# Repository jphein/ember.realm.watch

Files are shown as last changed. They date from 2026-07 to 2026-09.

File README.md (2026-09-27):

# Ember

A local-first voice assistant satellite whose screen is a hearth.

Ember is an ESPHome device on a cheap 2.8" ESP32-S3 touchscreen, wired to a Home
Assistant Assist pipeline that never leaves the LAN. You tap the screen, speak,
and a dragon lying in the coals answers you. The fire's temperature *is* the
state machine — there is no status text, no spinner, no "listening…" label. When
Ember is thinking, the fire draws up into a column. When it speaks, the flames
chase the words. When the backend is unreachable, the coals go grey and the wyrm
goes to sleep.

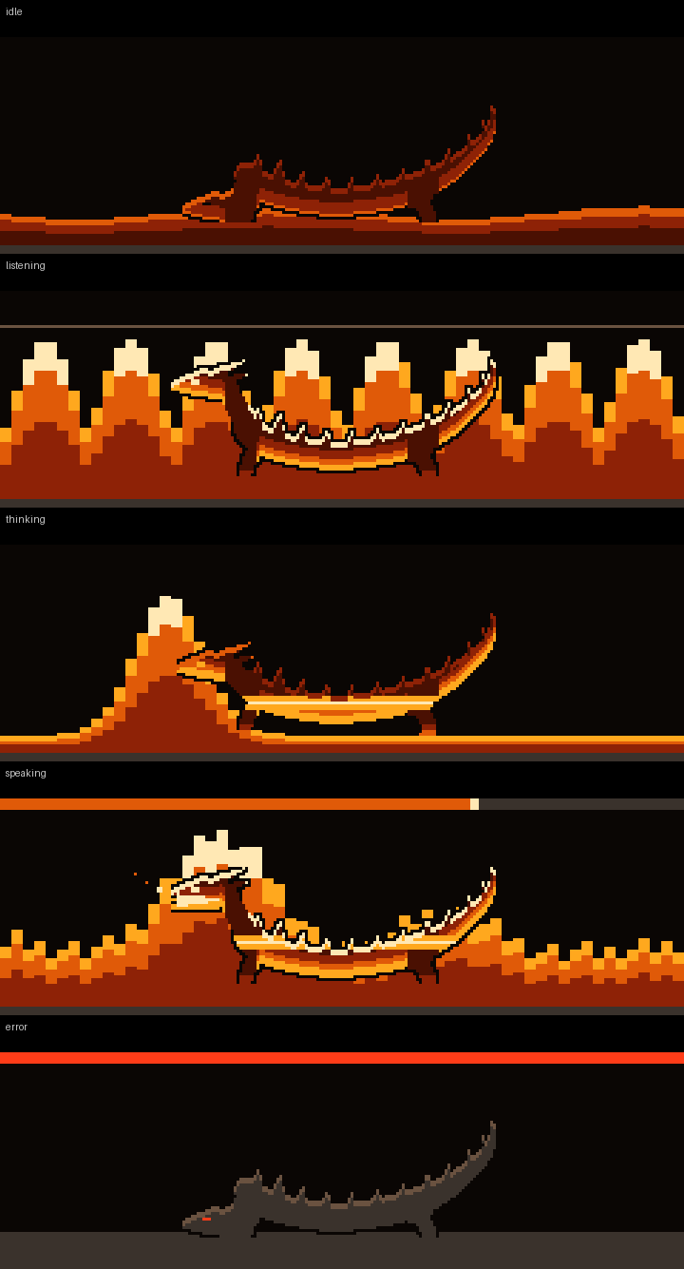
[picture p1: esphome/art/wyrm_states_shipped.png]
The hearth-wyrm across assistant states


*Top to bottom in the file: idle, listening, thinking, speaking, error. The wyrm
is shaded at render time from the live fire palette, so it rides the
ember → amber → gold → white-hot ramp rather than being a baked sprite.
`esphome/art/dragon_in_fire.png` additionally shows the `guttering` and
`daylight` variants.*

---

## The pipeline

Everything runs on the home network. No cloud STT, no cloud LLM, no cloud TTS.

```mermaid
flowchart LR
    T["👆 tap the screen<br/><i>no wake word</i>"] --> E["Ember satellite<br/>ESP32-S3 · ES8311 codec"]
    E -- "16kHz mono mic" --> HA["Home Assistant<br/><i>familiar-ember</i> pipeline"]
    HA -- STT --> V["vosk"]
    V --> X["LiteLLM<br/><b>ubox0</b>:4000<br/><i>not optional</i>"]
    X --> L["Qwen3.6-35B-A3B<br/>llama.cpp on <b>familiar</b>:8091"]
    L -- TTS --> P["Piper<br/>en_GB-cori-medium"]
    P -- "audio stream" --> E
```

| Stage | What serves it |
|---|---|
| Wake | **Touch.** No wake word — deliberate, see below |
| STT | vosk, on the HA host |
| Conversation agent | Qwen3.6-35B-A3B (UD-Q3_K_XL) under llama.cpp on the `familiar` host, port 8091 — reached **through LiteLLM at `ubox0:4000`** |
| TTS | Piper, voice `en_GB-cori-medium` |

> ⚠️ **LiteLLM in that chain looks like needless indirection and is not.** Home Assistant's
> conversation integration cannot send `chat_template_kwargs`, and Qwen3.6 needs them. Point HA
> straight at `familiar:8091` and it connects fine and *behaves wrongly* — the failure lands in
> the model's **output**, not in the connection, which is about the most expensive place for it
> to land. `chat_model: ember` is a LiteLLM alias, not an upstream model name.

**Why touch and not a wake word.** The mic and speaker share a single I2S hub on
this board and there is no AEC. Continuous wake-word listening on shared
hardware fights the playback path for the same peripheral; tap-to-talk sidesteps
the whole class of problem. It also means Ember cannot be triggered from across
the room by the television.

**Warm replies land fast only because the prompt prefix is byte-stable**, letting
llama.cpp reuse its KV cache — a warm turn re-prefills **27 tokens (~0.4s)** out of
6,258. Anything that renders differently between turns truncates the cache there and
re-prefills everything after it, *including the whole conversation history*. Measured
per-request with `prompt eval time`, not wall clock.

Until 2026-07-31 the Environment State block ended in `{{ now() }}` at **microsecond**
precision, so the prompt was byte-unique on every request and every turn paid ~1.0s for
it. Coarsening it to the hour, plus deleting a 1,712-token column of a stringified HA
sentinel, took a warm turn from **1,023 ms → 408 ms** and a cold one from
**6,024 ms → 4,771 ms**. See [`docs/home-assistant.md`](docs/home-assistant.md) §6.3 —
it also records the reasoning that made the earlier fix look complete when it wasn't.

> ✅ **The prompt is now in this repo:**
> [`homeassistant/prompts/ember-system.md.j2`](homeassistant/prompts/ember-system.md.j2),
> deployed with `homeassistant/tools/ember-prompt.py --deploy` (live, no HA restart).
> It previously existed *only* in Home Assistant's `.storage` — untracked and unbackuped,
> which is exactly how the last fix's rationale survived while its numbers rotted.
> `ember_persona.yaml` still supplies only the 255-char live-tweak field that HA's
> `input_text` helper can express.

---

## Three operating modes

**Normal** (speech + chimes) → **No talking** (chimes only) → **Hush** (silent). Monotonic:
progressively quieter, and nothing else varies. Conversation works fully in all three and the
reply still displays on screen — only what leaves the speaker changes.

The gate is the existing 10 ms audio watchdog declining to lift protection it already asserts,
using the display's own speech predicate — so the thing silenced is exactly what the screen
calls speech, and the two cannot drift apart.

> ⚠️ **Hush changed meaning.** It used to mean *"do not listen to me"* and gated the talk
> gesture; it now means *"do not make noise"*. The microphone is unaffected in every mode. If
> you find a dashboard tile, icon or doc implying otherwise — `mdi:microphone-off` is the tell
> — it is stale, and it was true once. The mode select belongs beside Hush wherever Hush
> appears, because Hush as a view can only reach Normal and Hush, so "No talking" would
> otherwise be unreachable from Home Assistant.

`op_mode` is the value that persists; the select and the Hush switch are lambda views over it,
republished at boot. Before that, a device rebooted while quiet came back genuinely Hush with
the select cheerfully reporting "Normal" — found by power-cycling the real device, not by
reading the config.

---

## The two knobs on the device itself

A short press anywhere raises an overlay carrying **both** audio controls, as a pair that reads
*how loudly it speaks / how well it hears*:

| | Range | Readout |
|---|---|---|
| **Volume** | 0–100% in 5% steps, wrapping at the top | 20 hearth stones, one per 5% |
| **Mic gain** | **0–42 dB in 6 dB steps** | **8** hearth stones |

⚠️ **The 6 dB step is the hardware's, not a taste.** The ES8311's ADC PGA is a 3-bit field in
REG16 with exactly eight legal values — 0/6/12/18/24/30/36/42 dB — so nothing between them is
representable, and a continuous slider would report a setting the codec cannot hold. **The stone
count is the hardware's resolution**, which is why the gain row draws eight where volume draws
twenty: the readout must not imply a precision that does not exist. The first lit stone is 0 dB,
because 0 dB is a real setting and not "off". Exposed to Home Assistant as
`number.ember_satellite_mic_gain`.

Setting it writes REG16 directly *as well as* calling `set_mic_gain()`. The setter only assigns
a member — the driver writes the register once, in its own `setup()` — so calling the setter
alone would change nothing until the next boot, which presents exactly like a control that does
not work.

The same asymmetry bit the *restore* path, and it is worth knowing about if you add another
persisted number here: `TemplateNumber::setup()` calls `publish_state()` and never `control()`,
so a restored value never runs its set action. Set 12 dB, reboot, and HA would read 12 while the
PGA sat at the compile-time 36 — **and the one value immune to the bug was the default, which is
what anyone would test with.** There is now a dedicated `on_boot` trigger that pushes the stored
value back *through* the number, so REG16 keeps a single writer, and it was verified by reading
the register back rather than by inference.

Because that asymmetry has now bitten twice, the agreement is measured rather than assumed: a
60 s check reads REG16 back and publishes `sensor.ember_satellite_mic_gain_codec` (what the chip
holds) and `binary_sensor.ember_satellite_mic_gain_desync` (`problem`, ON when they disagree).
**A failed I²C read leaves both untouched rather than reporting a mismatch it cannot see** — so
"no problem reported" is not the same as "verified in sync". Details in
[`docs/home-assistant.md` §6.6](docs/home-assistant.md#66-hearing-mic-gain-and-the-entity-that-can-call-the-dashboard-a-liar).

Two deliberate trades, both reversals of earlier decisions:

- **The fire is hidden while the overlay is open.** Two controls with touch-sized targets do not
  fit in the scroll band alone, so the overlay grew into the flame band. The targets are 56 px
  ≈ 10.3 mm rather than shrinking below the ~9 mm minimum: five seconds of hidden fire beats a
  target you miss. Mode 1 keeping the fire alive had been a deliberate choice, so this reverses
  a decision rather than filling a gap.
- **The gain buttons are silent where the volume buttons chime.** Volume earns a tone because it
  is the one control that cannot be judged visually — the tone *is* the readout. A tone for mic
  gain plays out of the **speaker** and says nothing about how well the **microphone** hears:
  acknowledgement dressed as measurement. The overlay also stops short of the telemetry band, so
  the live dBFS meter stays visible while you adjust — and a chime would be captured by the very
  mic being read and spike the number.

---

## Hardware

An **LCDWIKI/QDtech ES3C28P**, sold as a "Hosyond 2.8in ESP32-S3 Touchscreen".

| | |
|---|---|
| MCU | ESP32-S3 N16R8 — 16MB flash, 8MB octal PSRAM @ 80MHz |
| Display | 240×320 ILI9341V over SPI, driven by `mipi_spi` at 40MHz |
| Touch | FT6336G capacitive |
| Audio | ES8311 codec — analog differential mic, FM8002E BTL amp to an external speaker |
| Extras | microSD slot, WS2812 |

**The pinout in this repo is traced to the manufacturer's schematic, not copied
from community tables.** Several published tables for this board are wrong. The
YAML carries a comment at every non-obvious choice explaining what it is and why
the obvious value fails — those comments are the real documentation for this
project and should not be stripped.

---

## Settings that look like mistakes (and aren't)

Every row here cost real debugging time. Change one only after reading the
comment at its point of use in the YAML.

| Setting | Why it looks wrong but isn't |
|---|---|
| `i2s_din_pin: 6` / `i2s_dout_pin: 8` | The silkscreen names I2S data pins from the *codec's* perspective, so most published tables are inverted. Confirmed four ways, including the vendor's own shipped source. |
| `use_microphone:` omitted | In ESPHome's es8311 driver that flag enables a *PDM digital* mic. This board's mic is analog-differential into MIC1P/MIC1N. |
| `data_rate: 40MHz` | `mipi_spi`'s base ILI9341 model declares no data rate, so it defaults to **10MHz** — which made full frames take 141ms instead of 60ms. |
| GPIO18 left unconfigured | It's CTP_RST. Both a `reset_pin:` and a gpio `output:` broke touch init — ESPHome's `ft63x6` asserts reset then reads the chip ID with zero delay, ignoring the datasheet's `Trsi >= 300ms`. The FT6336G has a 3k internal pull-up, so leaving it alone is correct. |
| `bits_per_sample: 16bit` on the mic | ESPHome's default is **32bit**, which silently mismatches the 16-bit codec and produces a dead mic. This is the actual bug in the only other published config for this board. |
| `channel: left` | Cosmetic. ES8311 REG 0x44 defaults to "ADC + ADC", duplicating the mono ADC into both slots, and no driver writes that register — so left and right are equivalent here. |
| `auto_clear_enabled: false` | Required by the banded partial redraw. `clear()` would dirty every pixel before the lambda even runs, throwing away the whole optimisation. |
| `buffer_duration: 500ms` | The measured fix for choppy playback — a 16s utterance went 45.8% → 100.7% delivered. **Do not lower it.** Not to be confused with `timeout: 500ms`, which is a different knob entirely. |
| `logger: level: DEBUG` | The i2c bus scan prints at CONFIG level, and in ESPHome's ordering CONFIG is *more* verbose than INFO — so `level: INFO` silently hides the scan results. |

Deeper write-ups live alongside this table:

- **[docs/audio-pop.md](docs/audio-pop.md)** — the audible pop on audio start, and
  **how it was resolved.** Read the coda if you touch the audio path. The headline:
  for three rounds the protection sat *behind* the transient it was meant to cover,
  so every A/B test was measuring a knob that fired after the event. The file has
  now been wrong in three distinguishable ways and each error was caught by a
  different method — that chain is deliberately preserved rather than replaced with
  the conclusion. Includes one **accepted** hazard whose symptom is a clipped first
  syllable, not a pop, and which would therefore be blamed on TTS.
- **[docs/enclosure.md](docs/enclosure.md)** — verified board geometry off the vendor
  drawing, the official STEP model, and why **no printable case existed for this board
  anywhere** before this one. The constraint that catches everyone: the touch glass is the
  full 50 mm PCB width, so you cannot clamp the long edges.
- **The YAML's own header** — four architecture notes on why there is no LVGL,
  how the banded partial redraw works, and why the fire renders row-major.
  `>>> Do not "simplify" the fire back into per-column filled_rectangle calls.
  It looks identical and costs several times more. <<<`

### Calibration knobs

These are guesses until measured on *your* hardware, and are marked in-file:

| Knob | What to do |
|---|---|
| `db_floor` / `db_ceil` | Speak normally ~40cm away, watch `sensor.mic_rms`, set floor just under room noise and ceiling just over speech. Too narrow and the meter pins; too wide and it looks dead. |
| `tts_ms_per_char` | Tunes the speaking animation's guess at utterance length. |
| `cpl_body` / `cpl_sm` | Characters-per-line for the two text sizes. |

---

## Chimes

`esphome/sounds/` holds eight 16kHz mono tones plus `generate_chimes.py`, which
produced them. Struck-glass synthesis — inharmonic partials, exponential decay,
4ms raised-cosine attack, warm F-pentatonic so any two are consonant. `error` is
the one deliberate dissonance.

16kHz is not a compromise: the highest partial is 6.79× the fundamental and the
highest fundamental is C5 (523.25Hz) → 3552Hz, comfortably under the 8kHz
Nyquist. Rendering at 44.1kHz and letting the device resample would be strictly
worse — it would put a resampler in an audio path that is deliberately a
straight line.

Regenerate with `python3 esphome/sounds/generate_chimes.py`.

> **`chime_listening` is generated but deliberately never declared.** 1.4s of
> tone out of a speaker sharing one I2S hub with the mic, with no AEC, would
> make HA's VAD end the utterance before you finished speaking. The symptom
> would read as an STT bug and send you looking in entirely the wrong place.
> Don't wire it. The reasoning is repeated at the point of use in the YAML.

---

## The hearth-wyrm

`esphome/art/dragon.py` generates the dragon. It is **not** an ESPHome `image:` —
it emits per-row run-length **spans** as C tables, because:

- The flame band renders row-major and must tile every row exactly once
  (`auto_clear_enabled: false`). An `it.image()` blit would be a second write
  over pixels the fire already wrote; spans composite into the existing
  run-length classifier and preserve write-once.
- Spans carry no colour, so the wyrm is shaded at render time from the live
  fire-temperature palette. It rides the heat ramp, honours the daylight theme,
  and brightens with state. A baked image cannot do any of that.
- The animation is procedural — head lift, glow, travelling rim light — so it
  never visibly loops the way frame-cycled art does.

Deterministic, no RNG. Regenerate with `python3 esphome/art/dragon.py`, which
rewrites `dragon_spans.inc` (pasted into the display lambda) and the preview
PNGs.

### Falsifying a flame-band change before you flash it

`esphome/art/dragon_harness.cpp` compiles the `paint_flame` body against stubs and
checks the two things no compiler can: that every row of the band is written **exactly
once**, and that nothing writes outside `y188..263`. It also reports **runs/frame** and
**px/frame** per assistant state and dumps `wyrm_<state>.ppm` so a change can be looked
at rather than reasoned about.

```bash
g++ -std=gnu++20 -O2 -Wall -Wextra -o /tmp/dh esphome/art/dragon_harness.cpp && /tmp/dh
```

Two things to know before trusting a pass, both explained at length in the file's
header. `FAIL negative-control: …covered 0 times` **is expected** — it is the harness
proving its own tiling check can fail. And the tiling check **cannot** catch an over-tall
`MAXH`: the fuse rows are painted before the fire logic, so a too-tall flame is silently
clipped flat while every pixel remains covered exactly once. If you touch `GRATE` or
`MAXH`, look at the PPM.

It mirrors the lambda in `ember-satellite.yaml`. Change one, change the other — it is
only worth running while it is the same code.

> ⚠️ **It currently is not, and the divergence has been measured: 8 lines, YAML ahead.**
> Seven of them are the two `static_assert`s on `CW` and `NC`; one is `if (silenced) jaw = 0;`.
> That is not accidental drift — the harness's own comment says of those asserts *"a fix belongs
> in the yaml … Flagged to the firmware owner rather than changed here"*, and the fix was made
> there and never brought back. **A deliberate one-way handoff, completed on one side.**
>
> The consequence is worth stating because it is the wrong way round: the guards on `NC`/`CW`
> now live **only in the copy that cannot be host-compiled**, and are **absent from the harness**
> — which is exactly where someone tried `NC = 80` and smashed the stack. *The assert that would
> have caught it at compile time is missing from the only place it could have fired.*
>
> **Half of this is now mechanical.** `esphome/tools/check_art_sync.py` compares the ~700 lines
> of generated span tables by value and fails a commit if they disagree. The ~250 lines of
> painter *logic* stay manual on purpose — the two copies are legitimately different text
> (`it.` stubs against `id(...)`), so a diff would be noise. That half closes when #10 removes
> the duplicate outright.

---

## The enclosure

**There was no printable case for this board.** Not under `ES3C28P`, not under any reseller
alias, not on any model site — because the ES3C28P vents its microphone through the *front*
face, and every CYD-derived shell that physically fits has no port there. For a voice
satellite that is decisive, and it is not a cutout you can add to somebody else's STL from
the outside.

So there is one now. **Four parts, none needing supports**, in [`enclosure/`](enclosure/):

> ✅ **All four are printable.** Two of them were not, earlier, and both fixes are in:
> `ember-stand-base.stl` was **1.40 mm too deep** and could not close the sealed chamber
> (`89001ea` — the plate carried a hardcoded copy of a wall that had since been *derived* and
> moved, and the literal did not follow); and `ember-stand.stl`'s speaker-wire pass was blocked
> by a skin of the tape pad, leaving a 0.40 mm slit where a 1.2–2.0 mm lead has to go
> (`338a900` — clear aperture now **28.69 mm² of 30**, up from 2.37). Details and the
> reprint/relabel notes are in [`enclosure/PRINT-SHEET.md`](enclosure/PRINT-SHEET.md).
>
> ⚠️ **If you printed a back shell before `86748c6`, its button caps are on the wrong
> switches** — the switch identification was inverted when it stopped being a typed literal.
> `ember-front-bezel.stl` has been printed and its dimensions look right, and is unaffected by
> all of the above. Nothing has been assembled yet.

| | |
|---|---|
| `ember-front-bezel.stl` | front face down. Carries the ⌀2.40 mm mic port, the screen window, a debossed honeycomb and the hearth-wyrm |
| `ember-back-shell.stl` | back face down. Two printed-in-place hexagonal button pads on living hinges, 15.00 and 10.00 mm across the flats |
| `ember-stand.stl` | bottom face down. A 15° cradle that **is** the speaker cabinet, with finger scallops reaching the buttons |
| `ember-stand-base.stl` | flat. Closes the chamber |

### The back face has labels now, and they are drawn rather than set

Debossed into the back like everything else on a bed face: **`SD`** beside the card slot,
**`MIC`** beside the relief, **`VOL`** on the large button cap, an **IEC 5009 power symbol** on
the small one, and a **connector strip down each flank** naming the ports behind it. Same depth
as the bezel motif — **three layers**, one named layer count shared by both faces.

> ⚠️ **The set is variant-dependent now, and one label was deleted rather than reworded.** The
> desk shell blocks the `BAT` flank opening; the mobile blocks `BAT` and `SPK`. **A suppressed
> opening suppresses its label** — the rule in the source is *"no label may name an opening that
> is not there"*, and it is enforced by cutting the labels from the same set that cuts the holes,
> so the face cannot name a port that does not exist. Dropped, not re-captioned, because a
> moulded-in name is wayfinding: **an opening with nothing behind it is invisible until someone
> looks, but a label beside solid plastic actively sends a person hunting for a port.** The
> surviving labels keep the positions they were packed into against the *nominal* spans, so
> nothing shifts between variants.

**They are a stroke font, not a typeface, and that is the whole point.** Each glyph is a
centreline path swept at a fixed **0.90 mm** groove width — the same nozzle floor the wyrm mark
asserts. With an outline font the stroke width is a *consequence* you can measure afterwards and
hope about; here it is an **argument**, set directly and checkable. On the button caps that
works out to a stroke/height ratio of **0.19**, heavier than any real font's Bold; on the flat
back, at the larger size, it is **0.14**.

⚠️ **Two sizes, and the split is forced rather than stylistic.** The large cap is 13.27 mm
across the flats, which caps a three-letter label at **h 3.80**. The flat back has room for
**h 5.50**, and `SD` *needs* it: at **h 5.10 the S's upper counter pinches to 0.843 mm** against
the 0.90 floor. **Shrinking a glyph does not shrink it uniformly** — the stroke is pinned at the
nozzle and everything else scales, so it is the **counters** that get eaten first. Using the cap
size everywhere would have put an unprintable `S` on the part; using the flat size everywhere
would not fit on the cap.

The power symbol's gap is **derived, not styled**: the material between a ring end and the bar is
`R·sin(gap/2) − 0.90`, so clearing the 0.90 floor needs **≥ 83.6°**, and it ships at 84. **A
conventional 60° break measures 0.45 mm and prints as a closed ring with a smudge in it.**

> ⚠️ **Every label is mirrored in X, and this is the one that ships backwards if nobody writes
> it down.** The back face is seen from **−Z**. For a viewer there with +Y up, their right-hand
> direction is `forward × up = (0,0,1) × (0,1,0) = (−1,0,0)` — so **model +X runs to their
> left.** Glyphs are authored in reading space and mirrored on placement. The wyrm mark on the
> front bezel is *also* mirrored, but for art-direction reasons, so **it is not precedent and
> copying its sign would prove nothing.** `enclosure/tools/slice_svg.py` applies the same mapping
> independently, so slicing the exported STL is a genuine check: if the sign were wrong the text
> would come out backwards there.

**`ember_case.py` is the artifact; the STLs are output** — regenerate them, don't hand-edit
them. It is build123d on OpenCASCADE, which is the point: the vendor's STEP model can be
*imported* and every part checked against it by boolean subtraction, so every board dimension
is measured rather than transcribed from a datasheet table.

```bash
cd enclosure
python3 -m venv cadenv && ./cadenv/bin/pip install -r tools/requirements.txt
./cadenv/bin/python ember_case.py            # STLs + clearance check + geometry asserts
./cadenv/bin/python tools/make_renders.py    # the site figures
```

- **[`enclosure/README.md`](enclosure/README.md)** — building from a fresh clone, what the two
  kinds of check actually do, and the parameters most likely to need a second print.
- **[`enclosure/PRINT-SHEET.md`](enclosure/PRINT-SHEET.md)** — orientations, slicer settings,
  fasteners, assembly order. Also served as a page at
  [`docs/print-sheet.html`](docs/print-sheet.html), because that is the one document you read
  while a printer is running.

> **The two lessons this part of the project keeps teaching.** *A test that cannot fail is not
> a test* — the clearance checker returned a confident `CLEAR` for a while because the vendor
> solid and the parts were in disjoint coordinate frames, so every boolean returned empty.
> There is now a permanent self-test that deliberately sinks a bezel into the board and must
> report **1512.804 mm³** (the figure tracks bezel geometry — it was 1467.842 until the #41
> boss flare; re-recorded 2026-08-25, see `enclosure/README.md`). And *a boolean cannot see
> occlusion* — the stand covered a fifth of
> the screen, then buried both buttons, without ever intersecting anything. Both were found by
> rendering the thing and looking at it.
>
> The first lesson landed a second time, on the mesh check. The repo asserted *"all parts
> watertight, 0 non-manifold edges"* on a check that imported each STL with build123d and
> counted boundary edges — and `import_stl` returns a single `Face` with **zero edges and zero
> volume**, so the count was zero because there was nothing to count. The true figures, printed
> on every build: **three parts watertight; `ember-front-bezel` carries 3 non-manifold edges**
> in a valid solid with zero boundary edges, a coplanar-seam artefact from the wyrm mark's
> stacked row-spans that slicers repair. It is recorded as a number rather than a threshold, and
> raising it to make a build pass is explicitly forbidden.

---

## The mobile variant — one 18650, and the front never changes

There is a **battery build**, and it is a *backpack rather than a redesign*:
[`enclosure/ember_mobile_case.py`](enclosure/ember_mobile_case.py), issue
[#44](https://github.com/jphein/ember.realm.watch/issues/44). The bezel is the desk case's part,
unmodified — same STL, same four M3×12, same 5.34 mm of thread — and the board is held by the
**same joint at the same plane**. Two parts are new.

> ⚠️ **Verified in CAD, nothing completed, nothing wired.** Both parts pass every check the desk
> parts do — watertight, **0 boundary and 0 non-manifold edges**, **0.000 mm³** against the
> vendor board solid, with displaced controls at 1261.0 / 199.1 / 1884.8 mm³ so the probe is
> known to be *able* to fail. That is a geometry result. The cell is a phantom, and whether the
> cover's top edge gaps is a question only a test print answers.
>
> ✅ **The protection strip is fully measured now** — 21.50 × 4.50 × 2.50 plus a 90.00 flat
> assembly, all JP-calipered. It was the longest-standing estimate in the design and there are no
> placeholders left.
>
> One cover print was **started and cancelled at 2 %** — the strip's length had gone in as a
> 20.0 mm eyeball estimate carrying ±2, and at 20.0 the locating ribs sat **1.5 mm too close
> together for a 21 mm strip to drop between them**. Re-measured at **21.50**. *(Those ribs no
> longer exist — the strip has since moved out of the chin band entirely, and the pocket, its ribs
> and its detents went with it. The print was still cancelled for the right reason.)* The
> flag on that estimate is why the cancel cost 2 % rather than a whole part; the lesson is that a
> number carrying ±2 was allowed to set a feature whose clearance is smaller than ±2.

| | |
|---|---|
| `ember-mobile-midframe.stl` | back face down. The old back shell **plus features and (almost) nothing removed** — brow, speaker bond plateau, driver locating groove, cell-lead pass, two screw bosses, a +Y cooling field. It *does* drop two hex rows, at the chin screw — see below |
| `ember-mobile-back.stl` | **outer** face down. The cell trough, the spring and contact pockets, the speaker grille, the failure vent, the protection pocket |
| `ember-front-bezel.stl` | unchanged — reused bit-identical |

| | Mobile | Desk |
|---|---|---|
| Envelope | **55.90 × 91.90 × 39.00 mm** — *Y identical to the desk case* | 55.90 × 91.90 × 17.40 mm |
| Cell | 1 × **bare flat-top 18650**, user-swappable | — |
| Charge | onboard TP4054, 290 mA → **15.8 h** | — |
| Access | **2 × M3×22** on one lane + the cover's box section | — |

**Width cannot move** (the bezel didn't) — and after three revisions of *not* closing, **length no
longer grows either.** `MOB_OY1 == OY1 == 88.95`, asserted exactly: the backpack is the desk slab's
footprint with depth behind it and nothing else.

> **JP: "no litle lip in backpack figure it out pls."**

It had been 3.05 mm longer, then 1.32, then 1.73 — each for a reason that was correct at the time
(the coil spring; then the corner fillet the coil had been paying for by accident; then the strip's
own housing). What closed it was **moving the conflict instead of reshaping around it**: `CELL_WALL_X`
given its own name, the divider to 1.60, the driver nudged 1.078 to land *centred*, and a plan-corner
roll of **0.30** — which is not a chosen radius but the **seat guarantee**, since above 0.30 a cell
with no roll of its own cannot seat. JP suggested ~0.5 from the render; **the bound won.**

The assert guarding it fails in the vocabulary the requirement was given in: if either half breaks,
the message says **"the lip is back"** in those words.

The cover **deliberately stops short of the chin** so a battery door cannot bury the only usable
button or the USB-C socket — a *reachability* constraint, which is the class of fault no
clearance check sees and which this project has already filed once.

The interior closes exactly: **51.50 = 19.40 bore + 2.00 divider + 30.10 rim**, where that
divider was **one wall doing two jobs** — the cell trough's inboard wall *and* the sealed speaker
chamber's −X wall — because two walls do not fit.

> ⚠️ **That wall has now held six different positions**, ending whole again plus a **double separator
> wall JP designed himself** — a partial wall plus a stepped full wall, 0.90 thinning to 0.50 beside
> the strip. Each of the six has a stated reason and a measurement behind it; a design that moves six
> times under measurement is not indecisive, it is one where nobody was allowed to guess.
>
> ⚠️ **And a correction this README carried:** it reported one opening at 584 mm². There were two —
> the check was printing the divider's *cross-section* (39 mm²) where the opening is the face the wall
> *vacated* (869 mm²), **off by 22× in the one number the owner judges the trade by.** *A wrong area is
> worse than no area, because it gets trusted.* Both are closed again now; the −X opening measures
> 0.000. Details in [`docs/enclosure-mobile.md`](docs/enclosure-mobile.md) §7c.
>
> The front-air cost is real and it moved: **−11.1 %**, not the −1.2 % this file quoted for three
> revisions — the separator wall and the driver's re-measured 27.5 width both take volume out.

### Three findings worth reading even if you never print it

**⛔ The board has no protection IC at all, and now that is not a guess.** It was searched for —
`DW01`, `FS312`, `8205`, BMS, over-discharge — and then settled against the
[vendor schematic](docs/vendor/ES3C28P_Schematic.pdf): the battery area is exactly two blocks,
charge management and a level divider. `BAT` goes **straight to the cell**. And *"it browns out
first"* is the wrong reading — with a bare cell the only floor is the regulator's dropout, so the
device stops working around 3.4 V and **keeps draining ~9 µA through that divider**. A cell left
flat goes to zero and does not come back. Hence the 1S protection-strip pocket, which is
**required equipment rather than a nicety**.

**⚠️ A flat-top cell carries no polarity information, so the keying had to be deleted.** The
previous revision had real mechanical reverse-insertion protection — a ⌀7.00 aperture that a
protected cell's *raised* button passes and a flat can-face does not, blocking a reversed cell by
144.6 mm³. But JP uses bare cells only, and on a bare flat-top **both ends are the same shape**:
any aperture that stops a reversed cell stops a correct one. It is not a matter of a cleverer
profile — *the information is not present in the geometry*, and left in, the feature would have
rejected the only cells its owner has. It was removed rather than commented out. What replaces it
is `+`/`−` debossed into the cell bay — deliberately **not** mirrored positions, because one end
has a nickel leaf in front of it and the other does not. **That is weaker, and it is not
going to be called protection.**

**A vent with no straight line through it.** A lithium cell in a sealed plastic box is the one
thing here that can hurt someone. The bay vents through **four labyrinth units** in a side wall —
each an inner slot and an outer slot offset by a 1.20 mm rib, joined by a 0.60 mm band, leaving
0.80 mm of skin standing at each face. Throat **16.56 mm²** against an assumed 9.42 mm² of vent
port on the cell's own cap; worst outer slot **36 % obstructed**, with a control on a
deliberately drilled wall at 0.0 %. Every cut runs its long axis along the *print* Z, which is
why the vent is in a side wall and not the floor.

> **And that check was wrong first, in the most dangerous possible way.** The throat probe swept
> half a millimetre of open air outside the part and half a millimetre of bay interior, and read
> **52.80 mm²** — 3× the analytic figure. Worse: **with the connecting band deleted entirely it
> would still have read 36.00 and passed.** An assert that cannot fail, inside the check written
> to retire the design's biggest risk. It surfaced only because the measured number beat the
> calculated one by 3×, which is a defect signal and not a win. Standing rule that came out of
> it: *a probe's extent is the feature's extent — a margin "to be safe" is not safe.*

There is also a **WS2812 glow window** (two hex cells behind a 0.80 mm membrane, cut from the
wall's inner face so the outside stays flat and the hexes are invisible until lit), whose size
was pinned this week by a **cross-part regression**: it was written as "the same cell as the
grille", and when the *desk stand's* grille was re-parameterised 4.50 → 4.75 mm for printable
webs, this window **in a different part** silently inherited the change and stopped fitting its
cavity band. The export gate refused to write the STL. *A window's size is set by the band it
lives in, not by another part's lattice.*

### ⚠️ It did not dock, and the *stand* is what had to change

The backpack is meant to sit in the desk stand. **It didn't fit** — and nothing had noticed,
because **the check for it had never actually executed.** Its first real run reported
**121.784 mm³** of interference, cover against the stand's rear top edge, **pre-existing on `main`
and worse there.** A check that has never fired looks exactly like a check that passes.

The cover could not be the fix: the interference is **mid-height on its chin end face and full
width**, not a corner a bevel could shave, and its 2.20 mm wall with the leaf's kerf behind can
give up 0.60 and no more. So the stand takes a **13.00 × 4.40 relief** on its rear top edge, sized
by **bisection against the real docked stack** (96.6 → 28.8 → 7.8 → **0.000 mm³**). The check is a
hard zero now. That is 250 mm³ off a part of over 100 cm³.

> ⭐ **The part that had to give was the one whose assumption was oldest.** The stand's slot was cut
> for a 17.40 mm slab, before a backpack existed to be docked into it, and every later part
> inherited that opening as if it were a fact about the world. It was a fact about a decision.
> *When two parts cannot both be right, change the one carrying the stalest premise — not the
> newest one.*

⚠️ **The stand is at r5 and needs reprinting if you dock a backpack.** Desk-only builds are
unaffected in geometry.

```bash
cd enclosure
./cadenv/bin/python ember_mobile_case.py           # both STLs + 17 checks; writes nothing on failure
./cadenv/bin/python tools/make_mobile_renders.py   # the site figures -> site/renders/
```

- **[`docs/enclosure-mobile.md`](docs/enclosure-mobile.md)** — the build reference: BOM, assembly
  order, wiring, print notes, the full measured table, and every soft number flagged as soft.
- **[`docs/vendor/README.md`](docs/vendor/README.md)** — the archived schematic and what it settles.

**The deliberate trade, for the record.** An in-case TP4056 would charge in 4.6 h instead of
15.8, and it **does not fit** — the free compartment is 30.10 × 13.40 against the module's
17.00 mm short axis, and its phantom is kept in the file so the boolean reports **299 mm³ of
interference** every run rather than a comment claiming as much. Restoring it costs the 5.90 mm
that switching to bare cells saved, which is the same length the protection strip now occupies.
The case stays as short as it is: with bare cells the missing protection is the sharper gap, and removable
cells can be fast-charged in an external bay charger. That **reversed** an earlier decision, and
it is recorded rather than quietly absorbed.

> **The largest unresolved risk is thermal, not mechanical.** Most of the rear vent field is
> refilled by the speaker's bond plateau, and what survives vents into a **closed** compartment
> rather than to open air — compartment → remaining hexes → board cavity → side channels →
> outside. The desk case vents straight to the room. It is flagged rather than "fixed" with
> invented vent geometry.

---

## Repository layout

```
esphome/
  ember-satellite.yaml       the device. ~3700 lines, and the comments are the docs
  secrets.yaml.example       copy to secrets.yaml — three keys, never committed
  sounds/                    8 chime WAVs + generate_chimes.py
  art/                       dragon.py, dragon_spans.inc, preview PNGs
                             dragon_harness.cpp — host falsifier for the flame band
homeassistant/
  packages/
    ember_backend_health.yaml  is the local LLM actually reachable?
    ember_persona.yaml         live persona tweak field, editable from HA
    ember_announce.yaml        script.ember_announce — the right herald
  dashboards/
    ember-hearth.dashboard.json  the Ember control panel (lovelace)
  tools/
    build_ember_dashboard.py     authoritative regen path for the dashboard
    deploy-ha.sh                 push packages to the HA VM + reload
enclosure/
  ember_case.py                THE ARTIFACT — build123d; the STLs are its output
  ember_mobile_case.py         the battery variant; imports every number from above
  ember-*.stl                  six printable parts, regenerated not hand-edited
  PRINT-SHEET.md               orientations, slicer settings, assembly order
                               (desk parts only — see docs/enclosure-mobile.md §11)
  README.md                    building from a fresh clone; what the checks do
  tools/make_renders.py        the desk figures -> site/renders/
  tools/make_mobile_renders.py the mobile figures -> site/renders/
  tools/svg_util.py            sections, projection, self-measuring dimensions
  cadenv/                      the whole CAD toolchain, gitignored AND stignored
site/                        SOURCES for the project site
  index.src.html               hand-edit this
  build.py                     -> docs/, inlining art and copying chimes
  build_print_sheet.py         enclosure/PRINT-SHEET.md -> docs/print-sheet.html
  renders/                     enclosure figures, GENERATED by make_renders.py
  ember-art-web/og_card.py     regenerates the social preview card, and refuses
                               to ship a known-wrong engine name
docs/                        the GitHub Pages root
  index.html                   GENERATED by site/build.py; do NOT hand-edit
  print-sheet.html             GENERATED from enclosure/PRINT-SHEET.md
  assets/                      chimes + og card
  home-assistant.md            the full HA-side guide
  audio-pop.md                 the pop analysis + how it was resolved
  enclosure.md                 board geometry, and the case survey that found none
  enclosure-mobile.md          the battery variant: BOM, assembly, measured table
  vendor/                      the archived ES3C28P schematic + what it settles
  verification.md              the running log of claims that outran their evidence
  version.json                 realm-sigil stamp
```

> `docs/index.html` is **generated**. Edit `site/index.src.html` and re-run
> `python3 site/build.py`. Hand edits to `docs/index.html` are destroyed silently by
> the next build.
>
> `./build-sigil.sh` writes only `docs/version.json` and touches nothing else, so the
> two commands write disjoint files and can be run in either order. See
> [docs/README.md](docs/README.md) for why that wasn't always true.

---

## Build and flash

Requires ESPHome. The config declares `min_version: 2025.11.0` and is verified
against **2026.7.2**.

```bash
cd esphome
cp secrets.yaml.example secrets.yaml   # then fill in the three keys
esphome compile ember-satellite.yaml
esphome upload  ember-satellite.yaml --device ember-satellite.local   # OTA
esphome logs    ember-satellite.yaml --device ember-satellite.local
```

> ⚠️ **`esphome config` is not a build check.** It validates YAML — schema, pins,
> substitutions, jinja — and **never builds the lambdas**. A config with unambiguous
> C++ errors in them returns `Configuration is valid!` and exit 0. Worse, the dump
> **echoes the broken lambda source back at you verbatim**, so it prints the C++ and
> then declares the configuration valid, which reads as though it examined what it
> printed. It round-tripped it as an opaque string. **Use `esphome compile`** — no
> device needed, and it is the step that builds the C++.
>
> ⚠️ **`esphome upload` does NOT compile either.** It ships whatever is already in
> `.esphome/build/`, silently. Always `esphome compile` first, or use `esphome
> run` which does both. Two debugging rounds were lost to flashing a stale
> binary whose symptoms reproduced to the millisecond.
>
> **These two are neighbours and fail the same way**: each is a step you would
> reasonably read as "check it before flashing", and neither compiles anything. Between
> them, a C++ error can survive a validation *and* a flash and first appear as a device
> that does not boot.

Compiling on a workstation is roughly 5× faster than building on the HA host.

First flash has to be over USB (`--device /dev/ttyACM0`); everything after that
can be OTA.

### Verifying the banded redraw

The one test that matters after touching the display code. The YAML's `logger:`
block carries the exact swap to make — it turns on the per-band frame accounting
so you can confirm at most one band repaints per frame.

---

## Home Assistant side

**[docs/home-assistant.md](docs/home-assistant.md) is the full guide** —
prerequisites, deploy, verification, the pipeline internals, and troubleshooting
ordered by how much time each fault costs you. Read it before a fresh install;
roughly half of Ember's HA-side configuration is *not* expressible as a repo file
(add-ons, the conversation agent entry, the Assist pipeline) and that document
enumerates every manual step.

The files under `homeassistant/` are the version-controlled source for config that
lives on the HA host. **This repo is the source of truth**; `deploy-ha.sh` copies
packages to the VM and reloads only the domains that changed:

```bash
homeassistant/tools/deploy-ha.sh --check     # validate only, no SSH needed
homeassistant/tools/deploy-ha.sh --dry-run   # show what would change
homeassistant/tools/deploy-ha.sh             # deploy all three + reload
```

> ⚠️ **The API host and the SSH host are different machines.** The public name
> resolves to the reverse proxy, not the HA VM. SSH there succeeds, `sudo tee`
> writes the packages onto the *proxy*, reports success, and changes nothing in
> Home Assistant. `deploy-ha.sh` keeps the two names separate deliberately and says
> why in a comment — don't "tidy" it. Override with `HA_SSH_HOST` and `HA_API`.

- **`packages/*.yaml`** → drop into your HA `packages/` directory. Reloadable
  without a full restart via `rest.reload` / `script.reload` where applicable.
- **`dashboards/ember-hearth.dashboard.json`** → pushed by
  `tools/build_ember_dashboard.py`, which creates the top-level dashboard if
  absent and then saves the config over the WebSocket API. **The repo is the
  source of truth**; a regen deliberately clobbers UI edits, which is the point.

```bash
export HA_WS="wss://ha.example.com/api/websocket"   # only if the default is wrong for you
python3 homeassistant/tools/build_ember_dashboard.py --dry   # print, touch nothing
python3 homeassistant/tools/build_ember_dashboard.py         # create + save
```

> ⚠️ **`HA_WS` wants the name on the TLS certificate — usually your edge/proxy host, and
> usually with no port.** This example used to read `wss://your-ho…:8123/api/websocket`, and
> that shape fails three ways in a row, each masking the next: `homeassistant.local` often
> does not resolve at all; the LAN name may resolve but serve **HTTPS** on 8123, so plain
> `ws://` reports *"did not receive a valid HTTP response"* — which reads as a protocol fault
> when it is a scheme mismatch; and `wss://<lan-name>:8123` then fails certificate
> verification, because the cert is issued for the public name. The default in the script is
> the edge name for exactly this reason, and it is a hostname, never an IP.
>
> This is also **not** the SSH host. `deploy-ha.sh` copies files to the VM; this script talks
> to the API through the proxy. They are different machines and each tool already uses the
> right one.

Auth resolves in order: `HA_TOKEN` env var → `~/.cache/ha-token-tmp` → a
password-manager lookup. The script needs `websockets` (`pip install websockets`).

Notes that will bite otherwise:

- HA requires a custom dashboard `url_path` to contain a hyphen. Hence
  `ember-hearth`.
- Hand-edit the JSON, and keep `indent=1, ensure_ascii=True` if you ever rewrite
  it programmatically. Any other setting re-encodes every non-ASCII glyph and
  buries a one-tile change in a 300-line diff. This file is ~40% ember-ramp
  glyphs, so it matters more here than usual.
- Card inventory is 100% HA-core card types. The only non-core dependency is
  **card-mod** for the ember palette, and it only injects CSS — if it fails to
  load the cards still render, just unstyled.
- The pipeline → agent/stt/tts/voice tables inside the markdown cards are a
  snapshot taken 2026-07-29. Refresh them if you add or rename pipelines.
- Address the backend host **by hostname**. `familiar.lan` from the HA VM (HAOS
  does not resolve the bare name), `familiar` from a workstation. Never the IP:
  it moved once and the stale literal cost a debugging session.
- Polling the backend does **not** keep it awake, and does not wake it either.
  The host's autosuspend decides on whether the inference lane is loaded, not on
  network traffic. So a failed poll is a true signal, not an artefact of
  measuring.

### Announcements

Always go through `script.ember_announce`, never `assist_satellite.announce`
directly. The raw service sends a `preannounce_media_id` unless told not to, and
Ember *also* plays its own local chime when an announcement arrives — so the
default gives you HA's generic blip followed by Ember's chime, back to back,
which sounds exactly like a firmware bug. `preannounce: false` is not optional,
and the script exists so no future automation has to remember that.

---

## Versioning

The project site carries a [realm-sigil](https://github.com/jphein/realm-sigil)
version stamp — `docs/version.json` plus a `<meta name="realm-version">` tag in
the page, generated from the git hash by `build-sigil.sh`.

The firmware itself is versioned by ESPHome and reported to Home Assistant as the
device's own version. It has no HTTP surface, so it has no `/api/version`
endpoint and does not need one.

---

## Provenance

Ember started life inside a Home Assistant configuration repo and was extracted
into this one with `git filter-repo`, preserving **every** commit that touched it —
`git log -- esphome/ember-satellite.yaml` is the real answer, and it goes back to
the file's first appearance.

Those commit messages are load-bearing. Several are the only record of *why* a
non-obvious setting is what it is, and more than one documents a conclusion that a
later commit overturned. `git log --follow` works across the extraction, including
through `esphome/README.md` → `README.md`.

Read them in order if you are about to change the touch or audio paths. The last
four in particular are a chain of corrections, each one fixing a bug the previous
fix revealed — a debounce that re-armed and cancelled deliberate presses, a
completion chime that destroyed the reply it was announcing, a 250ms timeout
measured off a single fast sample. The final shape (dispatch on release, never
preempt audio that is playing) only makes sense against that history.

## License

AGPL-3.0-or-later © 2026 Jeffrey Pine Hein. See [LICENSE](LICENSE).

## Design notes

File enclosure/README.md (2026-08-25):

# enclosure — building it from source

`ember_case.py` is the artifact. **The STLs are output** — regenerate them, don't hand-edit
them.

## Setup

```bash
python3 -m venv cadenv
./cadenv/bin/pip install -r tools/requirements.txt
```

Nothing CAD-capable is installed system-wide on the workstation this was built on
(no OpenSCAD, no FreeCAD, no slicer), so the venv is the whole toolchain.

**Why build123d rather than OpenSCAD:** it sits on OpenCASCADE, which is what produced the
vendor's STEP file — so the board solid can be *imported* and clearances checked by boolean
subtraction. OpenSCAD cannot read STEP, which would mean hand-typing twenty-odd dimensions.
Every board number in `ember_case.py` is measured off the STEP, with a `VERIFIED{}` dict
recording the provenance of each.

## The vendor board model

Not committed — 17.7 MB of generated CAD does not belong in git. Download it to
`../ES3C28P_3D/ES3C28P_3D.step`:

<https://www.lcdwiki.com/res/ES3C28P/ES3C28P_3D.zip>

Verified genuine: an Altium → OpenCASCADE export, `PRODUCT('PCB','PCB')`, with connectors
modelled by part number. Without it the STLs still build; the clearance check is skipped.

## Build

```bash
./cadenv/bin/python ember_case.py      # STLs + clearance check + geometry asserts
./cadenv/bin/python tools/make_renders.py   # the figures used on the site
./cadenv/bin/python ember_plug_cradle.py    # the captive-USB-C well insert (#49) + its checks
./cadenv/bin/python tools/make_cradle_renders.py   # its two figures
```

⚠️ `ember_plug_cradle.py` builds against **assumed plug-head dimensions** — see the ⛔ on its
row in [PRINT-SHEET.md](PRINT-SHEET.md) before printing it.

## What the checks actually do — and why there are two kinds

**`--- BOOLEAN CLEARANCE CHECK ---`** subtracts each part against the imported board solid
and reports the interference volume. Expect `0.000 mm³`.

⚠️ **It once returned a confident `CLEAR` that meant nothing.** The vendor STEP lives in its
own coordinate frame (X −52.75..−2.75) while the parts are in board coords, so the two never
overlapped in space and *every* boolean returned empty. It surfaced only because a bezel was
deliberately sunk 2 mm into the board and the detector **still** said `0.000`. There is now a
permanent self-test doing exactly that, and it must report **1512.804 mm³**. If it ever
reports zero, the checker is broken — not the parts.

> ⚠️ **That figure tracks the bezel's geometry and moved once without being re-recorded**: it
> was captured as 1467.842 on 2026-07-30, the #41 boss flare (2026-08-06) changed the bezel's
> volume near the board, and every doc kept quoting the old number. Re-recorded at 1512.804 on
> 2026-08-25 (observed during the #48 rebuild — whose own change, the 0.96 front-face deboss,
> provably cannot move it: sunk 2 mm, the deboss band spans z 4.74–5.70 and the board tops out
> at 4.30). The code's own gate is `> 1.0 mm³`; the recorded figure exists so a *different*
> value is noticed, so if you change the bezel and it moves, update it here **in the same
> commit**.

**`--- MESH CHECK ---`** is arithmetic on the exported triangles: every undirected edge shared
by exactly two, every directed edge appearing once. Current output, re-derived from the
committed STLs:

| part | triangles | boundary edges | non-manifold |
|---|---|---|---|
| `ember-front-bezel` | 10 162 | 0 | **3** (known, see below) |
| `ember-back-shell` | 12 628 | 0 | 0 — watertight |
| `ember-stand` | 3 268 | 0 | 0 — watertight |
| `ember-stand-base` | 12 | 0 | 0 — watertight |

⚠️ **This repo used to claim "all parts watertight, 0 non-manifold edges", and that claim was
worthless.** The check behind it imported each STL with build123d and counted boundary edges —
but `import_stl` returns a **single `Face` with zero edges and zero volume**, so the count was
0 because there was nothing to count. A perfect result about an empty object, over four parts
of wildly different complexity, reported instantly. Measured properly, the bezel had 9
non-manifold and 22 mis-oriented edges.

**Three parts are genuinely watertight. The bezel carries 3 non-manifold edges, in a solid that
is otherwise valid** — `is_valid` true, exactly one solid, zero boundary edges — and the
count is 3 whether the union is built in 2D or 3D, at tessellation tolerances from 0.1 to
0.001, before or after `clean()`. It is a mesher artefact at coplanar face seams, not a hole:
there is nothing for material to leak through, and every slicer tested repairs it silently.
The cause is the mark's 104 stacked row-spans touching edge-to-edge where one row's run ends
where the next begins; inflating each span by 20 µm took 9 to 3.

It is recorded as a **number, not a threshold** — `KNOWN_NONMANIFOLD = {"ember-front-bezel": 3}`.
A boundary edge fails the build outright; exceeding the baseline fails it too. **Do not raise
the baseline to make a build pass.**

**`[geometry]`** asserts the things a boolean is structurally blind to, because nothing
intersects:

| assert | why it exists |
|---|---|
| stand must not occlude the visible area | it once covered **19.5% of the screen** — the stand wasn't colliding with it, just in front of it |
| ≥16 mm under the slab | there was 6 mm, and a USB-C plug needs ~18–20. Missed because no figure ever showed a cable |
| ≥12 mm slot engagement | the fix for the first two is raising the slot floor, and that trades away retention |
| a fingertip must reach each button cap while docked | both caps were **completely buried** by the stand. Probed as a 6 × 6 × 4 mm patch, not a centreline sample — a point would pass straight through a slot a finger cannot enter |
| ≥3 mm of stand wall behind the finger scallops | the fix for the above is removing wall, and that is the thing it trades against |
| **the back shell must be exactly 1 solid** | the only assert here that tests the thing rather than a proxy. If the hinge-tab arithmetic is wrong the slot ring closes and a pad is not a printed-in-place hinge but a loose hexagon that falls out on the bed. A dimension check cannot see that, and neither can the clearance check — **a severed pad collides with nothing** |
| per-region bezel cell counts, never a total | the first honeycomb run put 75 cells in the chin and **zero** on the rails, and the assert passed because it read `count ≥ 60`. A total absorbed a complete regional absence |
| the wyrm mark must be **exactly 1 component** | it shipped as **two** — head floating 1.215 mm above the shoulders with no neck — while the minimum-feature check read a healthy 1.23 mm. **A gap is not a thin feature**: morphological opening measures where material *exists* and is blind to material that is *absent*, so every instrument was green about a logo that had come apart |
| the mark must clear the mic flare and fit the brow with real slack | it previously occupied 11.25 of 11.29 mm of usable brow and sat 1.21 mm from a 1.20 mm keepout. Both true, both luck, and neither would have survived the mark changing size. It now has 11.69 mm of brow and 0.44 mm of slack, against a 0.30 mm floor |
| **the wyrm-and-port group must centre on the face** | the one assert on this face that is not a clearance, and it exists because **a clearance is satisfied by any amount of slack in the wrong place**. Ink 7.700–33.351 plus the mic flare's right edge at 42.300 centres on **x 25.000**, the exact face centreline. Nothing else here would have noticed it drift |
| **mesh arithmetic on the exported STLs** | the check this replaced *could not fail* — see the mesh row in the table below |

**A test that measures interference cannot find occlusion**, and *"does it collide"* and
*"can you get at it"* are different questions — passing the first says nothing about the
second. Every fault above was caught by rendering the thing and looking at it, which is five
for five in this project on defects invisible in correct-looking source.

## Parameters most likely to need changing

| | |
|---|---|
| `DRIVER_W/H/R/T` | the speaker. Currently a 40 × 27 × 10 mm **sealed-back module** with tape on its back |
| `HINGE_L_BOOT / HINGE_L_RESET` | 1.20 / 2.00 — the thinned-flexure length, **and the correct knob for button feel.** Longer is softer *and* safer |
| `HINGE_T = 0.90` | ⚠️ not the feel knob. Strain is `(t/2)·θ/L` and θ is fixed by pip travel over the pip's arm, so **thickening a hinge moves it toward fracture**, not toward a firmer press. Asserted at ≤2.0% — the threshold was tightened from 2.5% when the thumb-sized caps made 2.5% an inheritance from a worse version of the part |
| `BTN_R_BIG / BTN_R_SMALL` | the hex caps, **8.6603 and 5.7735 mm circumradius — 15.00 and 10.00 mm across the flats.** Thumb-sized, and the reason is strain rather than taste: a bigger hex puts the hinge further from the pip, so θ falls with it. **Not free choices**: pinned between the island's bottom edge (below y=0.80 it cuts the shell's bottom wall) and the slot-and-hinge reach, which must clear the back hex field at `HEX_FIELD_Y0` (19.00) with 0.80 mm to spare. A flat-top hex spans `R·√3` in Y |
| `CAP_CX_BOOT / CAP_CX_RESET` | 33.05 / 14.51 — the island centres, which are **not** the switch coordinates (36.58 / 13.45). A 17.32 mm island centred on the switch would eat into the M3 countersink, so the islands are offset off-switch and the pip reaches across |
| `PIP_D = 3.00` | the pip that reaches the plunger. It was 4.00, and shrinking it is what made the offset islands placeable — the island narrows toward its bottom flat, exactly where the pip sits, so a 4.00 mm pip left a 0.40 mm window of legal island X. That is not a tolerance, it is a hope |
| `DEBOSS_BIG / DEBOSS_SMALL` | 0.90 / 0.50. Deliberately **unequal**, so a thumb has two discriminators in the dark — size and depth — on a case with no lettering |
| `GRILLE_STYLE` | `"hex"` or `"ridge"`. Both solved to the same **673 mm² nominal** open area, so it is aesthetic rather than acoustic. Measured on the hex field (`tools/grille_area.py`): **throat 607.8 mm² across 37 apertures** (−9.7 % on the solve — see below), **mouth 715.9 mm² across 37 apertures**, and a **946.6 mm² field** (38 × 25, r2). The nominal figure describes the throat, which is the restriction that governs level. The throat now sits **under** the solve because the finer lattice spends open area on webs — a level decision, not a defect |
| `SCALLOP_D / SCALLOP_Z0` | the finger pockets that make the docked buttons reachable at all. Module scope on purpose: `_check_geometry()` asserts against them, and a second hand-typed `12.00` in the assert is exactly the duplicate-constant trap this file has been bitten by |
| `SLOT_FLOOR` | guarded by the asserts above — raising it clears the screen, lowering it buries it |

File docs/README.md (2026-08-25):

# docs/ — the GitHub Pages root

GitHub's free plan can publish only from the repo root or `/docs`, so this
directory *is* the site. `.nojekyll` keeps the tree served untouched by Jekyll.

| File | Written by |
|---|---|
| `index.html` | **Generated** by `../site/build.py` from `../site/index.src.html`. Never hand-edit — the next build overwrites it silently. |
| `assets/` | `../site/build.py`. Six chimes as real files (fetched on click rather than inlined — rationale at the top of `build.py`) plus the social preview card. |
| `home-assistant.md` | The full Home Assistant guide: prerequisites, deploy, verify, pipeline internals, troubleshooting. |
| `audio-pop.md` | The ES8311/FM8002E pop analysis, verbatim from the original repo, plus a coda on how it was resolved. |
| `enclosure.md` | Verified board geometry, the vendor STEP model, and the case survey. |
| `enclosure-mobile.md` | The battery variant (#44): BOM, assembly order, wiring, print notes, the full measured table, and every soft number flagged. |
| `vendor/` | The archived ES3C28P schematic, plus a README of what it settles — the charger, the power path, and the *absence* of any protection IC. |
| `print-sheet.html` | **Generated** by `../site/build_print_sheet.py` (which `build.py` calls) from `../enclosure/PRINT-SHEET.md`. Never hand-edit. See the exception below. |
| `intercom-live-audio.md` | Research capture for live two-way audio (#57): the community survey, the I2S-arbiter and pipeline constraints, a recommended shape if a v2 is ever green-lit, and the open questions. Nothing in it is built. |
| `stt-mic-analysis.md` | What Parakeet actually hears (#56): levels/clipping/SNR of the saved debug utterances, the empirical transcription threshold, and the proposed mic-gain change. |
| `verification.md` | The running log of claims that outran their evidence. Read it before trusting a green check. |
| `version.json` | realm-sigil stamp, written by `../build-sigil.sh`. |

## ⚠️ Outstanding: `assets/og-card.png` is a placeholder

It exists so the `og:image` tag never points at a 404 — a broken `og:image` degrades
to *no link preview at all*, not to a plain link, so a placeholder genuinely beats
nothing.

When the real 1200×630 card lands, **swap the file *and* update `og:image:alt` in
`site/index.src.html`**, then rebuild. The alt text currently describes the
placeholder. This is the one follow-up nothing local will flag: the page renders
perfectly with a stale alt, and the only place it surfaces is a screen reader or a
social preview.

## Rebuilding — one writer per file, no ordering to remember

```bash
python3 site/build.py    # owns index.html + assets/
./build-sigil.sh         # owns version.json — and touches nothing else
```

**Order no longer matters, and that is the point.** These two commands write disjoint
files, so neither can undo the other and there is no sequence to get wrong.

It briefly wasn't so. `build-sigil.sh` used to pass sigil's `--html` flag, which
injected a `<meta name="realm-version">` tag into the *built* `index.html` — so the
site build would silently drop the tag, the sigil run would silently re-add it, and
**whichever ran last looked correct.** That is the same shape as every other failure
this project has hit: a stale artifact that renders perfectly. `--html` is now
deliberately not passed, with the reasoning recorded in `build-sigil.sh` itself.

### The meta tag, and how it is done now

This section used to propose a fix. **It has been implemented** — `site/build.py` reads the
stamp that `build-sigil.sh` already produced and injects
`<meta name="realm-version" content="…">` before `</head>`. One writer per file, the tag
survives a rebuild, and a **missing `version.json` is a skipped tag rather than a crash**, so
a fresh clone with no sigil output still builds. Run `./build-sigil.sh` first if you want the
stamp; the build prints which it did.

*(Left in place rather than deleted because the reasoning is the useful part — but stated as
what the code does, not as what someone should do. A proposal that has quietly become the
implementation is one of the easier things to leave lying around, and it reads as work
outstanding.)*

## The markdown files are NOT browsable from the site

Stated plainly so nobody files it as a bug. `.nojekyll` turns Jekyll off, which is
required so Pages serves `index.html` and the assets exactly as built — but it also
means **every `.md` file here is served as plain text**, not rendered HTML. Opening
`…/audio-pop.md` on the Pages domain gives you the raw source.

**GitHub's blob view is the intended reading surface** for all of them, and links from
the site point there for that reason. Accepted rather than fixed: rendering them would
mean either letting Jekyll process the whole tree — including a 113 KB hand-built
`index.html` it has no business touching — or maintaining a second Markdown→HTML build
for documents whose natural home is the repo anyway.

The trade is deliberate, but it is a trade. If these ever need to be readable on the
site itself, the cheapest honest fix is a link out, not a build step.

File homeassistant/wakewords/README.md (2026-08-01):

# Wake-word models

## `donk_ee.tflite` — "don-kee"

JP's custom wake word. **openWakeWord format.** Runs in Home Assistant, not on the device.

| | |
|---|---|
| sha256 | `bcc3955cef2dcf358260773ea44e30c0ad2eef51e73ccd436013f0f8b05d98c0` |
| size | 206,748 bytes |
| engine | openWakeWord (HA `openwakeword` add-on) |
| wake word id | `donk_ee` (HA displays it as "Donk Ee") |
| installed at | `/share/openwakeword/donk_ee.tflite` on the HA VM (`ha.lan`) |
| mtime on HA | 2024-06-24 |

### Why this file is in git

It was found in exactly one place — `/share/openwakeword/` on the HA VM — with no
copy anywhere else on the network, no training repo, and no training data. It is a
custom-trained model that **cannot be regenerated**. A VM rebuild or a bad `rm` would
have destroyed it permanently. The copy here is byte-identical to the deployed one
(hash above verified against the live file, not assumed).

This is a backup and a provenance record. HA reads the copy in `/share`, not this one.

### How the format was determined (and why it matters)

Directory placement is not proof of format — both engines use `.tflite`. The model was
parsed with the TFLite schema:

```
INPUT   serving_default_onnx_tf__tf_Flatten_0_f362316c:0   [1, 16, 96]  float32
OUTPUT  PartitionedCall:0                                  [1, 1]       float32
```

`[1, 16, 96]` float32 is the **openWakeWord classifier head**: 16 frames of 96-dim
embeddings produced by openWakeWord's shared melspectrogram + embedding frontend. The
`onnx_tf__tf_Flatten` tensor name is openWakeWord's PyTorch → ONNX → TF export path.

**microWakeWord** — the format ESPHome's `micro_wake_word` component requires — is
different in kind: int8-quantized, self-contained, with its own streaming spectrogram
frontend and a JSON manifest carrying `micro.probability_cutoff`, `sliding_window_size`
and `tensor_arena_size`. Typical size ~40 KB, not ~200 KB.

The two are **not interconvertible**. There is no conversion script, because the
difference is the feature frontend and the training regime, not the serialization.
Putting this file in an ESPHome `micro_wake_word:` block will not work.

### If you want "don-kee" on-device one day

It has to be **retrained** as a microWakeWord model (the
[microWakeWord](https://github.com/kahrendt/microWakeWord) trainer generates samples
with a TTS piper voice — no original recordings needed). That would remove the
constant audio streaming described in `docs/wake-word.md` and is the better end state.
It is a training task, not a wiring task.

### Known loose end, not in this repo

The M5Stack ATOM Echo (`m5stack-atom-echo-a14320`) currently reports an **on-device**
wake word literally named `donkee` in HA:

```
select.m5stack_atom_echo_a14320_wake_word  options=['no_wake_word', 'Okay Nabu', 'donkee']
```

So a microWakeWord "donkee" model *did* exist — a project memory records tuning
`micro.probability_cutoff` in `wake_word_models/donkee.json` from 0.73 → 0.60 on
2026-05-14. That model and manifest are **gone**: not in `~/Projects/ha` (whose
committed `m5stack-atom-echo-a14320.yaml` lists only the three stock models), not in
`/config/esphome` on the HA VM, not in any ESPHome build cache, and not in any GitHub
repo. The live M5Stack firmware simply predates the current YAML and still carries it.

It survives only as flashed firmware on that device. **Do not reflash the M5Stack
without extracting it first** — that flash is the last copy.

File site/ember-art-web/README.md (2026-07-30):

# Ember — web art (the hearth-wyrm)

Lyra · 2026-07-29 · for `ember.realm.watch`

Open **`contact-sheet.html`** first — everything is on it, and the hero wakes when
you point at it.

## What these are

The same creature that is on the device right now. `wyrm_svg.py` **imports** the
device generator — `esphome/art/dragon.py`, now in `ember.realm.watch` — and traces the supersampled grid its mask
builders produce, so the site and the hardware are not "matching art" — they are
one set of curves rendered two ways. Re-pose the wyrm on the device and these
regenerate to match.

The device version is 1-bit run-length spans shaded per-pixel from a fire ramp,
because the framebuffer is in PSRAM and every pixel costs. None of that applies
here, so the web version gets real gradients, a rim light and sub-pixel curves.

## Files

| file | use | gzip |
|---|---|---|
| `wyrm-startle.svg` | **the hero.** Inline it — CSS cannot reach into an `<img>` | 13 KB |
| `wyrm.svg` / `wyrm-light.svg` | static hero, dark / parchment | 8 KB |
| `favicon.svg` | the coil glyph, **1.7 KB of markup** for `<link rel="icon">` inlining; `favicon-{16,32,64}.png` are fallbacks | 1 KB |
| `wyrm-states.svg` / `.png` | the five states, **labelled**, for a spec section | 18 KB |
| `wyrm-states-bare.svg` | same five states, **no labels** — for CSS-sliced cards where HTML carries the text | 18 KB |
| `wyrm-winged.svg` | the rejected variant, kept so the call is checkable | 7 KB |
| `og-card.png` | **1200×630 Open Graph card** → `docs/assets/og-card.png` | 131 KB |
| `og-card.svg` | its source | — |
| `contact-sheet.html` | everything on one self-contained page | 47 KB |
| `case-motif.svg` | the dorsal ridge as a 1:1 mm grille repeat, for nebula's shell | — |

Self-contained: the only URL anywhere is the SVG namespace declaration, which is
never fetched. Zero `<script>` tags. No fonts downloaded — labels use the
system UI stack.

**Every `id` is namespaced per file** (`wh-`, `wk-`, `ws0-`…`ws4-`, `ww-`, `wf-`,
`og-`). Inlined SVGs share one document ID space, and an unprefixed
`<linearGradient id="belly">` in two files cross-wires — rendering something
plausible rather than something obviously broken. There is a collision audit in
the build.

**The state sheet is five equal panels stacked vertically in one file** — exactly
528 units each, origins at 0/528/1056/1584/2112 — so
`background-size: 100% 500%` with positions at 0/25/50/75/100% slices it exactly.
Use `wyrm-states-bare.svg` for the cards: text baked into artwork shrinks with
the card, HTML text does not, and a screen reader cannot see text inside a CSS
background image.

**The startle's stylesheet is scoped under `.ember-art`.** An inline `<svg>`'s
`<style>` is *not* scoped to that svg — it is a stylesheet in the host document,
so a bare `.hearth { opacity: .8 }` would restyle anything on the page using that
class name. The class *hooks* are unchanged; only the rules are fenced. The
keyframe is `ember-wyrm-breath` for the same reason.

## Using the hero

```html
<!-- inline the file's contents here, not <img src> -->
<svg …>…</svg>
```

Put **`class="ember-wake"` on the hero container** and it wakes on that
container's `:hover` / `:focus-visible` / `:focus-within` / `:active` — bigger hit
area than the svg alone, and on touch the whole card is the target. `.is-awake`
on any ancestor does the same thing programmatically.

The svg deliberately carries **no `tabindex`**: the container owns focus, so
there is one tab stop for one thing rather than two.

It also carries **no `prefers-reduced-motion` block**. The page has a global
`* { animation-duration: .001ms !important }` rule, and a second authority on the
same question would eventually fight it. The page wins.

Hooks, if you want to restyle rather than replace: `.wyrm`, `.headneck`, `.body`,
`.neck`, `.head`, `.jaw-shut`, `.jaw-open`, `.maw`, `.eye`, `.eye-glow`,
`.hearth` (drop this one class to lose the fire and keep the creature).

## Where these go

Per morpheus: generator + spans live in **`esphome/art/`** (that directory name is
load-bearing — the generated block in the yaml references `esphome/art/dragon.py`,
so it must not be renamed). Site and README imagery goes to **`docs/assets/`**.

`wyrm_svg.py` finds the device generator by searching `DEVICE_ART_CANDIDATES` in
priority order and prints which one it used. It moved once already (from
`~/Projects/ha/` to `ember.realm.watch`) and a hardcoded path died six frames
deep in an import; the next move is a one-line addition and a clear message.

## The OG card

`python3 og_card.py` builds it and prints the alt text plus its checks:

```
  exact 1200x630                                ok
  2:1 centre crop keeps the type                ok   crops 15px top/bottom
  edge distinguishable from black chrome        ok   mean edge luminance 32.6
  creature stays out of the type column         ok   0 creature pixels inside it
  smallest type >= 26px (~6.5px at 300px wide)  ok
  no near-invisible text fills on the dark card ok   8 text fills, all legible
```

The last two checks exist because the first draft failed both and every check I
had at the time passed anyway: the dragon was sitting on the subtitle, and the
body copy was in `PAL['ink']` — the *daylight* ink — on a dark card. Format
checks do not catch composition, so now two of them do.

`og:image:alt`:

> Ember, a glowing dragon curled in a hearth fire on a small ESP32 screen — a
> voice assistant whose speech-to-text, 35-billion-parameter language model and
> text-to-speech all run on local hardware, with no cloud service involved.

## Palette

```
ground #0A0604 · ash #3A322C · bed #4A1002 · ember #8E2206
amber  #E05A08 · gold #FFA81E · white-hot #FFE8B4 · alarm #FF3C18
parchment #F2E8DA · ink #2A1C12                     (daylight)
```

## Regenerating

```bash
python3 wyrm_svg.py      # hero + the fidelity check
python3 build_assets.py  # favicon, states, startle, winged, contact sheet
```

`wyrm_svg.py` ends with a measurement, and it is the guard that matters:

```
silhouette fidelity — vector vs the device's own geometry, at 8x:
  body       IoU 0.9714   device  1168.5 px^2  vector  1194.0 px^2   ok
  head-shut  IoU 0.9471   device   209.3 px^2  vector   208.5 px^2   ok
  head-open  IoU 0.9463   device   228.6 px^2  vector   228.7 px^2   ok
```

Ground truth is the **supersampled grid**, not the 120×50 sprite. That took a
measurement to settle: the body scores 0.86 against the sprite and 0.98 against
the geometry the sprite is a quantisation of — the difference is the sprite's own
pixelation, not the vector's error. Comparing against the sprite would have had
me "fixing" the vector to reproduce aliasing.

The head matters most here because it is **not** traced. It is rebuilt from the
same primitives (a tapered skull tube, brow, two horns, cheek frill, jaw tube),
whose numbers are copied from `dragon.py`. That is a drift risk, so the check
above is what catches it: re-sculpt the device head without updating these and
the build fails.

## Two decisions worth knowing

**The favicon is the coiled pose — the one rejected for the device.** That
rejection was never about the coil being wrong, only about it fighting a 240×76
band. In a 1:1 box the coil is exactly right, and it degrades the way a favicon
must: an ember at 16px, a curled creature at 32, a dragon with its head over its
tail at 64. It fails into something meaningful instead of into mud.

**No wings.** See `wyrm-winged.svg`. Reasons in `../lyra-artist.md`.

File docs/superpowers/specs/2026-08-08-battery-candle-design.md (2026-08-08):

# The candle — the mobile hearth's cell, read as wax

**Date:** 2026-08-08 · **Status:** implemented, flashed to the mobile, HA side live

A candle in the sigil band of `ember-mobile` only: wax height is state of charge,
the flame is the state of the state. Born from a real failure — on 2026-08-06/07
the bare 18650 discharged from 3.76 V to a recorded **2.508 V with nobody
watching**. That cell has no protection IC; a cell left flat goes to zero and does
not come back. The candle is the quiet half of the answer, the escalation ladder
the loud half, and the 1S protection strip remains the actual safety net.

## The glyph (sigil band, right edge)

```
full, on charge      low (guttering)      critical           unknown
     *                                        ▮▮  (blinks)
    ▲▲▲                   ◢◢  (leans           |                 |
     |                     | on 600ms          ▯                 |
   ▓▓▓▓▓                 ▓▓▓  ticks)          ─────           ─────
   ▓▓▓▓▓                 ─────
   ─────
```

- **Wax** = SOC, 0–14 px on a fixed baseline, molten rim on the top face.
- **Flame**: steady teardrop healthy; **white-tipped and taller** when the rail
  reads ≥ 3.98 V (full-or-charging — the TP4054's CHRG pin isn't wired, so the
  flame claims only what the voltage shows); **leaning gutter** at ≤ 20%;
  **blinking alarm spark** at ≤ 8%; **cold wick, no wax claim** before the first
  sample — unknown and empty never share a glyph.
- State carried by shape and motion, never colour alone (band accessibility rule).
- The sub-line's right anchor and the unread dot step left of the candle,
  compile-time gated, so the desk layout is bit-identical to before.

## Two bodies, one firmware

`has_battery: "0"` in the shared config, `"1"` in `ember-mobile.yaml`. Every
battery lambda tests the literal and folds out on the desk build — which is the
*correctness* property, not an optimisation: the desk's GPIO9 floats, and noise
can look like any voltage you name. The **SOC entity lives in the wrapper**, so
the desk cannot grow a confident number derived from a floating pin, and the HA
automation triggering on that entity can never fire from the desk. Verified: the
desk build log contains zero `Battery SOC` references.

## Signal chain

GPIO9 ADC, 60 s → `median(5)` (speaker sag rejection: one deep sample is
*discarded*, not averaged in) → piecewise-linear SOC over an 11-point table
calibrated to this cell's observed discharge, sized-array declarations
(`VS[11]`) so `check_art_sync.py`'s empty-bracket heuristic ignores them —
same convention as `LEN_MS[8]`. Live cross-check at deploy: 3.636 V → 43%,
matching hand interpolation exactly.

## The escalation ladder

| trigger | act | owner |
|---|---|---|
| SOC ≤ 20%, once per discharge | `chime_guttering` — C5→A4→F4, a fall that *sinks past* where `done` resolves; on-pentatonic because a low cell is normal life, not an error | firmware (latched, released at +5 pts) |
| SOC ≤ 8% for 10 min | the mobile speaks one persona line herself, `continue_on_error`; then `ember_broadcast` (importance high) → desk hearth, or Slack in quiet hours | `ember_battery_watch.yaml` |

Case 7 follows §15's discipline: enumerated in the `is_running()` guard list
*and* guarded at its play site — it must never destroy a reply in flight; there
is a whole ladder behind it. `numeric_state` ignores `unknown`, so a rebooting
board (SOC is NAN until the first sample) cannot false-alarm, and a board that is
*offline* is deliberately not this alarm's job — a battery alarm that also means
"wifi hiccup" trains people to ignore it.

## Scheduler cost

Two repaint reasons, both folding out on the desk: a signature-int change test
(wax px + banding + rich bit — a 60 s sample that changes nothing visible
repaints nothing), and a 600 ms gutter tick (a multiple of the 50 ms frame, per
the scheduler's `!!` warning) that runs **only while guttering and idle** — in
conversation the flame band keeps its slots and a frozen mid-lean flame still
reads as guttering. Shape is the signal; motion is a luxury.

## Honest limits

- Voltage→SOC on a flat li-ion curve is an estimate; the middle of the table is
  ±10 points on a warm day. The thresholds are placed on the steep shoulder
  where the estimate is good.
- No charge detection beyond the ≥ 3.98 V read — the CHRG line isn't wired.
- A dead/offline board shows a stale candle on a dark screen — moot — and a
  stale SOC in HA; `ember_backend_health` owns liveness, not this.
- The desk unit was offline (unplugged) at flash time; it runs the previous
  build, whose behavior is identical. It picks the new source up on next flash.

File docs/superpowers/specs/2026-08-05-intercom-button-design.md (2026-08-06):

# The horn — an intercom button on the hearth — design

**Date:** 2026-08-05 · **Status:** approved (JP: "do it all") · **Scope:** v1, STT→TTS relay

Tap a horn glyph in the bottom-right of either Ember's screen → that Ember says
*"Send word."* and listens → the words are transcribed by the pipeline's normal STT
(vosk) → the **other** hearth speaks *"Word from the desk hearth: 〈words〉"* through
`script.ember_announce` (single herald). No LLM in the chain: **the intercom works
while `familiar` sleeps.** Live streaming of the actual voice remains
[#57](https://github.com/jphein/ember.realm.watch/issues/57).

## The primitive, verified before design

`assist_satellite.ask_question` with `answers` omitted returns
`{id: null, sentence: <raw STT text>}` (core `entity.py`: on no answer list it
returns the raw response text). **Probed live 2026-08-05 on the desk unit, HA
2026.7.4 / ESPHome 2026.7.3: the device spoke the question, listened, and returned
`sentence: "huh"`.** This is what lets the firmware stay a dumb button: HA drives
the listen session through the same satellite machinery conversations already use —
no I2S, VA-state, or pipeline changes on device.

## Firmware (shared config; both boards inherit via the wrapper pattern)

- **Touch zone:** bottom-right block of the telemetry band — `x ≥ 192, y ≥ 264`
  (47×56 px ≈ 8.7×10.3 mm). New `ui_ic_x`/`ui_ic_y` substitutions, shared by
  hit-test and drawing per the overlay-geometry rule (drawn and tappable cannot
  drift). Hit only in normal mode (`ui_mode == 0`); during overlays the corner
  stays tap-away-dismiss and the glyph is not drawn.
- **⚠️ This carves the first exception into "any touch is talk".** That invariant's
  comment (touchscreen `on_touch`) is amended in place, dated 2026-08-05, JP's
  call: a *drawn, visible* control is not the silent misbehavior the rule guards
  against, and the rest of the screen stays byte-for-byte the talk gesture.
- **Action `16`** (next free): latched in `on_touch`, dispatched in `ui_dispatch`
  on release like every other target. Gated to idle exactly like talk
  (`va_state == 0 || 4`). Gets the standard haptic chime (its existing
  `va_state != 1` guard already protects the mic). **No coal strike** for this
  corner — feedback comes from the thing touched: the glyph flashes bright for
  ~400 ms via a new `ic_ms` global (the `spark_ms` pattern).
- **Signal to HA:** a template `event` entity (`Intercom`, event type `pressed`)
  — no HA-actions permission needed, and each device's event entity carries its
  identity, which is how the automation knows source from peer.
- **Glyph:** a small horn in the ember palette (dim amber at rest, gold while
  flashing), drawn in the telemetry band's right block. The band is chrome — it
  erases and overdraws by design, outside the flame band's write-once invariant —
  so the glyph costs nothing and cannot ghost.

## Home Assistant (new package `homeassistant/packages/ember_intercom.yaml`)

One automation, `mode: restart` (a new press supersedes a stuck capture; the
relayed announce itself is dispatched fire-and-forget via `script.turn_on`, so a
restart cannot kill a delivery in flight):

1. Trigger: state change of either `event.ember_*_intercom` entity. Guard: both
   `from_state` and `to_state` real (not `unavailable`/`unknown`) — event entities
   flap through `unavailable` on every device boot and HA restart, and a phantom
   summon on reboot is exactly the kind of bug this repo documents.
2. Map source → peer (desk ↔ mobile).
3. Peer satellite `unavailable`/`unknown` → speak on the **source**:
   *"The mobile hearth is dark."* Stop. (Fail before capture — don't take the
   user's speech and then lose it.)
4. `assist_satellite.ask_question` on the source — `question: "Send word."`,
   `preannounce: false` (Ember chimes locally, same rule as announce),
   `continue_on_error: true`, `response_variable: reply`.
5. `reply.sentence` non-empty → fire-and-forget `script.ember_announce` to the
   peer: *"Word from the {source} hearth: {sentence}"*. Empty or errored →
   fire-and-forget to the source: *"I heard nothing to carry."*

Registered in `deploy-ha.sh`'s `PACKAGES` array **in the same commit** (the
documented drift trap), with `automation` in the reload map.

## Out of scope

- Live voice streaming (#57).
- A relay *target picker* — with two hearths, "the other one" is fully determined
  by which button was pressed. The `send_word` LLM tool already covers arbitrary
  targeting by voice.
- Wyoming/Atom Echo satellites — this is a hearth-to-hearth feature.

## Verification

1. `esphome compile` both configs; OTA both boards (MAC-checked names).
2. Press the horn on the desk → mobile speaks the relayed words
   (`speaker_frames` climbs); press on the mobile → desk speaks.
3. Peer powered off → *"…hearth is dark."* on the source.
4. Silence after the prompt → *"I heard nothing to carry."*
5. Overlay open → corner tap dismisses the overlay (no intercom fire).
6. `check_navigability.py` and the other `esphome/tools/check_*.py` that apply;
   `deploy-ha.sh --check` before deploy.
7. Live two-hearth test with JP (also closes PR #58's two deferred items:
   the by-ear double-herald note and the unreachable-hearth reply).

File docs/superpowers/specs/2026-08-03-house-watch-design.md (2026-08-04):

# The house row — what is still awake, seen from the hearth

**Date:** 2026-08-03 · **Status:** implemented and flashed to both boards

One row at the bottom of Ember's screen answering one question at a glance: is
anything still running in the house, and where. Lights, minisplits, radiant
floors, radiators and the towel warmer.

## Requirements, as settled

| | |
|---|---|
| What it says | **Which rooms**, not just a count and not just yes/no — so it can be acted on without opening the app |
| Overflow | **Cap the glyphs at 4, keep the names readable.** Past four rooms the coals become `+N` |
| Grouping | **Rooms, not devices.** The Laundry has a bulb *and* a minisplit and is one room |
| Kinds | Lights, plus cooling and heating as distinct marks |

## Architecture

```
sensor.lights_on                    house-wide, packages/lights_overview.yaml
climate.*  (minus 2 duplicates)     minisplits, floors, radiators
        │
        ▼
sensor.ember_house_watch            homeassistant/packages/ember_house_watch.yaml
  state      = rooms awake (union, deduped)
  names      = "Laundry . Shed"  (joined, capped at 4 + "+N")
  lights / cooling / heating = counts, for glyph typing
  detail     = human-readable why (dashboard + debugging; never on the device)
        │  5 × platform: homeassistant, internal: true
        ▼
TELE_Y + 40                         esphome/ember-satellite.yaml
  <coals> <heat/draught marks>  <room names>
```

**HA shapes, the device draws.** Every set-union, dedupe and truncation is Jinja,
which can be pasted into HA's template editor and watched live. The display lambda
is the hardest place in this project to test anything, so it does no string work
and no arithmetic it could get wrong.

This is the **first state this device has ever imported from Home Assistant** —
everything else flows outward. The consequence worth stating: the values are NaN
until HA connects, which is not an error path but the normal first second of every
boot.

## The three states

```
lit       (o) (o) ≡   Laundry . Shed
quiet     ~ every hearth banked ~
unknown   hearths unknown
```

`unknown` is not decoration. Reporting 0 when nothing is known claims the house is
dark — a lie in the one direction that costs money. `availability:` on the template
sensor propagates unavailability, and `HomeassistantSensor` publishes `NAN` for
anything it cannot parse (`homeassistant_sensor.cpp:14-18`, verified by reading it),
so the device sees unknown rather than zero. Observed live during a
`template.reload`.

## Four traps, all found on the bench

1. **A naive `light.*` count returns 10, not 2.** It sweeps up
   `light.ember_satellite_backlight`, `light.ember_mobile_backlight`, both status
   LEDs, three BLE-proxy Bluetooth LEDs and two minisplit display LEDs. **Ember
   would have counted its own screen as a light left on and never once read zero.**
   `sensor.lights_on` already excludes all of it.
2. **The minisplits are exposed twice.** `climate.air_conditioner` has
   `friendly_name: 'laundry minisplit'` and `air_conditioner_2` is
   `'luna minisplit'` — the same two physical units as `climate.laundry_minisplit`
   / `climate.luna_minisplit` via a second integration. Matching on a name pattern
   makes one running unit read as two. Excluded by entity_id.
3. **`state` is the mode; `hvac_action` is whether it is running.**
   `climate.kitchen_thermostat` ("Kitchen Floor") sits at `state='cool'` with
   `hvac_action='idle'`. Counting `state != 'off'` reports the floor as going while
   it does nothing — and it looks right whenever something *is* running, which is
   what would have shipped it. The minisplits publish no `hvac_action` at all, so
   the two families need different rules.
4. **The floors and radiators are named `*_thermostat`.** Searching entity_ids for
   "radiant", "radiator" or "floor" finds *nothing*; only the friendly names say
   what they are — Kitchen Floor, Bedroom Floor, Pumphouse Floor, Laundry
   Radiators, Towel Warmer. Concluding they didn't exist would have been a search
   proving absence with no control (`verification.md` §13).

## Display constraints that set the design

- **No new band.** Bands tile 0..319 exactly and at most one repaints per frame.
  The fuse precedent is explicit: a 4-row band still consumes a whole frame slot
  and cost the fire ~5fps. This row lives inside TELE, which is chrome that
  overdraws by design and sits outside the flame band's write-once invariant and
  its 18,240 px/frame budget. Four coals is ~256 px — free.
- **Row 3 is the last row.** TELE is 264..319; rows at +6, +24, +40. A row at +58
  would end at 334 and draw outside its band, and because the framebuffer persists
  that litter would be permanent and would look like ghosting, not overflow.
- **Not the +24 slot**, which the op_mode lines own — losing the indicator exactly
  when Ember is quiet is backwards.
- **Shape carries the kind, not colour.** The palette is one fire-temperature ramp
  by design with `alarm` its only exception, and the band's accessibility rule is
  that no state is ever carried by colour alone. A coal is round, heat rises to a
  point, a draught is flat — all three read in greyscale.
- **The breathing period is set by band rotation, not taste.** One band per frame
  at 50 ms means this row redraws ~every 200 ms (5 fps). A short pulse reads as a
  stutter; 3500 ms reads as a breath. Coals are offset 800 ms apart so they look
  like separate fires rather than one blinking row.

## Known gap, deliberately left open

A **full API disconnection** pushes nothing, so the last value persists and the row
can show a stale count. It is not detectable locally without lying: the obvious
guard is "is an API client connected", and `on_client_connected` fires for *any*
client including the `esphome` CLI, so `esphome logs` alone would satisfy it with
HA absent. A guard that reads as a freshness check while testing something else is
worse than the staleness it hides. The honest fix, if ever needed, is a heartbeat
*from* HA — a value that changes on a timer, so absence of change is absence of HA.

## Out of scope

`sensor.lights_unavailable` reports 3 locally-controlled lights (TV Glow, Under
Counter, Outdoor) that HA cannot see. Surfacing "and 3 I can't see" is a real idea
and a second feature; it would crowd a 240px row.

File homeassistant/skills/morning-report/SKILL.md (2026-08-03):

---
name: morning-report
description: >-
  How to compose the spoken morning summary: weather, the printer, whether any
  machines are down, and who is about. Use when asked for the morning report, a
  briefing, a rundown, "how are things", or what JP needs to know today.
---

# Morning report

A briefing spoken aloud at the hearth. It is **four short sentences at most**, and
fewer when there is nothing to say. This is the one place you may go past the
usual one-sentence rule — but a report nobody can hold in their head is worse
than no report.

## Gather, in this order

1. `weather_now` — what it is doing outside, today's high and low, rain.
2. `check_print` — only mention the printer if something is actually printing, or
   if it is unreachable while a print was expected. An idle printer is not news.
3. `realm_status` — call it with no host. Mention machines only if something is
   **down**. "Everything is up" is worth at most three words, and usually none.
4. `whos_home` — mention only if it is surprising, for example the house is empty.

## Compose

Lead with the weather, because it is the one thing that is always true and always
useful. Then anything that is *unusual*. Then stop.

Good:

> Cold start, forty-three out, up to sixty-nine later with no rain. The midframe
> print is about two thirds done, roughly an hour left. Everything else is up.

Bad — this is a status dump, not a report:

> Weather is clear night, temperature 55F, high 69F, low 34F, rain 0mm. Print job
> ember mobile midframe r10 at 60 percent with 1 hour 10 minutes remaining. Eight
> machines watched, all up. Tracked people 1, jp home.

## Rules

- **Round every number for speech.** "Forty-three" not "43F". "About an hour" not
  "1 hour 10 minutes". Nobody needs a decimal at breakfast.
- **Never invent a calendar.** This house has no personal calendar exposed to you
  — the only calendars are game-shop freebies and a lighting schedule. If asked
  about the day's plans, say you do not have his calendar. Do not read out Epic
  Games Store entries as if they were appointments.
- **Report failures as failures.** If `weather_now` says `forecast_unavailable` or
  `check_print` says `printer_unreachable`, name the gap in a few words. A report
  that quietly omits what it could not fetch is a report that lies by shape.
- Do not offer to do things. This is a briefing, not a menu.

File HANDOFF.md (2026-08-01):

# HANDOFF — 2026-07-30

State at the end of the session that built the enclosure and the operating modes. Everything
below is verified against the artifact, not against a report — that distinction mattered
repeatedly here, and the running log of the times it did is [`docs/verification.md`](docs/verification.md).

## ⛔ READ THIS FIRST — everything below predates 2026-07-31 00:00

**JP printed the back shell and found the board model wrong.** The sections below were written
before that and still describe four parts as ready. **They are not.**

| part | printed? | status |
|---|---|---|
| **front bezel** | yes | ✅ **correct, keep** — proven byte-identical through every change since |
| **back shell** | yes | ⛔ **superseded, reprint** — microSD slit was on the wrong edge and ~24 mm out; an opening exposed the LCD driver flex; the two button caps were on the wrong ends |
| **stand / dock** | yes | ⚠️ **superseded but FUNCTIONAL — see below. Do not reprint it to fix the buttons.** JP is reprinting by choice, for the next prototype |
| **stand base** | **never** | ✅ committed version is the fixed one (the previous was 1.40 mm too deep to seat) |

### ✅ THE PRINTED STAND STILL WORKS. Measured, `86748c6`.

The two finger pockets **had already merged into one scoop** spanning board x **6.94 … 43.51**, and
that scoop contains **both caps in their new swapped positions**:

| cap | new island x | cap spans | in the printed scoop? | 6 mm fingertip | 16 mm thumb |
|---|---|---|---|---|---|
| BOOT (big / volume) | 16.66 | 8.00 … 25.32 | **yes, wholly** | clear | clear |
| RESET (small) | 35.66 | 29.89 … 41.43 | **yes, wholly** | clear | 0.15 mm clipped |

The 0.15 mm on the small cap is irrelevant — RESET is deliberately *not* thumb-sized, and the
thumb-sized cap is fully clear. **The reprint is cosmetic.** Measured against the **committed
source that produced the STL JP actually printed** (old `CAP_CX` 33.05 / 14.51, `SCALLOP_CLR` 1.80,
`SCALLOP_MIN_RIB` 3.00), not against the new source. It survives only because the *merge rule*
made the scoop far wider than either cap needs — had the pockets stayed separate, the swap would
have missed both.

### ✅ The counterbore has landed (was "partial" when the line above was written)

`CBORE_D` / `CBORE_DEPTH` / `BOSS_FLARE_D` are all in `ember_case.py` as of `86748c6`, the conical
countersink and its entire rationale are deleted, and the back-shell STL is rebuilt. **Nothing to
check before slicing.** Labels (SD / MIC / VOL / ⏻) are **in** — see below.

**Fastener, fully measured by JP (not nominal):** M3 × 0.5 × 12 **ISO 4762 socket cap, hex recess**,
head **5.50 × 3.00**. Flush, in a flat-bottomed **counterbore**.

- Depth is **3.04 mm = 19 layers**, not 3.00: flush wants 3.00, which is 18.75 layers and cannot
  land a flat floor. 18 layers leaves the head **proud**, which stops the part sitting flat — so it
  rounds *deeper*, sinking the head 0.04 mm. Invisible.
- **Engagement 5.34 mm = 1.78 D**, clearing the end of the pilot by 0.86 mm. (An earlier note said
  5.30 / 1.77 D / 0.90 — that was computed at a 3.00 depth, before the layer rounding.)
- **The boss flare exists *because* the head is 3.00 mm.** A flush pocket floors **0.44 mm** into
  the cavity, where the d5.80 bore is wider than the d5.40 boss and the head has nothing to bear
  on. The boss flares to **d8.40** below the PCB face. ⚠️ **The permission is a distinction, not a
  licence: the vendor's ⌀5.60 pad keepout applies AT the PCB face, not below it.** Anyone
  "restoring" the boss to a uniform 5.40 to match the keepout comment silently deletes the seat.
  There is an annulus assert guarding it, with a control that reproduces the un-flared defect.

⚠️ **Slicer, unchanged and still critical: gap-closing radius / hole horizontal expansion must be
`0`.** The button moat is 0.60 mm and gap-closing welds it shut, fusing the printed-in-place caps
to the shell. The model cannot defend against this.

**Root cause, and the part worth carrying forward:** the vendor STEP had **four features missing or
fictional** — both switches absent, the mic port suppressed, and a 0.5 mm plate taken for the
microSD socket that is actually the **LCD driver flex**. The real socket is in the same file as
**zero-thickness faces**, invisible to any search over `.solids()`. And `SD_PLATE` **had no
consumers**: the openings were hand-typed literals, so nothing recomputed when it was wrong and no
assert could have caught it. Openings now derive from a component table.

Full orchestration state, including the three questions still open with JP:
`~/.claude/projects/-home-jp-Projects-familiar-realm-watch/scratch/hosyond-s3/HANDOFF-orchestration.md`

---

## Shipped and working

| | |
|---|---|
| **Device** | Conversation, multi-turn, no pop, responsive taps. Three operating modes, verified across a power cycle on hardware. Volume **and mic gain** are live controls in the single-press overlay. |
| **Repo** | <https://github.com/jphein/ember.realm.watch> |
| **Site** | <https://jphein.github.io/ember.realm.watch/> — page + print sheet |
| **STL downloads** | all **four** + `ember_case.py` from raw GitHub |
| **Enclosure** | boolean-verified 0.000 mm³ against the vendor solid; geometry asserts pass. Mesh: three parts watertight, `ember-front-bezel` at its documented baseline of 3 non-manifold edges and **zero** boundary edges. **`ember-front-bezel` has been printed and its dimensions are good** — one part of four; nothing assembled |
| **Standing guards** | five, all green — see below. Four of them exist because "committed" turned out not to mean "deployed" or "served" |

`~/Projects/ha` is clean and in sync. Ember has been fully extracted from it.

## Firmware: three operating modes

**Normal** (speech + chimes) → **No talking** (chimes only) → **Hush** (silent). Monotonic:
progressively quieter, and nothing else varies. Conversation works fully in all three and the
reply still displays on screen — only what leaves the speaker changes.

> **Hush changed meaning.** It used to mean *"do not listen to me"* and gated the talk gesture.
> It now means *"do not make noise"*. If you find a doc, dashboard tile or icon that says
> otherwise — `mdi:microphone-off` is the tell — it is stale and was true once. The mode select
> belongs beside Hush wherever Hush appears, because Hush as a view can only reach Normal and
> Hush, so "No talking" is otherwise unreachable from HA.

`op_mode` is the thing that persists; the select and the Hush switch are lambda views over it,
re-published at boot so a device rebooted while quiet cannot come back disagreeing with itself.
That fault was found by rebooting the real device in Hush, not by reading the config.

## The enclosure, current state

**Four** printable parts in [`enclosure/`](enclosure/) — bezel, back shell, stand, stand base.
**`ember_case.py` is the artifact; the STLs are output.** Rebuild:

```bash
cd enclosure
python3 -m venv cadenv && ./cadenv/bin/pip install -r tools/requirements.txt
./cadenv/bin/python ember_case.py            # STLs + clearance check + geometry asserts
./cadenv/bin/python tools/make_renders.py    # the site figures
```

Both scripts are anchored to their own location rather than to the working directory. They were
not, and the documented build command was therefore a claim rather than a fact — it only ever
worked because a stale `__pycache__` was lying around. The venv is `cadenv`, excluded in **both**
`.gitignore` and `~/Projects/.stignore`; note that Syncthing's `(?d)venv` pattern does **not**
match `cadenv`, which is how the whole toolchain vanished once.

**Buildable from a fresh clone** — see [`enclosure/README.md`](enclosure/README.md).
`tools/requirements.txt` pins the exact set the shipped STLs were built with. The 17.7 MB
vendor STEP is linked rather than committed; without it the STLs still build and only the
clearance check is skipped.

### What landed most recently

- **Thumb-sized hexagonal button caps, debossed rather than raised.** BOOT **15.00 mm across
  the flats** (17.32 across corners) at 0.90 mm deep, RESET **10.00** (11.55) at 0.50. Flat-top,
  against the motif, because the pad is a living hinge and a pointy-top hex would put a *vertex*
  where the hinge must be. They were 9.01 / 6.58 mm, and the reason to grow them was **strain,
  not looks**: a wider hex puts the hinge further from the pip, so θ falls with it and both
  hinges dropped to ~1.20% (from 2.29% / 2.18%). The assert was tightened 2.5% → **2.0%** in the
  same change, because a threshold calibrated to what the *old* caps could achieve is a ratchet
  pointing the wrong way.
- ⛔ **NUMBERS IN THIS ITEM ARE VOID as of `86748c6` — the switches swapped and the islands are now
  SOLVED, not typed.** Current: islands **16.66 / 35.92→35.66**, switches **BOOT 13.45 / RESET
  36.58** (BOOT and RESET are the *opposite* ends from what this item says). The obstruction is no
  longer a countersink but a d5.80 counterbore *plus* a d8.40 boss flare. Marked here rather than
  left to the header caveat, per `docs/verification.md` §12: **a caveat is read once and an
  instruction is read at the moment of acting on it.** The reasoning below still holds; only the
  figures and the sides are wrong.
- **The cap islands are offset from their switches** — centres at x 33.05 and 14.51 against
  switches at 36.58 and 13.45 — because a 17.32 mm island centred on the switch would eat into
  the M3 countersink. `PIP_D` shrank 4.00 → **3.00** to make that placeable: the island narrows
  toward its bottom flat, exactly where the pip sits, so a 4.00 mm pip left a 0.40 mm window of
  legal island X. The back hex field's lower boundary moved to a named `HEX_FIELD_Y0 = 19.00`
  to clear them — and the assert that checks the caps against it had been reading a hardcoded
  `11.0`, firing against a boundary the part no longer had.
- **Finger scallops in the stand's rear slot wall.** At the old cap size both caps were
  completely buried — BOOT's top edge 3.81 mm below the stand's rim, with 0.40 mm between the
  cap face and solid wall. A taller cap could not have helped: the obstruction is *beside* the
  cap, not above it. With the thumb-sized caps BOOT's top edge now stands 2.19 mm *proud* of
  the rim and RESET's is still 2.81 mm under it, so the scallops still do the work.
- **Debossed honeycomb + the hearth-wyrm on the bezel face.** 57 cells in the chin, a 16-cell
  chain up each rail, the wyrm **25.65 × 11.25 mm** in the brow. All **0.48 mm** deep — exactly
  three layers at the bezel's 0.16 mm, where 0.45 was 2.8125 layers and left the recess floor
  wherever the slicer's rounding fell. Recesses at all because on a
  bed face relief can only go inward. The chin was 75 until the screw-boss keepout was
  actually *applied* rather than merely listed in a comment; nine cells per boss, two bosses
  in the chin. The wyrm was also shipping as **two disconnected pieces** — head floating
  1.215 mm above the shoulders — while the minimum-feature check read a healthy 1.23 mm,
  because **a gap is not a thin feature** and morphological opening cannot see absent
  material. `WYRM_COMPONENTS == 1` is now asserted.
- **The mark is mirrored and centred on the face centreline, and it is not at top-left.** The
  creature is drawn facing left, so unmirrored its *tail* pointed at the mic port and the
  gesture ran off the face. Mirrored, the head faces the flare. Ink 7.700–33.351 plus the
  flare's right edge at 42.300 centres the group on **x 25.000** exactly, and that centring is
  **asserted** — every other check on this face is a clearance, and a clearance is satisfied by
  any amount of slack in the wrong place. The cost, accepted knowingly: this hands the creature
  relative to its other three renderings.
- **A mesh check that can actually fail.** The repo used to assert *"all parts watertight, 0
  non-manifold edges"* on a check that imported each STL with build123d and counted boundary
  edges — but `import_stl` returns a single `Face` with **zero edges and zero volume**, so the
  count was zero because there was nothing to count. Measured properly: **three parts are
  genuinely watertight; `ember-front-bezel` carries 3 non-manifold edges** inside a solid that
  is otherwise valid with zero boundary edges — coplanar-seam artefacts where the mark's 104
  stacked row-spans meet, which every slicer repairs. Recorded as a number
  (`KNOWN_NONMANIFOLD = {"ember-front-bezel": 3}`), not a threshold, and reported on every
  build. **Do not raise the baseline to make a build pass.**
- **A new figure, `site/renders/case-docked-rear.svg`**, wired into the site — the slab docked,
  from behind. It exists because a question was asked that no existing figure could answer.
- **Mic gain is a live control** (`number.ember_satellite_mic_gain`), where it used to be the
  compile-time `mic_gain: 36db` and every adjustment cost a reflash. **0–42 dB in 6 dB steps,
  and the hardware forces the step**: the ES8311's REG16 takes a 3-bit field with exactly eight
  legal values, so nothing between them is representable and a continuous slider would report a
  setting the codec cannot hold. It lives in the **single-press overlay beside volume**. The set
  action writes REG16 directly as well as calling `set_mic_gain()`, because the setter only
  assigns a member — the driver writes the register once, in `setup()`, so the setter alone
  would present exactly like a control that does not work. The restore path had the mirror-image
  fault (`TemplateNumber::setup()` publishes but never calls `control()`, so a stored value never
  ran its set action, and **the only value immune was the default**); fixed with its own `on_boot`
  trigger and verified by reading REG16 back, not by inference.

### The speaker took three revisions — read this before changing anything

It is a **sealed-back module**, 40 × 27 × 10 mm, **double-sided tape on the back**, JST-1.25
pigtail. Each revision was a confident design built on an assumption the model could not test:

1. ⌀28 round flanged driver in a recess — wrong shape.
2. 40 × 27 rectangle, shallow lip on the baffle — wrong mount.
3. Tape is on the **back**, the non-radiating face — this **inverts** the mount. The
   bonding surface cannot be the baffle. It is now a flat pad standing 0.80 mm proud of
   the chamber's **rear** wall.

Because the module carries its own rear volume, **chamber volume barely matters
acoustically**. The front path is the acoustic design — hence the deliberately small
2.50 mm diaphragm-to-baffle gap and the 37-cell grille solved to 673 mm² nominal — measured
(`enclosure/tools/grille_area.py`), the **throat is 607.8 mm² across 37 apertures** (−9.7 %, so
the driver's ~700 mm² is 86.8 % matched, not 97 %) and the **mouth is 715.9 mm² across the same
37 apertures**: at the current 0.25 mm flare the mouth web is 0.4670 mm, positive, so the face
is discrete holes and *not* the single merged opening earlier notes described. The nominal
figure describes the throat, which is the restriction that governs level. **Skip the
wadding** (nothing to damp); **still seal the joints** (to stop the *front* cavity venting
anywhere but the grille).

### Three faults booleans could never catch

All three found by rendering and looking; all three now asserted in `_check_geometry()`:

- **The stand covered 19.5% of the screen.** Slot floor at `z=10` put the stand 31.1 mm
  *along* the tilted slab; the visible area starts at 19.76 mm. Nothing intersected — the
  stand was simply *in front of* the screen.
- **No room for the USB-C plug.** 6 mm available, ~18–20 mm needed. Unnoticed because no
  figure ever showed a cable.
- **Both buttons were unreachable while docked.** Nothing intersected there either. The assert
  is now a 6 × 6 × 4 mm fingertip probe at each cap demanding under 1 mm³ of stand in the way —
  a centreline sample would have passed straight through a slot a finger cannot enter.

**A test that measures interference is blind to occlusion**, and *"does it collide"* and
*"can you get at it"* are different questions. Every feature a human has to reach needs its
own reachability check. `SLOT_FLOOR` is now 24.0, with a 22 × 22 mm USB-C well beneath the slot.

## Standing guards — run these, they are not decorative

| guard | asks | when |
|---|---|---|
| `esphome/tools/check_restore_resync.py` | can a restoring control lie about the hardware after a reboot? | pre-commit, on the firmware yaml |
| `site/check_generated_current.py` | is the built page in the same commit as its source? | pre-commit, on `index.src.html` / `PRINT-SHEET.md` |
| `site/check_served_current.py` | is what a **visitor downloads** what `origin/main` would produce? | **after a push** — never a hook |
| `homeassistant/tools/check_dashboard_deployed.py` | is the dashboard **HA is serving** the one in git? | after a dashboard change |
| `status.realm.watch/check_deployed_current.py` | are the checks **actually running** the committed ones? | after a `deploy.sh` |

⚠️ **`.git/hooks` is not tracked, so a fresh clone starts unprotected.** Install line in
[`docs/verification.md`](docs/verification.md). Each guard fires only when its own source is
staged — *a hook that runs on every commit gets disabled, and a disabled hook protects nothing.*

None of them deploys. Where a fix has a cost, the guard's job is to make the cost visible, not
to pay it on somebody's behalf.

## Open

- [x] ~~**Print it.** Start with `ember-front-bezel.stl`~~ — **done, and the bezel is correct.**
      It has stayed **byte-identical** through every change since, verified by `git diff` on the
      STL across three rebuilds. 0.48 mm was legible. **Next print is `ember-back-shell.stl`** (the
      fix), then optionally the stand and the never-printed `ember-stand-base.stl`.
- [x] **Debossed labels — DONE, in `86748c6`'s successor. All four cut, all four verified.**

      JP chose the **power symbol** (IEC 5009) for the small cap, which resolved the one open
      decision and did it better than text would have: a symbol is drawn geometry, so its
      stroke width is set directly instead of inherited from a typeface.

      | label | where | size |
      |---|---|---|
      | `SD` | flat back, margin strip beside the slit, reads bottom-to-top | ink 6.40mm cap |
      | `MIC` | flat back, beside the mic bore | ink 6.40mm cap |
      | `VOL` | big cap face (the microSD side, per JP's bench test) | ink 4.70mm cap |
      | ⏻ | small cap face (the mic side) | 6.30mm dia |
      | USB-C | **skipped** — no room, and a USB-C port is self-evident | — |

      All grooves **0.48mm = 3 × `LAYER_H`**, same three layers as `BEZEL_DEBOSS`. Stroke
      **0.90mm everywhere**, the repo's nozzle floor.

      **Two sizes, forced not styled.** The big cap is 13.27mm across flats, which caps a
      three-letter label at ink 4.70. The flat back allows 6.40 and **SD needs it** — at ink
      6.00 the S's upper counter pinches to 0.843mm, under the floor.

      **A hand-cut stroke font** (`tools/strokefont.py`), not `Text()`. At these sizes 0.90mm
      of stroke is a stroke/height ratio of ~0.19, heavier than any real typeface's Bold, so
      with an outline font the stroke width is a *consequence* you can only measure and hope
      about. Here it is an argument. Two glyphs are not monospaced and the CHECK said so, not
      taste: **M** at 0.52 advance puts a 0.43mm rib between its valley and its stem at any
      size that fits, and **I** in a full-width box reads as a word break.

      **Verified, not asserted:** back shell **23308 tris, watertight, 0 non-manifold**;
      clearance **0.000 mm³** with the self-test firing at 1467.842; bbox still **14.40** deep,
      so nothing is raised. Bezel, stand and base plate are **byte-identical** — JP's printed
      bezel and stand are unaffected. Every label proves its own material clearance at import
      (`_label_ok`), and `tools/strokefont.py --self-test` carries four controls.

      ⚠️ **The mirror.** The back face is seen from −Z, so model +X runs to the viewer's LEFT
      and every label is mirrored on placement. This was reasoned out AND then looked at:
      `tools/slice_svg.py` slices the STL mid-groove and draws it with the same flip the eye
      applies, so a sign error shows up as backwards text. All four read correctly.

      Note the build takes **~9 minutes** and did so before the labels too — it is the hex
      field plus the vendor-STEP clearance boolean, not the new work.

- [ ] Button feel is the thing most likely to need a second print — but **the knob is
      `HINGE_L_BOOT` / `HINGE_L_RESET` (1.20 / 2.00), not `HINGE_T`.** Strain is `(t/2)·θ/L`
      with θ fixed by pip travel over the pip's lever arm, so thickening a hinge to firm it up
      moves it *toward* fracture. Cap size is the *other* lever and it moves the right way:
      both hinges are at ~1.20% since the caps went thumb-sized. See "the hinges are sized by
      strain" below.
- [ ] Touchscreen X handedness is still unconfirmed, but it is now **one tap away**: the raw
      touch X is captured *before* the clamp and shown on the telemetry band's idle line for 3 s
      after a tap. Tap near each edge — that answers sign *and* range together, where watching
      which coal flares only ever answered sign. Mirrored ⇒ `spark_col` needs `59 - tx/4`.
      There is no `transform:`, no `swap_xy` and no calibration anywhere in the config, so the
      orientation is **unknown**, not known-and-adjusted.
- [x] **Ember is registered in `status.realm.watch`** — `status.realm.watch@99dcc78`, deployed
      and reading **up**. It is a **TCP check on the ESPHome API**, `ember-satellite.lan:6053`,
      not HTTP: the firmware declares no `web_server:`, so there is no port 80 and no
      `/api/version` to poll, and forcing it into the realm-sigil pattern would have meant
      inventing an endpoint. TCP 6053 is also strictly better than ping — it proves the
      firmware is accepting connections, which is what HA needs; ping only proves the radio
      answers.
      > ⚠️ Not `binary_sensor.ember_reachable`, which was the other candidate: that polls
      > `familiar.lan:8091/health` and measures the **inference backend**, not the device.
      > Its name and its subject are different things.

- [ ] **`docs/verification.md` needs a summary, not more entries.** It is ~1,470 lines and 24
      sections. The early ones are load-bearing; the newest are marginal, and **every marginal
      entry dilutes the ones that would change somebody's behaviour.** It wants a short
      *"the mechanisms"* table at the top with instances beneath. **Do not add sections without
      applying the bar: would this change what somebody does?** — not what they would find
      interesting, and not what demonstrates rigour.
- [ ] **Two questions are with JP** and nothing here unblocks them: (1) **which slicer** printed
      the bezel and whether it reported the 3 non-manifold edges — that is the only thing that
      upgrades the mesh sentence from *one print, one slicer* to a claim about the class; and
      (2) the **six frozen bezel predictions** in
      `scratch/hosyond-s3/bezel-calibration.md`, which change sheet numbers if the web
      prediction lands. **Refining analysis while waiting for an observation is not progress.**

Full crash-recovery audit with ranked findings:
`~/.claude/projects/-home-jp-Projects-familiar-realm-watch/scratch/hosyond-s3/loose-ends.md`

## Done and closed

- **Lyra's grille motif is landed**, not deferred. It was re-derived rather than applied: as
  delivered it was 11 spines over a 50 × 15 field with 190 mm² open, sized for the round ⌀28
  driver that no longer exists, and applied as-is it would have cost 72% of the open area. The
  rake, the thick-to-thin gradient and the capsule ends survive; the length taper was moved
  into width. The grille is now a 37-cell field solved to the same 673 mm² nominal as the plain
  array it replaced (throat measured at 607.8 mm², −9.7 %), so the choice between it and the
  ridge is aesthetic, not acoustic.
- The HA long-lived access token in `configuration.yaml` is **revoked and verified dead**
  (old token → 401, `ha-llat` → 200, Ember still reachable).
- `~/Projects/esp3d` created for the Ender 3 Neo work. **It has no git remote yet.**

## The lesson that kept recurring

**Rendering and looking beat reading the source, five times out of five.** The trash-can Buy
icon, the `preload="none"` that was a lie, the exploded view rendered edge-on, the buried
screen, and the buried buttons — every one was invisible in correct-looking source and obvious
in the output.

Two corollaries earned the hard way:

- **A test that cannot fail is not a test.** The clearance checker returned a confident `CLEAR`
  for a while because the STEP and the parts were in disjoint coordinate frames; only a
  deliberately-sunk bezel exposed it. That self-test is permanent now and must report
  **1467.842 mm³**.
- **A total can absorb a complete regional absence.** The bezel honeycomb's first run put 75
  cells in the chin and *none* on the rails, and the assert passed because it read
  `count ≥ 60`. Count the regions, not the total.
- **A constant with no consumer cannot be wrong in a way anything detects.** `SD_PLATE` was read
  only by humans — the openings it named were hand-typed literals — so nothing recomputed when it
  was wrong, and a 26.50 mm channel with 18.54 mm of nothing behind it passed every check, because
  every check compared the *part* to the *board* and an opening over an absent component is
  agreement. It is the **second** instance in one file, a screenful from the dead `GRILLE_SLOT_W`
  already written up here. **Knowing the failure mode did not prevent it.** Openings now derive
  from a component table, with the converse asserted.
- **When a rounded number *is* a clearance, the direction of the rounding is part of the
  constraint.** `round(..., 2)` on a solved island position spent 0.0003 mm of the clearance it had
  just computed — and the new assert caught it on its first run, which is the *first* fault in this
  file's history found by a check rather than by a person holding a part. It rounds *away* from the
  obstruction now. A value sitting on a boundary has no slack to round into.

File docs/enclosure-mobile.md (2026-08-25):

# Mobile variant — battery Ember

The handheld build: the same board and the same front bezel, with a single 18650 and the
speaker moved into the case. Issue [#44](https://github.com/jphein/ember.realm.watch/issues/44).

Source of truth is [`enclosure/ember_mobile_case.py`](../enclosure/ember_mobile_case.py). It
imports every board and shell number from `ember_case.py` rather than re-typing any of them, so
this document is a reading of that model and not a second copy of it. **Where the two disagree,
the model is right.**

> ⚠️ **Status: verified in CAD, nothing completed, nothing wired.**
> Both parts pass every check the desk parts do, including 0.000 mm³ interference against the
> vendor board solid. That is a geometry result. No cell has been in a bay and no joint has been
> soldered. The numbers marked **soft** below are the ones to distrust first.
>
> *A cover print was started and **cancelled at 2 %** on 2026-08-01, when JP's re-measurement of
> the protection strip landed and the locator ribs turned out to be 1.5 mm too close together.
> Nothing has been printed to completion, but the bed is no longer untouched — and that cancel is
> the cheapest thing in this document.*

---

## Headline: it is a backpack, not a redesign

Three printed parts, **one of which is unchanged**.

| Part | Source | Layer | Prints on | Volume |
|---|---|---|---|---|
| `ember-front-bezel` | **reused bit-identical** from the desk case | 0.16 mm | front face down | 7.33 cm³ |
| `ember-mobile-midframe` | **`ember_case.back_shell("mobile")`** + additive features | 0.20 mm | back face down | 21.54 cm³ |
| `ember-mobile-back` | new | 0.20 mm | **outer** face down | 27.24 cm³ |

Neither new part needs supports. The desk stand and its base are simply not used.

**The shared shell is variant-aware now**, which is new and worth knowing before you read the
figures: `back_shell()` takes a variant, and it decides *which flank openings are cut and
therefore which connector labels are truthful*. The desk blocks `BAT`; the mobile blocks `BAT`
and `SPK`, because its speaker lives inside the cover's sealed cavity and its pigtail leaves
through the SPK relief rather than the flank. One shell, two honest back faces — and §10 records
the side effect nobody designed, which is that closing `SPK` moved the glow window.

The board is clamped by **the same joint at the same plane** — the midframe's back face is held
at `BACK_Z = −9.70`, so bezel↔board↔midframe is the desk assembly, with the same four
M3 × 0.5 × 12 and the same 5.34 mm of thread engagement. That is the whole reason a deeper
back shell was rejected instead: `SCREW_LEN` is an under-head length, an M3×14 already bottoms
out against the pilot's end, and deepening the shell moves the counterbore 21.80 mm further from
the pilot — invalidating the derivation while still looking like it works.

**Removing the cover does not disturb the board.** The cover carries no board load, which is what
makes one-screw cell access real rather than nominal.

| | Mobile | Desk |
|---|---|---|
| Envelope | **55.90 × 91.90 × 39.00 mm** | 55.90 × 91.90 × 17.40 mm |
| Thin section (y < 18.00) | 17.40 mm — unchanged | 17.40 mm |

Width **cannot** move: the bezel is untouched. **And length no longer grows at all** — §1 is about
how that closed after three revisions of it not closing.

---

## 1 · There is no lip. The envelope is the desk case's, to the hundredth.

```
55.90 × 91.90 × 39.00        mobile
55.90 × 91.90 × 17.40        desk
```

**Y is identical.** `MOB_OY1 == OY1 == 88.95`, asserted exactly — the backpack is the desk slab's
footprint with depth behind it and nothing else. Width never could move, because the bezel never
moved. Length now doesn't either.

> **JP: "no litle lip in backpack figure it out pls."**

That instruction arrived after three rounds in which the case was 3.05, then 1.32, then 1.73 mm
longer than the desk profile, each time for a reason that was correct at the time — the coil
spring, then the corner fillet the coil had been paying for by accident, then the strip's own
housing.

### How it closed: the conflict was MOVED, not reshaped around

Every earlier attempt had tried to *fit* something into the contested corner. This one moved the
contest instead:

| | |
|---|---|
| `CELL_WALL_X` | **3.678**, given its own name — it had been two separate jobs of `COV_WALL` |
| `NOLIP_ROLL` | **0.30** on the void's plan corner |
| Divider | **1.60** |
| Driver | **+1.078** to `DRV_CX` 36.778 — which lands it *centred* in its usable span |

⭐ **And one of those numbers is a derivation beating an estimate.** `NOLIP_ROLL` is 0.30 because
that is `CELL_BORE_CLR` — the **seat guarantee**: at any radius above 0.30, a cell with no roll of
its own cannot seat. JP's suggestion was *"~0.5mm"*, a visual estimate from the render. **The bound
wins, and it wins by being a bound rather than a preference.** His eye had been right four times
this week about *where* to look; this is the case where the arithmetic was right about *how far*.

### The assert that makes the lip's return audible

The plan-view bound that killed every earlier shape now reads closed, and it is asserted **both
ways** — cut-available ≥ bezel-need, *and* `MOB_OY1 == OY1` exactly.

> **If either fires, the failure message says "the lip is back" in those words.**

That is the right shape for an assert guarding an *aesthetic* requirement the owner stated in
plain language. A numeric tolerance failure would be true and unreadable; this one fails in the
vocabulary the requirement was given in.

## 2 · The X budget closes exactly

```
interior 51.50 = cell bore 19.40 + shared divider 2.00 + rim span 30.10
```

The divider is **one wall doing two jobs** — the cell trough's inboard wall *is* the seal rim's
inboard wall. Two walls do not fit. The driver's 28.20 mm tape footprint in a 30.10 mm rim leaves
1.90 mm total, 0.95 per side (assert floor 0.50).

`COV_WALL = 2.20` rather than the family's `WALL = 2.60`, for two converging reasons: at 2.60 the
budget does not close, and the cover's outer wall **is** the grille baffle, so `COV_WALL ==
BAFFLE_T` makes the acoustic port length identical to the stand's by construction. It is
asserted. *Do not "fix" a failure there by editing `BAFFLE_T`.*

---

## 3 · Bill of materials

| Item | Spec | Notes |
|---|---|---|
| Cell | **1 × bare flat-top 18650**, ⌀18.80 max incl. wrap | **Bare only.** Protected/button-top cells are out of scope — see §5. 3400 mAh assumed for the charge figure. |
| Cell contacts | **none to buy** — both ends are folded-excess **leaf springs** formed from the strip's own nickel tabs | Free height 3.60, closed 0.75. There is no coil spring and no `+` plate any more: the parts list got *shorter* as the design got harder. |
| Protection strip | **1S DW01-class + dual FET, tabs pre-welded** | ⚠️ **Required, not optional** — see §6. Body **21.50 × 4.50 × 2.50**, flat assembly **90.00**, tabs 34.25 each. **All JP-measured — no placeholders left.** It lies flat beside the cell; see §7. |
| Pigtail | JST 1.25 mm 2P | strip `P+`/`P−` → the board's `BAT` connector. |
| Cover screws | **2 × M3 × 0.5 × 22 ISO 4762** (cap head) | 2.5 mm hex key, 3.40 mm engaged in a 6.60 mm pilot. ⚠️ Briefly **M3×25** while the bay was 1.60 deeper (§7b); the growth was reverted and so was the screw. **Take the length from the build's own shopping line, not from a memory of this table.** |
| Bezel screws | 4 × M3 × 0.5 × 12 ISO 4762 | Unchanged from the desk build. |
| Driver | 40 × 27 × 10 mm sealed-back module | Carried over. Double-sided tape on its **back**. |

Retention is **two M3 × 22 screws driven straight down, and the cover's own box section**.

| | |
|---|---|
| Screws | a shared lane at **x 23.55** — chin **(23.55, 22.60)**, top **(23.55, 85.98)**. ⌀9.00 boss both ends, 6.60 pilot, **3.40 mm engaged** |
| Top screw placement | set by `SCREW_BOSS_D/2 + 0.20`, **not** by `SCREW_EDGE_MIN` — the boss is wider than the counterbore, and when it was placed by the counterbore rule it stood **0.30 proud** of the end face |
| The rest of the edge | carried by the cover's **21.60 mm closed box section**, not by fasteners |
| Worst unheld point | **43.19 mm, at (52.95, 54.34)** — mid-span of the **+X** long edge |

**Two screws is JP's cap, and the budget above is what that buys.** The lane sits 26.50 from the
−X edge and 29.40 from the +X, so pushing it inboard — which the protection strip forced —
*inverted which long edge is worse*. The +X edge is now the weaker one, and it is also the only
one that could ever take a third fastener: −X can never take one at any y, with the cell bore
below and `SCREW_EDGE_MIN` above.

> **A third screw is now possible, and is deliberately not proposed.** It was the protection
> strip that made a second top screw impossible, and the strip has since moved to the lower band,
> so the upper compartment is empty. One at roughly (46, 82) would halve the +X worst case. It is
> recorded here only so the constraint that used to forbid it is not re-derived from scratch by
> the next person — **the cap is JP's call, not an oversight.**

### This is the third retention scheme, and each was killed by a different kind of argument

| scheme | killed by |
|---|---|
| two undercut hooks | **printability** — a 0.60 mm lip bridging its own 0.80 mm slot |
| a dovetail rail | superseded when the whole retention approach was reconsidered |
| **two screws + box section** | *(built)* |

Worth keeping the shape of those failures rather than just the outcome. The hooks' fit was
asserted and their **printability was not** — the same distinction as the stand grille's webs
(#47), and the second time this project has paid for it. Every `HOOK_*` and every `DT_*` constant
is **deleted** rather than commented out, so no scheme can be reinstated from a note.

### Moving a screw is what found a real defect at the screw that did not move

The chin screw was investigated for relocation and **stayed at (23.55, 22.60)**. The investigation
was still worth it, because it exposed something at the *unmoved* position: the nearest surviving
hex cell left **0.80 mm of web** against a **1.60 mm floor** — at a **thread-forming** screw, which
expands material radially as it goes in. Thin web plus radial expansion is a split.

So the mobile now drops **two hex rows, not one**: the row whose cells at x 23.00 and 27.00 overlap
the chin pilot outright, and the row whose cell at x 25.00 left that 0.80. The desk keeps all 113
cells and stays byte-identical — this is a mobile-only subtraction. A new **`[collar]` probe**
asserts a full `MIN_SOLID` collar at both screws, and its **control in the open hex field reads
35 % and is correctly rejected**.

*The useful shape: a question asked about one feature ("can this screw move?") returned an answer
about a different one ("this screw is unsafe where it is"). Investigations are worth finishing even
when the answer is no.*

**Location lips were considered and are arithmetically impossible.** A lip needs
1.60 + 2 × 0.35 clearance + 2 × 1.60 skin = **5.50 mm of wall**. The cover has 2.20 and the
midframe's floor outboard of the board pocket has 2.60. **Short by 2.90** — not a tuning problem,
and the same shape as the −X dovetail elimination before it.

---

## 4 · Assembly order

The order matters, and the first two steps are the ones the geometry was arranged around:

1. **Lay the strip body flat in its channel beside the cell lane**, fold both tabs, and seat the
   leaf ends. The body goes in **before the cell**, and the cell **drops on top of it** — which is
   why the bay's growth was designed to land at the *bottom* when growth was still on the table.
   Nothing is threaded down beside a cylinder that already fills the bore.
2. **Solder the output wires on the body's +X side**, then thread them to the chin pass. That side
   sits past the cell's surface, so the joints live where their thickness is not a dimension anyone
   has to know. Everything is still open from above here — solder access is a property of *this
   ordering* and of nothing else.
3. **Tape the driver** to the midframe's back face, inside the locating groove (0.60 deep, 1.20
   wide, outline only — the tape does the work; a pocket would leave the bond bridging a step).
   That face is a printed **bed face**, the flattest plane in the project, so unlike the desk stand
   there is no proud pad.
3. **Route the driver's leads** through the SPK relief. ⛔ **Then seal that relief** — silicone, hot
   glue or putty. It opens into the sealed cavity, and it is asserted to lie *wholly inside* the rim
   rather than straddling its wall, because a straddled opening cannot be sealed at all.
   ⚠️ **And note what §7d says about that plug: it is half the seal, and it is the half the model
   cannot see.**
4. **Fit the board and bezel** exactly as the desk build.
5. **Drop the bare cell on top of the seated strip.** Both ends land on leaf springs. There is no
   plate to orient against any more, so read the debossed marks — and see §5 for why they are not
   mirror images of each other.
6. **Seat the cover and drive both M3 screws.**

## 5 · Cell bay

| | |
|---|---|
| Bore | ⌀**19.40** (⌀18.80 max cell + 0.30/side), axis at (x 8.95, z −19.40) |
| Bay | y **20.20 .. 89.80**, `BAY_L` **69.60** |
| Cradle | half-cylinder, concave, self-supporting — the cell self-centres |
| Spring bore | ⌀**9.00** for a ⌀8.00 spring, capped by a **53.13° gable** rising 6.00 over the 4.50 half-bore |
| Contacts | a **10 × 10 × 0.25** stamped plate in a **0.35 kerf** with a **0.15 detent** to hold it, 0.10 of play |
| Spring | shortest cell 64.90 → 4.10 occupied, 2.90 compressed (still preloaded); longest 65.50 → 3.50, 1.00 clear of coil-bound |

### ⚠️ There is no mechanical reverse-insertion protection, and there cannot be

The previous revision had a real one: a ⌀7.00 aperture that a protected cell's **raised** positive
button passes and a flat can-face does not (blocked a reversed cell by 144.6 mm³, passed a correct
one at 0.00). It was **deleted**, because JP uses bare cells only — *"no protected tops"* — and on
a bare flat-top **both ends are geometrically identical**. Any aperture that stops a reversed cell
stops a correct one. This is not a matter of finding a cleverer profile: *the information is not
present in the geometry.* Left in, the feature would have rejected the only cells its owner owns.

It was removed rather than commented out, so nobody reinstates it from a note.

What replaces it is **markings only**: `+` and `−` debossed 0.60 mm deep, 2.80 mm tall, 0.90 mm
groove. **`+` sits at y 86.95** on the high-Y end wall; **`−` sits at y 19.10 — on the cover's
mating face, not the bay wall.** **That is weaker and the docs will not call it protection.**
Making reverse insertion *safe* is electrical, and it is unbuilt.

### ⚠️ The "−" mark was debossed correctly, and could not be seen

Both marks were cut to spec and both passed the deboss check — the one that bounds debossed volume
against ink area from *both* sides, which is a good check. **The `−` was 34 % visible**, because
the folded nickel leaf now sits in front of it. Nothing about the geometry was wrong: the mark was
there, at the right depth, in the right place, and a person putting a cell in could not read it.

**This is a different failure from an assertion that cannot fail.** This one *could* fail and did
not, because it was asking about **volume** when the thing that mattered was **sightline**. Check
15 gained a **visibility lens**, with the old geometry kept as its rejected control.

The fix is an asymmetry, and **the asymmetry is the finding**: `−` sits on the cover's mating face
at y 19.10 while `+` is on the +Y bulkhead's bay face at y 86.95. *A design that kept them
symmetric for tidiness would have kept one of them invisible.*

> ⚠️ **The original reason for that asymmetry has since expired, and the asymmetry has not.** It was
> justified by the two ends being unlike each other — a nickel leaf in front of one, a flat contact
> plate in front of the other. **Both ends are leaf seats now**; the `+` plate was retired when the
> strip's own tabs took over both contacts. So the positions are still what the model builds and
> still what the build reports, but the *stated reason* no longer distinguishes them.
>
> Recorded rather than papered over, because the tempting move is to invent a fresh justification
> for a position that is already correct — and a rationale reverse-engineered to fit an existing
> feature is indistinguishable from one that was designed. **If the low-Y mark is still the only
> obscured one, that is a measurement someone should take rather than a sentence someone should
> write.**

*(The check on those glyphs is worth knowing about: the repo's stroke-gap probe returns `inf` for
both — `+` because its strokes cross, `−` because it is a single stroke — so a `gap ≥ width`
assert passes on any glyph of that shape, sound or broken. It is asserted to stay vacuous, and the
real test bounds the debossed volume against ink area from **both** sides.)*

**soft:** a ⌀18.80 cell in a ⌀19.40 cradle has ~0.30 mm of radial slop, held endwise by the
spring rather than radially. A foam shim or a printed rib removes it. Neither is built, because
there is no cell in hand to measure the rattle.

---

## 6 · Charging and power

**The board charges the cell itself. The default build needs no charging hardware.**

| | |
|---|---|
| Charger | **TP4054** (U2), PROG `R12` = 3.3 kΩ → **~290 mA** |
| Charge time | **15.8 h** for 3400 mAh (`3400 × 1.35 / 290`; the ×1.35 is the vendor doc's own implied CC/CV factor) |
| Power path | SL2305 P-FET + B5819W Schottky — plugged in, the system runs from VBUS and **the full charge current still goes to the cell** |
| Level sense | 200 kΩ / 200 kΩ divider → `BAT_ADC` |

Overnight, and stated up front so nobody files it as a fault later.

### ⛔ There is no protection IC on the board. `BAT` goes straight to the cell.

Confirmed against the [vendor schematic](vendor/ES3C28P_Schematic.pdf), after searching the docs,
the model and the firmware for `DW01`, `FS312`, `8205`, BMS, over-discharge and low-voltage and
finding nothing. The battery area of the sheet is exactly two blocks: charge management and level
detection. That is all.

**"It browns out first" is the wrong reading.** With a bare cell the only over-discharge floor is
the ME6217 LDO's dropout: the device stops working around 3.4 V and **then keeps draining** —
roughly **9 µA** through that divider alone (3.7 V / 400 kΩ) plus quiescent draw. A cell left flat
in a drawer goes to zero, and a Li-ion cell taken to zero does not come back. Hence the strip is
**required equipment**.

Also from the sheet, for the record: amp SC8002B, codec ES8311, mic LMA2718B381, 2 × ME6217C33.

### The TP4056 trade, frozen

A ~1 A TP4056 module would charge in 4.6 h. **It does not fit, and the model proves it rather than
claiming it** — the free compartment is 30.10 × 13.40 and the module's short axis is 17.00, so it
fits in neither orientation. Its phantom is kept in the file so the boolean reports **299 mm³ of
interference** on every run.

Restoring the pocket costs the **5.90 mm** that switching to bare cells saved — the same length
the protection strip now occupies. JP froze it on 2026-08-01: **the case stays as short as it is, in-case
fast charging is out**, because with bare cells the missing protection is the sharper gap and
removable cells can be fast-charged in an external bay charger. This **reversed** an earlier call
to keep the TP4056 pocket; recorded rather than quietly absorbed.

⚠️ **And a hazard the CAD deliberately does not decide:** two chargers on one cell — the board's
and a TP4056 — means plugging in both ports puts two CC/CV controllers on the same cell, fighting
each other. Moot as built. It returns the moment anyone buys the pocket back.

⚠️ **No boost, so no graceful shutdown.** On battery the `+5` rail is the raw cell; the device
browns out rather than shutting down. Single-sourced. Firmware's problem, not the case's — though
the device already publishes battery voltage, so the hook for a low-voltage cutoff exists.

---

## 7 · Where the protection strip lives — and the four days it took to find out

All three of its dimensions are **JP-measured** now: **21.50 × 4.50 × 2.50**, plus the flat
assembled length **90.00**. *There are no placeholders left in this section*, which is worth saying
explicitly because for most of this design's life the strip was the one part described entirely by
estimates.

| | |
|---|---|
| Home | **flat on the bay floor, beside the cell**, in the space the divider used to occupy |
| Footprint | x **16.15 .. 20.65**, mid-bay at y **42.83 .. 64.33**, channel z −29.10 .. −26.20 |
| Cell clearance | **0.46 mm** over the seated body |
| Tabs | **34.25 each** → **22.62 run + 11.63 fold** per end = **3.2 limbs**; *both* ends are folded-excess leaf springs |
| Solder joints | on the body's **+X half**, which sits past the cell's surface (18.35) entirely |

**Mid-bay is not a placement, it is the reason the arithmetic closes.** The tabs are a fixed
34.25 mm each and the case cannot grow, so the only way both ends reach their seats *with no added
nickel* is to start from the middle. Put the body at either end and one tab runs out.

### The solder problem was answered by placement, not by clearance

JP's own objection to a strip inside the bay was the joints: solder has thickness, nobody has
measured it, and a 0.15 mm tab plus a blob is exactly the kind of dimension that turns out to
matter after assembly. The answer is that the body's **+X half is past the cell's surface
altogether**, so the joints live where thickness never becomes a dimension anyone has to know.
*The good version of a tolerance problem is the one you arrange not to have.*

---

## 7b · Five constructions were measured dead before this one worked

This is the longest single argument in the design, and it is worth keeping in full because at two
separate points a **correct measurement pointed at the wrong conclusion**.

**First it was declared impossible.** The cell bore is inscribed in the bay *exactly* — measured,
not estimated:

```
-X extreme   -0.75  vs CELL_X0  -0.75     gap 0.00
+X extreme   18.65  vs CELL_X1  18.65     gap 0.00
bottom      -29.10  vs CAV_Z0  -29.10     gap 0.00
seated top  -10.30  vs BACK_Z   -9.70  -> 0.60 of headroom
```

Tangent on three sides. That is the X budget closing, not slack anyone forgot — and a strip needs
its thickness *somewhere*. So the strip was recorded as blocked and left in the chin band.

### ⭐ Then JP asked the question that broke it open

> **"the lid is flat teh battery is round isn't there space?"**

Yes. And the reason nobody had seen it is the most useful sentence of the round:

> **A correct measurement of the wrong feature reads exactly like a correct measurement.**

The extremes had been measured against the envelope and the bay called full. But **a round bore in
a square bay leaves four corner solids** — 4.53 mm of diagonal at the top pair, 4.11 at the bottom.
The measurement was right. The feature was wrong. Nothing about the number was suspicious, which is
precisely why it survived: *there is no tell.*

### And the corner still wasn't the answer

Building it there needed **BAY_EXTRA 1.60** of growth — less than the 2.50 first priced, because the
corner does four fifths of the work. That version was built, gated, and **rejected by JP on the one
line he had held all night: the case stays flush at 39.00.**

So the final answer went the other way — take the **divider** instead, since he had already granted
"or modify it". Every alternative was measured before that call, and **none closes at 39.00**:

| construction | why it fails |
|---|---|
| corner solid, axis-aligned | **−0.73 mm** — and no rotation satisfies both bounds |
| midframe straddle | **−0.21 mm** |
| upper compartment | fits, but puts the body **74.70 mm of tab-path** from the far seat: **52.08 mm of new nickel** against 23.25 of surplus |
| growing the case | works, and costs the flush envelope |

*Four of those are arithmetic and the fifth is a value judgement. Only the owner could make the
fifth one, and he did.*

---

## 7c · The wall came back — and it took six positions to get there

The divider is whole again, plus a **separator wall JP designed himself**, and this section has been
rewritten more times than any other in the file. That is the record, not churn:

| | the wall was | why |
|---|---|---|
| 1 | present | one wall doing two jobs — cell trough and chamber |
| 2 | deletion granted | "the band is empty with the strip in the bay" |
| 3 | **held** | a tangency measurement falsified that premise; the cut was *not run on a dead premise* |
| 4 | deleted | the corner pocket made the band genuinely empty again |
| 5 | middle removed, two stubs | the strip needed the span, and flush would not close any other way |
| 6 | **whole, plus a double separator** | JP's own construction, once he saw room for it |

**Every one of those six has a stated reason and a measurement behind it.** A design that moves six
times under measurement is not indecisive — it is one where nobody was allowed to guess.

### ⚠️ A correction to what this document said at position 5

The previous version of this section reported **one** opening, 584 mm², and called it *"a second
mouth roughly the size of the intended one."* **That was incomplete, and the reason is worth more
than the correction.**

Check 7b was printing the divider's **cross-section** — 2.00 × 19.40 = 39 mm² — as the opening the
wall left behind. But the opening is the face the wall **vacated**: its Y span by its height,
**869 mm²**. *Off by 22×, in the one number the owner judges the acoustic trade by.*

> ⭐ **A wrong area is worse than no area, because it gets trusted.**

With the right figure the trade read differently: **869 against the grille's 562.7 — half again the
chamber's intended mouth — on top of the low-Y wall's 584.** The intended mouth was the *minority*
of the aperture, and the cell and the BMS were inside the acoustic volume. **That is a materially
different decision from the one this document described**, and it described it in good faith from
the number the build printed.

*It is corrected here rather than quietly overwritten, because a document that silently starts
saying something else is the same hazard one layer up from the check that misreported.*

### The separator wall, and the thinnest solid in the family

The −X opening now measures **0.000**. JP's construction is a **double wall**: a partial wall, plus
a stepped full wall at **0.90** that thins to **0.50** in the band beside the strip.

**Both are below the 1.60 minimum-solid floor and both are recorded as experimental**, with the
distinction stated rather than blurred:

- **0.90 (2.25 extrusions)** — under the floor, but a **vertical wall supported along its whole
  44.80 mm bottom edge** is a different class from #47, whose collapsed 0.90 was an *unsupported web
  spanning a bore*.
- **0.50 (1.25 extrusions)** — **the thinnest solid in this family**, thinner than an already-flagged
  label groove is *wide*. ⭐ **Its thickness is set by the strip, not chosen:** 0.50 is the entire
  lane between the strip's +X drift and the driver's locating groove. There was no number to pick.

> **Cost of failure, stated because it is what makes the experiment acceptable:** a floppy or absent
> wall, trimmable with scissors. **Nothing structural depends on it.** That is the difference between
> an experiment and a gamble — and *the print is the verdict*, exactly as the 1.25 web was.
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

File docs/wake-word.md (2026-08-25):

# Wake word

Status: **flashed and heard.** Ember answers to **"Okay Nabu"**, detected on-device.

> This line read *"wired and compiled, never flashed"* until 2026-08-25, which was stale
> — the YAML's own substitution block records the flash: JP confirmed "Okay Nabu" on the
> desk unit 2026-08-03, and ember-mobile's first flash came up clean the same day. The
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

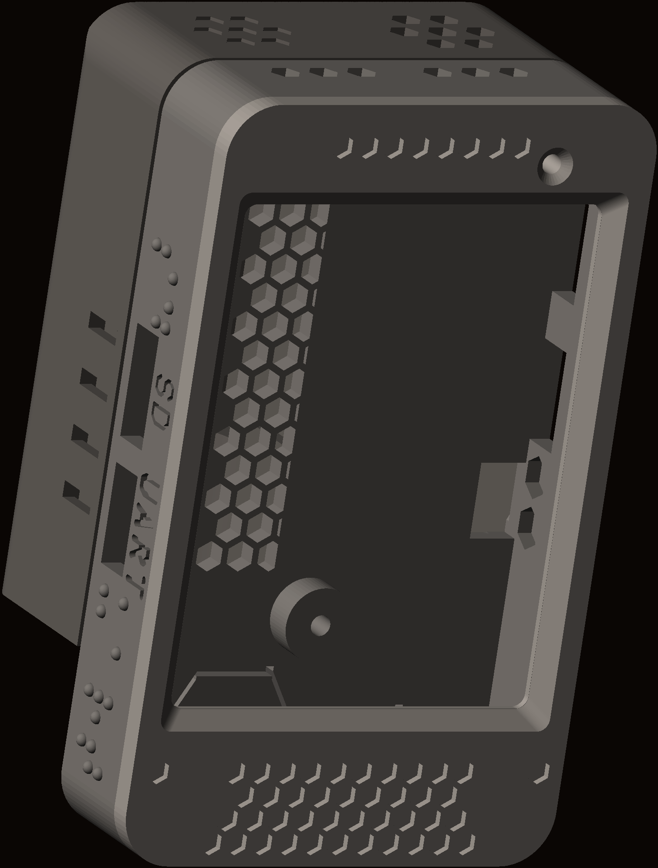
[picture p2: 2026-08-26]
site/renders/mobile-hero.png

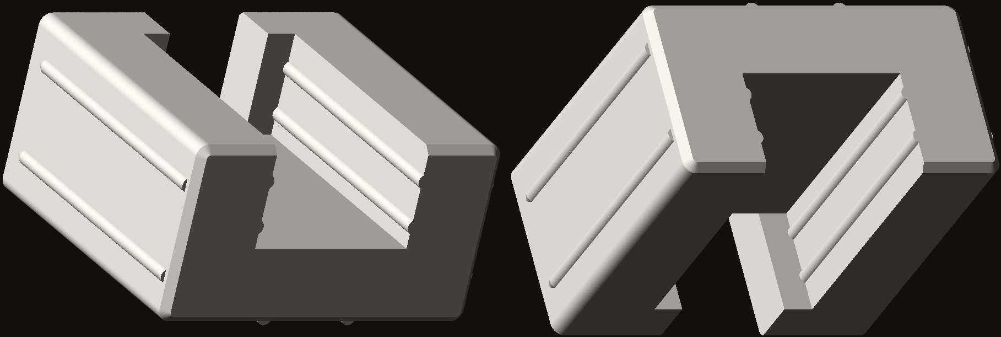
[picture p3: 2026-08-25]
site/renders/plug-cradle.png

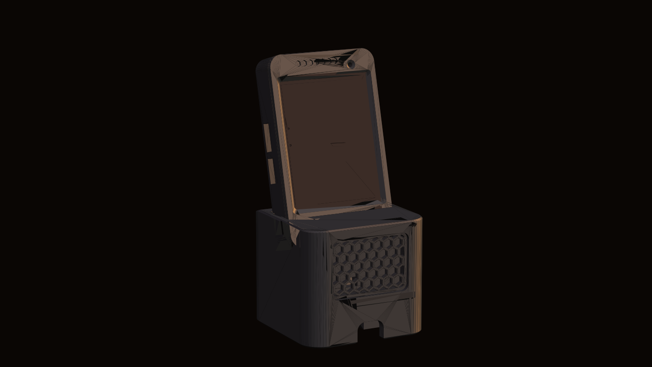
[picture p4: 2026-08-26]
docs/assets/case-hero.png

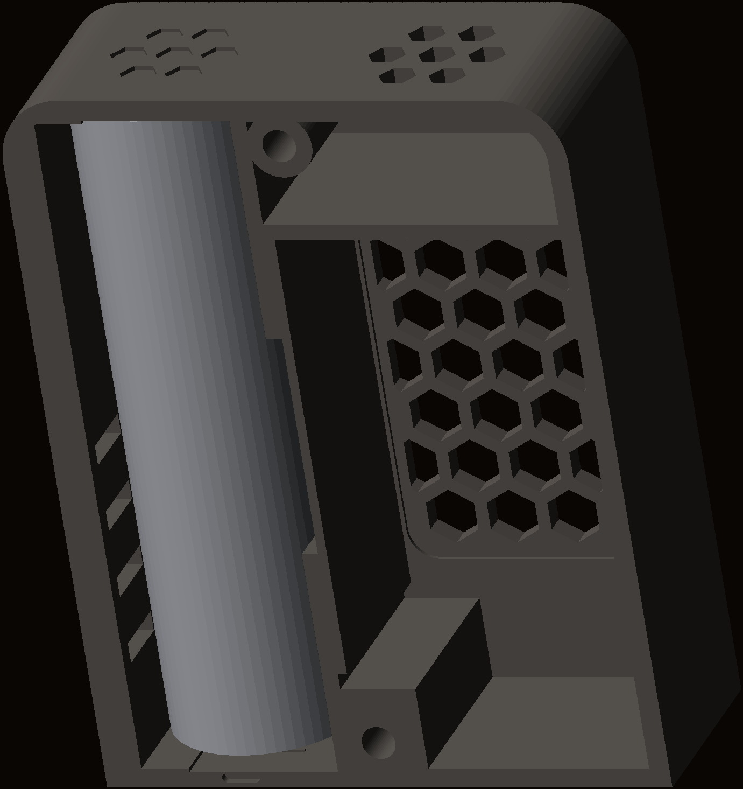
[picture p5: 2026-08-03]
site/renders/mobile-cover.png

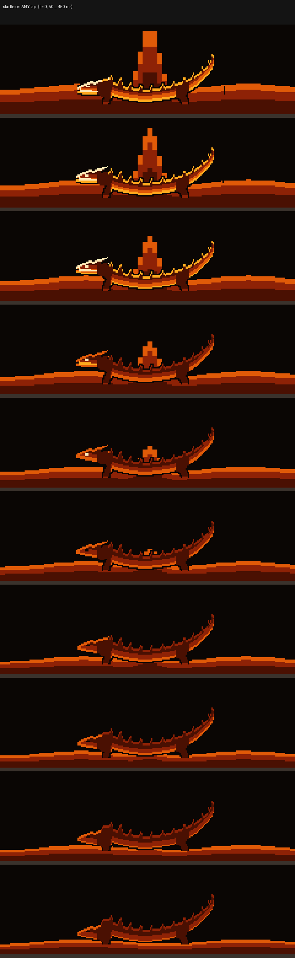
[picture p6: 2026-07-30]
docs/assets/wyrm_startle_shipped.png

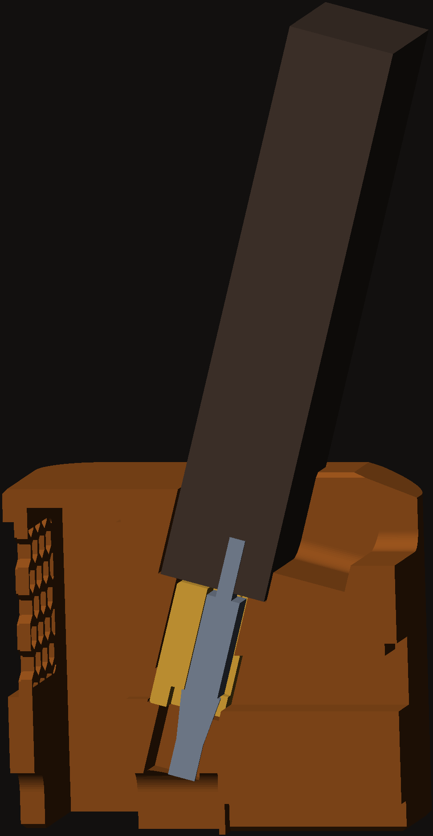
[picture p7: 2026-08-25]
site/renders/plug-cradle-cutaway.png

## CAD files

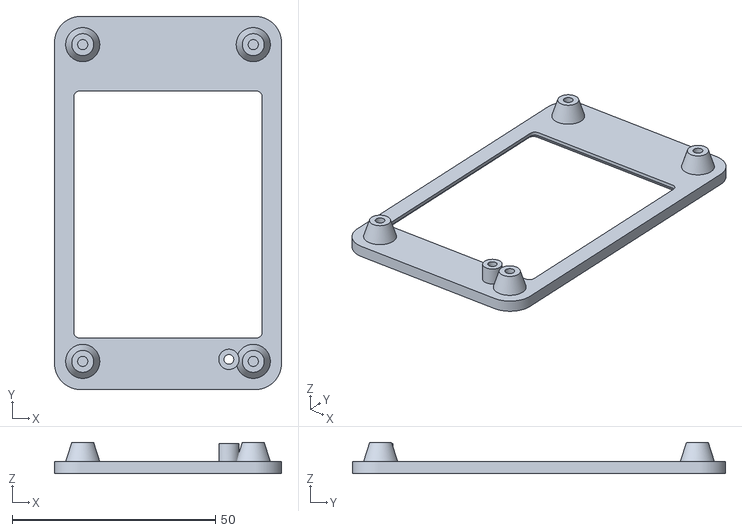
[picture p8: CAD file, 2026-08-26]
enclosure/ember-front-bezel.stl
55.9 x 91.9 x 7.70

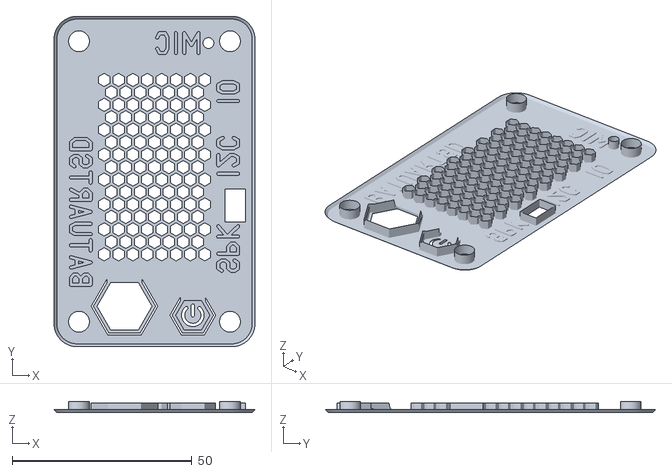
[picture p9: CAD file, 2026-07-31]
enclosure/tests/fixtures/back-shell-chamfered-wordgap-0.80.stl
55.9 x 91.9 x 3.00

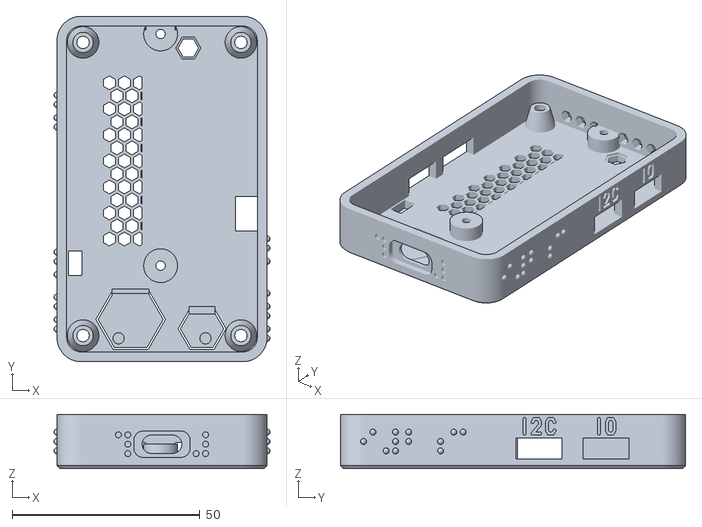
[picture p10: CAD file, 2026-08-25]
enclosure/ember-mobile-midframe.stl
57.5 x 91.9 x 14.4

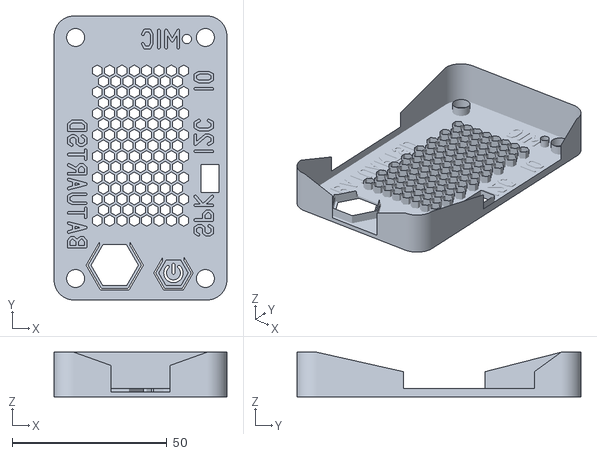
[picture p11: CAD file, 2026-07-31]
enclosure/tests/fixtures/back-shell-wordgap-0.80.stl
55.9 x 91.9 x 14.4

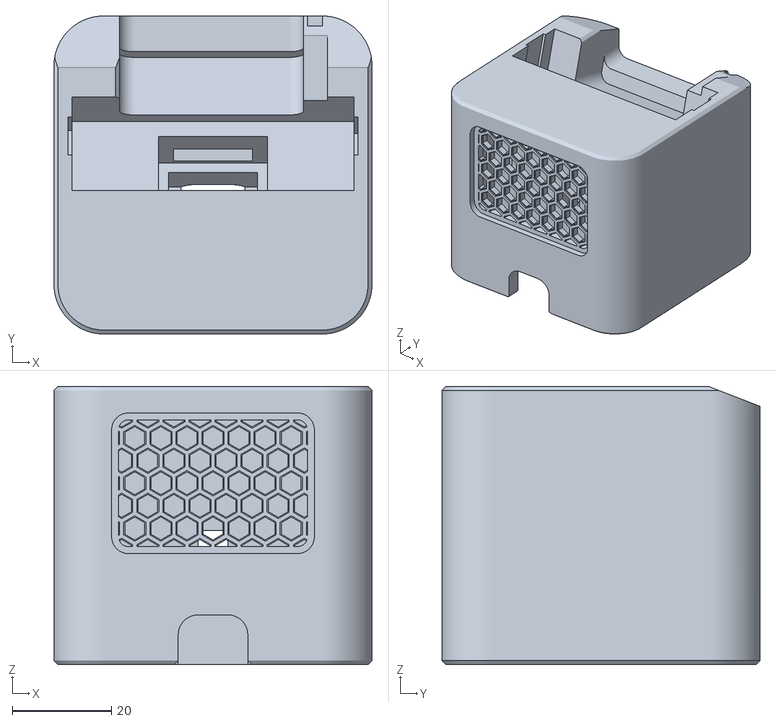
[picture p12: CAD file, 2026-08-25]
enclosure/ember-stand.stl
64.0 x 64.0 x 56.0

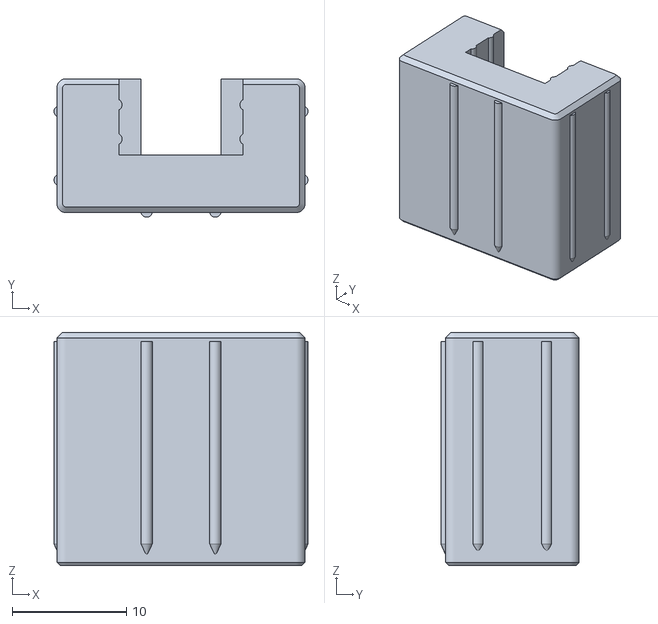
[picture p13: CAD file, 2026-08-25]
enclosure/ember-plug-cradle.stl
22.2 x 12.1 x 20.4

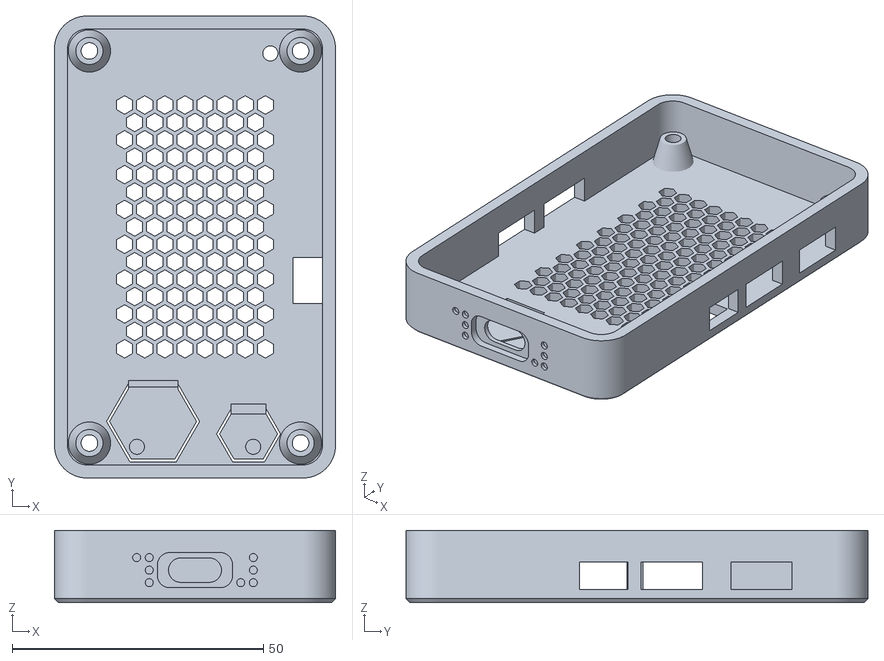
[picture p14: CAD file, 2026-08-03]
enclosure/ember-back-shell.stl
55.9 x 91.9 x 14.4

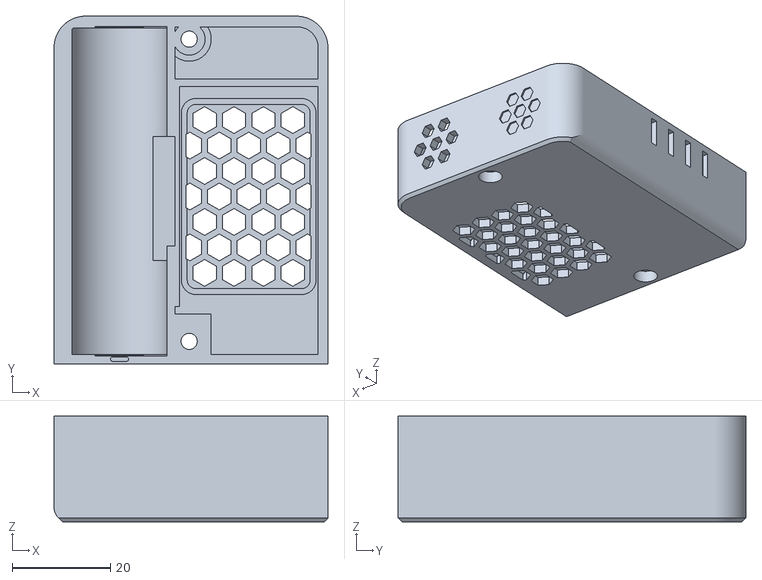
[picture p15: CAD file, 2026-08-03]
enclosure/ember-mobile-back.stl
55.9 x 70.9 x 21.6

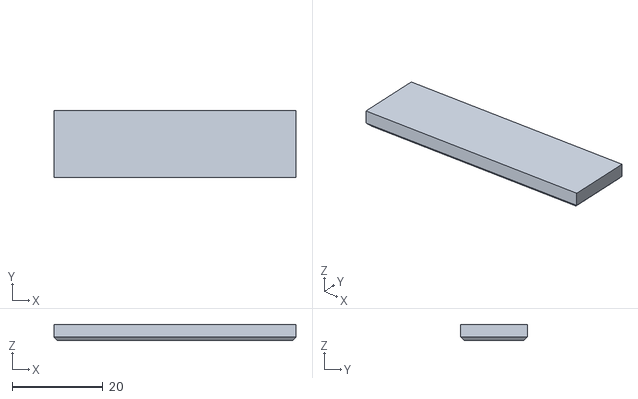
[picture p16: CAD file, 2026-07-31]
enclosure/ember-stand-base.stl
53.4 x 14.7 x 3.60

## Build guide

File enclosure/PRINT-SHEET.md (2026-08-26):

# Ember satellite case — print sheet

## ⚠️ WHICH FILE DO I PRINT — `enclosure/print/`, always

One file per part, the revision and content-sha in the filename, e.g.
`ember-front-bezel_r2_5f3fc539.stl`. The build refreshes this directory on every
successful run (it is the last step of `ember_case.py`'s gated commit), so it cannot go
stale by someone forgetting a step. Higher `r` = newer, readable straight from a slicer's
file picker — which is the interface where `enclosure/ember-front-bezel.stl` and a frozen
copy of the same name are indistinguishable, and on 2026-07-31 nearly got the superseded
bezel printed twice.

- `python3 tools/print_queue.py status` — what needs printing (⛔ REPRINT / 🖨 / ✅)
- `python3 tools/print_queue.py printed <part>` — record a finished, validated print
- History: git + `printed/<date>-…/` archives. The queue never holds old revisions.
- Prints run via OctoPrint on `serialhub` (USB-serial to the Ender 3).

> # ✅ CLEARED — `ember-stand-base.stl` seats. Fixed in `89001ea`. **REPRINT IT.**
>
> ⚠️ **If you printed the base plate before this, it is the wrong part — reprint it.** It was
> **1.40 mm too deep** and the sealed speaker chamber could not be closed with it. It is
> 2.8 cm³, the fastest part on the sheet.
>
> Re-measured here on the rebuilt solids, the same two ways the warning was raised:
>
> | | before | after |
> |:--|:--|:--|
> | plate Y extent | 4.30 – **20.70** | 4.30 – **19.00** |
> | interference with the stand | **269.136 mm³** | **0.000 mm³** |
> | plate size | 53.40 × **16.40** × 3.60 | 53.40 × **14.70** × 3.60 |
>
> **The cause is the part worth keeping.** The plate's `20.7` was `21.00 − 0.30` — the chamber's
> rear wall *was* 21.0 and 0.30 was the plate's clearance. That wall later became a *derived*
> value (baffle + front gap + driver body + tape pad = **19.30**) and **the plate kept its
> private copy of the old number.** The plate is now derived from the same constants and
> asserted, with a self-test: pushing it 0.5 mm deeper must be *detected*, because `0.000` is
> also what a broken detector returns.
>
> **Nothing in the build could have caught it.** Every clearance check compares a part to *the
> board*, and this plate never goes near the board; the mesh checks look at one STL at a time.
> **A part too big to fit its mate intersects nothing anybody was measuring.**

> # ✅ CLEARED — `ember-stand.stl` is printable. Fixed in `338a900`.
>
> This block used to read **DO NOT PRINT `ember-stand.stl` YET**: the speaker-wire pass into
> the sealed chamber was blocked by a 0.50 mm skin of the tape pad, leaving a slit ≈5.9 mm
> wide × 0.40 mm tall where a 1.2–2.0 mm lead has to pass. The pass was cut from y = 19.0,
> which is *behind* the pad's inner face, so the pad survived as a membrane over the mouth.
>
> Re-measured in the rebuilt mesh by the same ray-cast, so the numbers are comparable rather
> than two different questions:
>
> | | before | after |
> |:--|:--|:--|
> | Clear aperture into the chamber | **2.37 mm² of 30 (7.9 %)** | **28.69 mm² (95.6 %)** |
> | The blocking membrane | 0.474 mm, 12.4 mm³, 23 layers | **gone** — clear at z 6.5 / 8.0 / 10.0 |
> | Thinnest feature in the stand | 0.474 mm | 0.600 mm, 0.01 mm²/layer (a pre-existing 1-pixel corner) |
> | Features below 0.60 mm | 1 | **0** |
>
> The cut is now keyed to `PAD_PROUD` instead of a typed 19.0, and an assert intersects the
> finished solid with the pad's own plane over the channel's footprint and requires it empty —
> so it measures the **aperture**, not the constants. Two more slivers went with it: the wire
> groove's 25.6 mm knife edge against the R10 rear corner (`WIRE_X` 57.0 → derived 52.50) and
> the 0.85 mm fin the old saddle left on the bearing rim (now 5.35 mm).
>
> *Found and fixed by `morpheus-thin`. `ember-front-bezel.stl` had already been printed and is
> unaffected — that part is byte-identical across the fix, deliberately.*

Board: **LCDWIKI/QDtech ES3C28P** (Hosyond 2.8" ESP32-S3).
Source of truth: `ember_case.py` (build123d). The STLs are output, not the artifact.

Rebuild with:
```bash
cd enclosure && ./cadenv/bin/python ember_case.py
```
(That path was wrong here for a while — it still named the pre-extraction scratch directory
and a `../cadenv` that does not exist. See [`README.md`](README.md) for first-time setup.)

---

## Parts

| File | Qty | Print orientation | Supports | Notes |
|---|---|---|---|---|
| `ember-front-bezel.stl` | 1 | **front face DOWN** on the bed — ✅ **the STL is now exported already in this orientation, so load and print; no flip needed** (issue #25: it used to export face-UP, standing the part on four ⌀5.40 boss tips totalling 71.9 mm² with the whole 1847.9 mm² face in the air) | **none** | ⛔ **REPRINT — this part changed after JP printed one, again in depth only. The front-face deboss went 0.80 → 0.96 mm (#48): JP's verdict on the printed 0.80 bezel was "it's good but go even deeper next time pls".** (0.48 → 0.80 was #34, same story one rev earlier.) Sizes did **not** change — `BEZ_AFLAT` is still 2.60 — so a bezel already in hand is dimensionally fine and only reads shallower than JP wants. **0.96 is terminal**: it leaves 2.04 mm over the glass against the ≥2.00 assert, so there is no seventh layer — deeper means revisiting the glass floor itself. The visible face is the bed face — use a smooth PEI sheet. Mic flare + window are bed-side chamfers, so they self-support. **The debossed honeycomb is a bed-side recess** (r6, 2026-08-26: the wyrm mark left the bezel — the four-edge tap ramp evicted it, JP's thumb-access verdict; the creature remains on the stand grille and the screen. The brow now carries honeycomb like the chin), 0.96 mm deep — exactly **six** layers at this part's 0.16 mm — and print as bridged voids, which is *why* they are recesses: on a bed face, relief only goes inward. Deeper again means each recess bridges over a 0.96 mm step instead of 0.80, so run the fan hard for the first few layers as you would on the shell's cap recesses. **2.04 mm of bezel is left over the glass** — measured on the exported mesh, not inferred: a 0.4 mm ray-cast grid found 3880 of 3880 debossed points sitting on a full-thickness 2.040 mm slab (re-measured at 0.96, 2026-08-25), so no region is thinned from the back. |
| `ember-back-shell.stl` | 1 | **back face DOWN**, open side up | **none** *(measured)* | ⛔ **Set gap-closing radius / hole horizontal expansion to 0 before slicing — see below, a default will weld the buttons shut.** Hexagonal button pads + living hinges print in the first ~8 layers; the pips point up into the cavity. Counterbores are flat-floored ⌀5.80 pockets opening onto the bed. (This line said "countersinks widen downward" — a leftover from the deleted conical version; the head is cylindrical.) ⚠️ **REPRINT if you have not started this part yet — it gained five connector labels (#27) and a speaker-plug relief (#33).** The relief is a **through-opening in the back slab** over the speaker connector, x 44.54–50.35, y 31.79–40.94 — it prints as a bed-side aperture, so it costs nothing and needs no support. It stops at the *cavity* wall, not the outer edge, so the shell's outline is unbroken. **Labels** (`SD`, `MIC`, `VOL`, power symbol, and now `UART` `I2C` `SPK` `BAT` `IO`) are debossed **0.40 mm = 2 layers at the shell's own 0.20** (was 0.48 = 3 layers at the *bezel's* 0.16 — issue #26), and the two cap labels sit at the bottom of bridged recesses, so they are the first thing sag will blur. **The nine labels are exactly what the gap-closing warning above protects** — every one is a 0.90 mm groove, which is precisely the width a default gap-closer welds shut, and a welded label reads as a smudge rather than as a missing feature. **The debossed cap faces are bed-side recesses and they bridge 13.27 mm (BOOT) / 8.27 (RESET)** — expect visible sag in the middle of both, and run the fan at 100 % for the first ~5 layers. |
| `ember-stand.stl` | 1 | **bottom face DOWN** | **none** | ⛔ **REPRINT AGAIN. A stand printed from an earlier revision will not accept a battery backpack.** The mobile cover fouled the stand's rear top edge by **121.784 mm³** — and it was *pre-existing*, because the check for it had never actually executed; a check that has never fired is indistinguishable from one that passes. The cover could not be the fix (the interference is **mid-height on its chin end face and full width**, and its 2.20 mm wall with the contact leaf's kerf behind can yield 0.60 and no more), so **the stand takes a `DOCK_RELIEF` of 13.00 × 4.40 mm on its rear top edge**, sized by bisection against the real docked stack: 6.00 × 2.00 → 96.6, 9.00 × 3.00 → 28.8, 10.00 × 3.50 → 7.8, **13.00 × 4.40 → 0.000 mm³**. The check is a hard zero now. That is 250 mm³ off a part of over 100 cm³ — **the stand's slot was cut for a slab that existed before the backpack did.** ✅ **A desk-only build is unaffected in function**; the relief is on a hidden rear edge and removes nothing the slab uses. ⚠️ **REPRINT — this part is 16 mm taller than the one you have, and its grille is finer** (issues #29/#30/#31 + #28, see *The plinth* below). **Bridges, quoted by the span the printer actually crosses — the *narrow* dimension, since a bridge is laid the short way:** chamber ceiling **15.3 mm**, speaker-wire channel **24.7 mm** (both unchanged, both printed fine for JP), cable egress **6.0 mm**. ✅ **The baffle recess's top edge is a LEDGE, not a bridge, and needs nothing** — this row said "37.1 mm bridge, expect visible sag" and that was wrong. The 37.1 mm is its length **along an edge that is anchored for its whole run**: the recess is only **1.80 mm deep** and the 2.20 mm baffle sits directly behind it, so the lip is a **1.80 mm cantilever**, not a span. Measured — one layer above the edge there is 12.24 mm³ of lip and 14.96 mm³ of baffle behind it; one layer below there is **0.00 under the lip and 14.96 still under the baffle**. Expect minor droop on the top layer or two of the recess lip. ⚠️ **If you do see lip droop, do not attribute it to #28** — the grille rescale never touched this edge and could not have. **The egress figure is 6.0 and not 14** because the channel's R4 corners taper the void closed over the last 4 mm, leaving only 6 mm genuinely flat at the top — and it is a **true bridge** rather than an anchored ledge, because the channel is open through the plinth's full depth beneath it, so there is no material behind the span. Leave bridging on (slicer default). The plinth is **solid in the model on purpose**: a hollow one would have made the cradle floor bridge ~56 mm, whereas a solid one is just infill and the transition needs no bridge at all. Set infill by the *slicer*, not by hollowing the CAD. ✅ **The gap-closing / hole-horizontal-expansion warning on the shell row does NOT extend to this part's new features** — the egress is 14 mm wide and the corridor 18, three orders off anything that setting welds shut. Two features depend on it, not three; the grille's 0.90 mm webs are the ones to worry about. The **finger scoop** in the rear slot wall opens *upward*, so every wall is near-vertical: no bridge. (It is **one** opening, x 13.94–50.51, not two — `SCALLOP_MIN_RIB` merges them.) The **rear rim is now notched** across x 13.20–50.23 down to z 43.62 so you can reach the caps; the two full-height zones either side of it are what still holds the slab. The **wire saddle** merges into the notch's right-hand end — deliberate, same rule. |
| `ember-stand-base.stl` | 1 | flat | none | Closes the speaker chamber. Press fit. ⚠️ **Resized in `89001ea` — reprint if you made one earlier.** |
| `ember-mobile-midframe.stl` | 1 *(mobile only)* | **back face DOWN**, open side up — same face as the shell it is derived from | **none** | ⛔ **Inherits the shell's gap-closing warning in full** — it *is* `back_shell("mobile")`, so the same living-hinge buttons and 0.90 mm label grooves are in it, and the same default welds them. Two differences from the desk shell, both subtractive: the `BAT` **flank opening is blocked** and its label is **deleted with it** (a label beside solid plastic sends someone hunting for a port), and **two hex rows are dropped** near the chin screw — see the collar note below, it is a real defect and not tidying. Carries the speaker's **bond plateau** (fill the hex field flush, do not hollow it), the driver's 0.60 mm locating groove, two ⌀9.00 screw bosses, and the **+Y end-face cooling field**. Also carries the **LED wire pass** (one 4.75 hex at (32.0, 80.5), 100 % open) and the **internal labyrinth vent** in what is left of the divider. ⚠️ **The `MIC` bore and its label are both deleted on this variant** — buried under the backpack, the bore does nothing, and a back face reading `MIC` over no bore is the same lie told in ink. **19.69 cm³**, 33 352 tris, watertight (0 boundary, 0 non-manifold). Also carries **3 debossed flank labels** and the **driver witness outline** (151.3 mm², 0.40 deep) — ⚠️ if the flank labels look mirrored in your viewer, the viewer is showing you the −X flank *through* the part. |
| `ember-mobile-back.stl` | 1 *(mobile only)* | **OUTER face DOWN** — note this is the *opposite* convention to every other part on this sheet, and it is what makes the part support-free | **none** *(by construction)* | The cell trough opens **upward** as a concave cradle, the grille cells are **vertical prisms** rather than horizontal bores, the counterbore is a recess, and the screw bosses stand proud of what is the part's **top** while printing. ⛔ **The vent labyrinth's connecting band is 0.60 mm — the same width the gap-closer welds shut.** Weld it and the cell bay's failure vent becomes a dead end, which is the one feature on this part whose whole purpose is to not be closed. ⚠️ **The divider is now two stubs** (y 20.20–30.00 and 74.80–88.48); its middle is deliberately gone so the protection strip can lie flat beside the cell. **The chin pocket, its locating ribs, its hold-down detents and the crossing lane are all deleted** — do not look for them. ⚠️ **The divider is whole again, plus JP's double separator wall** — a partial wall and a stepped full wall, **0.90 thinning to 0.50**. Both are **below the 1.60 minimum-solid floor and both are EXPERIMENTAL**: the 0.50 band is the thinnest solid in this family and its thickness is set by the strip, not chosen. **Cost of failure is a floppy wall you can trim with scissors — nothing structural depends on it, and the print is the verdict.** **24.82 cm³**, 8 020 tris, watertight. Bed contact **3078.4 mm²**. |
| `ember-front-bezel.stl` | 1 | as above | none | ✅ **Reused bit-identical by the mobile build** — same STL, same four M3×12. If you have a good one, it serves either variant. |
| `ember-plug-cradle.stl` | 1 *(desk, optional)* | **bottom face DOWN**, exactly as exported — it prints standing in its in-well orientation | **none** | ⛔ **DO NOT PRINT THIS REVISION — four of its dimensions are ASSUMED, not measured (#49).** The captive-USB-C insert that press-fits into the stand's well so docking mates the plug one-handed. Before any print, put calipers on the actual cable's plug head and set `PLUG_W` / `PLUG_T` / `PLUG_L` / `TIP_TO_FACE` (plus `BOOT_D`/`BOOT_L`) in `ember_plug_cradle.py`, then re-run it — every height in the part derives from them, and 1 mm of `TIP_TO_FACE` error is 1 mm of mating error. **~15 min of print, so iterate here, never the 5.4 h stand.** Seat ledges bridge 7.0 mm over the boot channel (fan up, no support). The outer press ribs are the fit: if it slips in loose or needs a mallet, the knobs are `RIB_PROUD_*`, per-side crush is (proud − 0.15). Grip on the plug is deliberately **light** (posture (a) of the issue's extraction-force trade): insertion is one-handed, removal is steady-the-stand two-handed. Load the plug sideways through the open rear face, cable first down the well and out the egress arch. |

**All exposed exterior edges now carry a 0.80 mm 45° chamfer** (#35) — the shell's back face,
the stand's base and rim, and the base plate's one exposed edge. ⚠️ **The bed-side ones are
functional, not just cosmetic:** a chamfer there absorbs elephant's foot, which matters most on
the **stand's base**, because that is the bearing face and a bulged foot is what makes a stand
rock. It also matters more than usual right now — the Z-offset is running deliberately squished
at −2.14. **The bezel is not chamfered yet** (its own issues are in flight); when it is, it uses
the same constant. The parting line is deliberately left plain — chamfering one half of a butt
joint gives an asymmetric reveal.

Outer sizes: slab (bezel + shell assembled) **55.9 × 91.9 × 17.4 mm**; stand
**64 × 64 × 56 mm** (was 40 — the plinth, see below); **mobile backpack (bezel + board +
midframe + cover) 55.90 × 91.90 × 39.00 mm** — the same width AND the same length as the desk slab,
to the hundredth: there is no lip. Depth is the only difference. The story is in
[`docs/enclosure-mobile.md`](../docs/enclosure-mobile.md) §1.
Material use ≈ **166 cm³** total (~206 g in PLA), measured from the current STLs by
signed-tetrahedron volume — not an estimate. Per part: stand **137.6**, back shell 17.9, bezel
7.5, base **2.8** cm³. The stand is **83 %** of the print, because it is a speaker cabinet
standing on a 16 mm plinth, and both of those want mass. ⚠️ It was 93.1 cm³ before the plinth —
budget roughly half again as much filament and time for that part, and only that part.

> **Mesh state: all four STLs are watertight** — zero boundary edges, zero non-manifold
> edges, verified by triangle arithmetic on the exported meshes (every undirected edge
> shared by exactly two triangles, every directed edge appearing exactly once).
> *(Retired 2026-08-26: this note used to disclose 3 non-manifold edges in
> `ember-front-bezel.stl`, coplanar-seam artefacts of the wyrm mark's 104 stacked
> row-spans. r6 removed the mark — the four-edge tap ramp evicted it — and a re-measure
> of the r6 export counts exactly 0. If your slicer reports non-manifold edges on a
> CURRENT bezel STL, that is now a real finding, not the known artefact.)*

---

## Slicer settings

| | Bezel | Shell | Stand | Base |
|---|---|---|---|---|
| Layer height | **0.16 mm** | 0.20 mm | 0.20 mm | 0.20 mm |
| Perimeters | 3 | 3 | **4** | 3 |
| Infill | 15 % gyroid | 15 % gyroid | **25–30 %** | 20 % |
| Supports | no | no | no | no |
| Bridging | — | — | **on** | — |

The bezel gets the fine layer height because its front face is the one you look at, and
because the mic bore is only ⌀2.40 mm — at 0.2 mm layers it starts to close up.

⚠️ **These two numbers are now CONSUMED BY THE MODEL, not just advice to the slicer.**
`ember_case.py` carries `LAYER_H_BEZEL = 0.16` and `LAYER_H_SHELL = 0.20`, and every recess floor,
the counterbore and the living-hinge thickness are whole multiples of *their own part's* value —
asserted, with a control. **So changing a number in this table changes the geometry**, and the
build will refuse rather than silently put a floor mid-layer.

⚠️ **AND SET THE FIRST-LAYER HEIGHT TO THE SAME VALUE — the alignment math assumes a UNIFORM
stack.** Every "exactly N layers" claim above is `N x LAYER_H` measured from z = 0; a different
first layer shifts every boundary up the part by the difference, and then no floor lands on one.
Measured, not hypothetical: the first r2 bezel (PrusaSlicer 2.9.6, 2026-07-31) went out with the
profile's default **0.20 first layer + 0.16 rest**, which put the 0.80 deboss floor mid-layer.
PrusaSlicer slices at layer mid-planes, so it rounded the recess UP to five voids ending at
z = 0.84 — deboss printed 0.84 instead of 0.80, glass floor 2.16 instead of 2.20. Harmless
**that time**, because both errors pointed the direction JP wanted — a floor that rounded the
other way would have SHALLOWED a feature that was resized precisely to stop reading faint, and
nothing in the slicer would have said so. For the bezel: first layer **0.16**, not the default.

⚠️ **At the r4 depth (0.96, #48) this stops being cosmetic.** The deboss now clears the ≥2.00 mm
glass-floor assert by only **0.04 mm** — and a 0.20 first layer shifts every boundary up by
exactly that 0.04. The same rounding that printed 0.80 as 0.84 would print 0.96 as **1.00**,
leaving **2.00 mm dead on the limit** with zero designed margin. The first-layer setting is now
load-bearing for the glass floor, not just for layer-boundary tidiness.

> Until issue #26 there was a single `LAYER_H = 0.16` labelled "the shell parts". It was the
> **bezel's** value wearing the shell's name, and it was load-bearing in both directions at once —
> correct where the bezel consumed it, wrong where the shell did. Three further depths
> (`DEBOSS_BIG`, `DEBOSS_SMALL`, `HINGE_T`) turned out to be mid-layer at **every** layer height
> this project uses, which is why nothing had ever caught them.
>
> **If the shell is ever moved to 0.16** — its only real cost is ~25 % more print time, and the
> counterbore stops being exactly flush — change `LAYER_H_SHELL` and rebuild. Everything
> re-derives. Do not change one depth by hand.

The stand wants **more walls and more infill than feels necessary**: it is a speaker
enclosure, and cabinet stiffness/mass is what stops a 2 W driver sounding like a rattle.
Heavier is better here.

**Filament:** matte **charcoal/coal PLA** for bezel + shell — best surface finish and the
tightest dimensional accuracy, which matters because the board pocket is a 0.35 mm fit.
Use **PETG** instead only if it will sit in direct sun (PLA creeps at ~50 °C).
**Print the whole case in WHITE if you want it to glow.** JP's choice, and it changes the
lighting design: white PLA is translucent, so the WS2812 lights the shell itself rather than
only escaping through holes. That is why there is no diffuser part — see the LED note under
*Speaker* / the hex back below.

### ⛔ Before you slice the back shell: one default will destroy the buttons

**Set "slice gap closing radius" (Cura) or "hole horizontal expansion" to `0`.**

**Two features depend on this setting, not one.** The button moat is the one that strands the
part; the **label grooves are the one you would not notice until the print is off the bed**,
because a welded label still looks like a label in the slicer preview. Every glyph on the back
face — `SD`, `MIC`, `VOL` and the power symbol — is cut at a **0.90 mm groove width**, the same
order as the moat and equally inside what a gap-closer exists to remove. Same fix, one setting,
both saved.

The moat around each button island is `SLOT_W = 0.60` mm — **1.50 nozzle widths** at 0.40 mm.
The geometry is clean: **0.60 mm of void on both sides of both islands, verified at all 12 wall
layers.** But a non-zero gap-closing radius exists specifically to **close narrow slots on
purpose**, and it is on by default in some profiles. That turns a correct STL into a shell whose
buttons look perfect and do not move — **the model is not the failure, the slicer is**, and no
amount of re-checking the STL would find it.

Even with it at zero, **expect some fusing.** At a realistic 0.45 mm bead the two perimeters
meet almost exactly, and the hinge shoulders are where it shows first.

- **Free the pads with a fresh blade at assembly step 3**, before anything else goes together.
- ⚠️ **Cut from the outside inward and stop at the hinge.** The hinge is the one feature designed
  to flex — a 0.80 mm membrane at a calculated 1.07 % strain against PLA's ~2 % yield. **A knife
  nick there is a stress riser the calculation does not include.**

### The cap-face bridges are 13.27 and 8.27 mm, and they grew 82 % without being noticed

The BOOT cap's deboss floor spans `R·√3` = **13.268 mm**; RESET's is **8.268**. Both bridge
routinely over a 0.80 / 0.40 mm recess — **this is a cosmetic note, not a defect.** Expect sag in
the middle of the faces you look at and press. Fan at 100 % for the first few layers.

> **Worth knowing how the number got there.** At the old caps that span was **7.275 mm**
> — both figures computed from `BTN_R_*` and `CAP_INSET` rather than measured, so the ratio
> is exact and end-to-end on one basis. *(Voxel-measuring both ends instead gives 7.20 → 13.20
> and +83 %; pairing one measured end with one computed end gives +84 %, which is wrong while
> looking like the most careful option. **State the basis, not just the value.**)*
> Growing the caps to thumb-size took it to 13.268 — **+82 %** — inside a change that was
> reviewed for hinge strain, lever ratio, countersink clearance and the hex-field boundary.
> **Printability of the recess floor was not on that list.** A checklist that is complete for
> the questions it knew about is a harder failure than an omission, because nothing about it
> looks incomplete.

### "Supports: none" for this part is measured, and now it is stronger than that

| band | area |
|---|---|
| overhangs 10–30° | **0 mm²** |
| overhangs 10–30° | **0.00 mm²** |
| overhangs 30–45° | **0.00 mm²** — the countersink cones were this band's only occupant and the counterbore replaced them |
| near-horizontal (bridged) | **499.12 mm²**, all of it |
| first-layer contact | 3727.9 mm², **one island**; 92.0 × 14.60 mm is 6.3:1, so **no brim** |
| thinnest feature | 0.750 mm — the hex web |
| side-channel roofs | 2.62 / 1.57 / 1.05 mm bridges — trivial |

**Nothing on this part sits in the awkward 10–45° range at all.** Every unsupported facet is
*near-horizontal* — i.e. bridged — which is a stronger statement than "no supports needed": there
is no shallow overhang anywhere to print badly. Where the 499.12 mm² is:

| printed z | area | what |
|---|---|---|
| 0.40–0.80 | ⚠️ **re-measure** | **the two cap-deboss floors — the only genuine bridges**, 13.27 and 8.27 mm. The band moved: the deboss depths were 0.90/0.50 and are now **0.80/0.40** (issue #26 — neither old value was a whole number of layers at any layer height this project uses). The 211.66 mm² figure was measured on the old depths and is **not** re-derived here |
| 3.00–3.50 | 71.44 mm² | the four counterbore floors — **annular ledges, not bridges** (see below) |
| 8.00–8.50 | 171.63 mm² | side channels + the USB-C relief roofs |
| 9.00–9.50 | 14.00 mm² | |
| 10.00–10.50 | 30.40 mm² | |

**So the fan note belongs to the cap faces and nowhere else.** Run it at 100 % for the first
~5 layers; nothing later on the part needs it.

---

> ⚠️ **Settled, and it moved: the large cap belongs at the LOW-x end.** `86748c6` derives the
> switch identification from the microSD socket instead of carrying it as a literal, and the
> answer inverted — **BOOT (the readable switch) is at x 13.45**, RESET at 36.58. The large
> 15.00 mm cap and its 13.27 mm bridge went with BOOT to the other end of the board; the island
> centres are now **16.66** (large) and **35.66** (small). Every *figure* on this page was a
> property of the cap and is unchanged — only which end it sits at moved. **If you printed a back
> shell before `86748c6`, its caps are on the wrong switches.**

## Fasteners

**4 × M3 × 0.5 × 12 mm ISO 4762 socket cap** (hex recess, cylindrical head), driven **from the
back** into a **flat-bottomed counterbore**, so no heads appear on the front face.

> ⛔ **This changed, and the previous guidance would send you to the wrong shelf.** This sheet
> used to specify a **countersunk (flat) head** for a conical countersink. The part now has a
> **⌀5.80 × 3.00 mm flat counterbore** for a **cylindrical** head. **A conical head in a flat
> counterbore does not seat on anything** — it contacts the bore edge on a circle, or bottoms on
> its point. That is worse than either geometry the old text analysed, so all of it is deleted
> rather than adjusted, including its length table: see the length note below.

| | |
|---|---|
| Screw | `M3 × 0.5 × 12` **ISO 4762** socket cap, hex recess |
| Head | ⌀**5.50** measured, not tabulated |
| Counterbore | ⌀**5.80** (0.30 diametral clearance, 0.15 a side) × **3.00 mm** deep — **15 layers exactly** at the shell's 0.20, and **exactly the measured 3.00 mm head height**, so the head is dead flush with no rounding |
| Through-hole | ⌀3.30 |
| Pilot in the bezel boss | ⌀**2.50**, blind |

Load path: head bears on the **flat counterbore floor** in the back shell → 5.5 mm standoff →
through the PCB's ⌀3.20 hole → **self-taps into the blind ⌀2.50 pilot in the bezel boss**.

⚠️ **The length convention changed with the head, and this is the trap.** A **countersunk**
screw's stated length **includes** its head; an **ISO 4762 socket cap's does not** — 12 mm is
**under-head**. So the old ×14/×15/×16 table is not mislabelled, it is on the wrong basis
entirely, and none of its numbers transfer. Re-derived for the new screw:

| screw (under-head) | tip reaches | engagement | |
|---|---|---|---|
| M3 × 10 | z +3.34 | 3.34 mm = 1.11 D | short |
| **M3 × 12** | z +5.34 | **5.34 mm = 1.78 D** | **the spec**, 0.86 mm clear of the pilot end |
| M3 × 14 | z +7.34 | — | ⛔ **bottoms out** (pilot ends at 6.20) |

**×14 and ×16 still bottom out, and the failure still looks like success** — the tip hits the
bottom of a blind pilot before the head reaches its floor, so it feels tight while clamping
nothing. That hazard survived the redesign unchanged; only the numbers moved.

- **The counterbore is deeper than the back wall, and that is by design.** 3.00 mm of bore in a
  2.60 mm wall passes into the cavity — where the boss **flares to ⌀8.40** at the cavity floor,
  tapering to ⌀5.40 at the PCB face. The flare is what the bore lands in. ⌀8.40 comfortably
  surrounds ⌀5.80, so there is material all the way round.
- **The counterbore floor is an annular ledge, not a bridge — it prints essentially free.** It
  is tempting to call it a 3.30 mm span over the through-hole; measured, it is an **annulus
  supported on its full outer circumference, cantilevering 1.25 mm inward** — `(5.80 − 3.30)/2`.
  Four of them come to **71.44 mm²** against **71.47 predicted** for four OD 5.80 / ID 3.30
  rings, which is agreement to 0.03 mm². A ring like that needs no fan and no attention.
  > **The exact-layer-count depth is still right, for a smaller reason than a bridge.** 15 × 0.20
  > puts the floor on a **clean layer boundary**, so the head seats on solid material instead of
  > on a partial layer. That is worth having; "it bridges 3.30 mm" was not the reason.
  >
  > ⚠️ **This used to read 19 × 0.16 = 3.04, and that was issue #26.** 0.16 is the *bezel's* layer
  > height, borrowed by a shell feature. At the shell's own 0.20 the old 3.04 was 15.2 layers — a
  > mid-layer floor under a load-bearing head. The 0.04 mm of deliberate sink is also gone: 3.00
  > divides 0.20 exactly, so correcting #26 deleted a compromise rather than adding one.
- A head bearing on a **flat** floor gets a genuine full-face seat, so **no re-nip is needed** —
  that advice belonged to the conical staircase and went with it.
- **Heat-set inserts will NOT fit.** The vendor specifies a ⌀5.60 pad around each mounting
  hole, so bosses are capped at ⌀5.40 **at the PCB face**. An M3 insert needs a ⌀4.0–4.2 bore,
  leaving a 0.6 mm wall that will split. Self-tappers only.
- **Snug, not hard.** You are clamping a 12 g PCB. A cylindrical head on a flat floor spreads
  load over its whole face rather than a rim or a step, so this is now ordinary care in PLA
  rather than a design consideration.

Stand base: press fit. Seal the seam with a bead of silicone or a strip of tape — it needs
to be **airtight, not structural**.

---

## The slab in the stand

The slab drops into a tilted slot, **15° back from vertical** for a seated viewer.

⚠️ **Revised — it used to bury the screen.** The slot floor was at `z = 10.0`, which put
the stand **30 mm** up the slab — **31.1 mm along it** once tilt is accounted for
(30 / cos 15°). The visible area starts only 19.76 mm up from the slab's bottom edge, so
the stand covered **11.3 mm of screen: 19.5% of a 58.05 mm display**, hidden behind the
box. Caught by looking at a render; a boolean clearance check can never find this, because
nothing intersects — the stand was simply *in front of* the screen.

The same depth left just 6.0 mm between the slab's bottom edge and the stand floor, and a
straight USB-C plug body needs **~18–20 mm**. There was nowhere for the power lead to go.

**Slot floor is now `z = 24.0`:**

| | |
|---|---|
| Engagement | **16.6 mm** along the slab — a captive slot constraining both faces |
| Visible area | **entirely clear** of the stand |
| Room below for USB-C | **20.0 mm** |

There is a **USB-C well** under the slot — 22 mm wide × 12 mm deep, **tilted to follow the
slab's own axis** and running down it to the cradle's inner floor.

⚠️ **It was a flat box first, and that did not work.** The slot is a box rotated by the tilt
with `align=MIN`, so **its bottom face tilts too** — the front-bottom corner sits at
z ≈ 26.4 while the rear-bottom drops to ≈ 21.6. A well cut flat to z = 24 therefore left a
wedge of material exactly where the plug emerges. It measured as "20 mm clear" only because
the check point-sampled the **centreline**, which is the single locus where that discrepancy
vanishes. A plug has width, and its front corner hit the wedge.

Re-measured by sweeping a plug-shaped box down the insertion axis:

| plug | clears |
|---|---|
| slim / low-profile 12 × 6 mm | past 20.7 mm |
| typical moulded 14 × 7 mm | past 20.7 mm |
| chunky braided 16 × 9 mm | past 20.7 mm |
| very bulky 20 × 11 mm | past 20.7 mm |

20.7 mm is the stand floor; past that the well opens into the cable route. A straight plug's
overmould is 18–25 mm, so all of them fit.

**Depth is 12 mm, not 22, and that is solved rather than chosen:** the well drifts forward
`sin(15°)` per mm of descent, and at 22 mm wide its front face reached y = 20.6 — inside the
sealed speaker chamber, whose rear wall is at y = 22.0. `_check_geometry` asserts this, and
it is what caught it.

`ember_case.py` asserts all three of these on every run (`_check_geometry`), so the screen
cannot get buried again by a later tweak.

## The plinth — why the stand is 56 mm and not 40

⚠️ **This is a reprint of `ember-stand.stl`, and it is the reason for it.** Issues #29/#30.

JP measured the cable: **40 mm from the plug tip to the first point it can bend.** That is a
length of *straight corridor*, and its direction is not a free variable — the port fixes it,
15° off vertical, pointing **down and forward** along the slab's own axis.

On the 40 mm stand the port sat 25.92 mm above the desk, which offers 26.83 mm of straight
run. **A straight 40 mm tail therefore ended 13.2 mm below the desk**, which is why the
device would not seat and why the plug levered it out of the slot. Note what that rules out:
**recessing the slot floor cannot fix it at any depth** — the deficit is larger than the whole
floor thickness. The port has to sit higher.

| | |
|---|---|
| Stand height | **56.0 mm** (cradle 40.0 + **plinth 16.0**) |
| Straight corridor, port → desk | **43.40 mm** for a 40 mm requirement |
| End of the rigid run | y = 26.47, **3.28 mm above the desk**, still heading forward |
| Required there | **2.25 mm** = `CABLE_OD/2` — see below — so **1.03 mm of margin** |
| Cable meets the desk | y = 25.59, i.e. 25.6 mm behind the front face |

**⚠️ What must clear the desk is the cable's CENTRELINE, not its tip.** A tail whose lowest
surface just grazes the desk is a tail whose axis is half a diameter *below* it — meaning the
last few millimetres of the **rigid** run are already being deflected, which is the exact load
path that levers the device out of the slot. That `CABLE_OD/2` term is the difference between a
clearance and a coincidence, and it is what puts the derived floor at **54.97 mm** rather than
52.72.

> **Both figures that circulated during this work reconcile exactly on that term**, which is how
> it was found. The port's offset from the slab mid-plane was disputed in sign — 1.152 mm of
> height rides on it — and the two candidate heights turned out to be the two signs, each plus
> 2.25: **54.97** (port on the back-shell side, which is the settled and correct one) and
> **53.82** (the other). Neither was a rival model. The settled sign is the one needing the
> *taller* stand, because the back of a backward-leaning slab is its **low** side.

**Nothing in the cradle moved.** The slot, the well, the sealed chamber, the grille, the
driver seat and the wire route are the same geometry at the same numbers — the plinth is
modelled *below* the cradle's own z origin and lifted at export. ⚠️ **That means every height
in `ember_case.py` is 16 mm lower than the same height measured off the STL.** The rim notch
is `z = 27.62` in the source and `z = 43.62` in the file you slice. Both numbers are correct;
neither is correct in the other frame.

### The cable comes out the FRONT, and that is not a choice

The obvious routing is out the back. It is geometrically impossible at this height, and the
arithmetic is short enough to put here so nobody "fixes" it:

The tail is still travelling forward, 75° below horizontal, when it reaches the desk. Turning
that rearward is a 105° turn, and a circular arc of radius R descends **1.2588 × R** doing it.
The budget above the desk is **3.28 mm → R ≤ 2.6 mm**, against the ~18 mm a 4.5 mm USB-C cable
wants. Width does not substitute: a U-turn in the horizontal plane at R18 needs 40 mm of x.

> **A stand where the cable completes its bend *inside* the base is a different part** — it
> needs 22.7 mm below the end of the rigid run, i.e. ~75 mm tall. 56 mm accommodates the rigid
> run and lets the cable bend in **open air**, and that only works if the exit is where the
> cable is already pointing.

So the plinth carries a **14 mm wide × 10 mm tall channel** at desk level, opening through the
front face (R4 corners, so the visible mouth reads as an arch rather than a bite). Lead the
cable out of the front and away to either side. It is under the grille and mostly hidden by
the overhanging slab.

### What it costs, and what it does not

| | |
|---|---|
| Bearing footprint | **2922 mm²** of a 4010 mm² plan |
| Quadrants (front L/R, rear L/R) | **47 % / 47 % / 99 % / 99 %** of their plan |
| Contact behind the loaded CoM (y = 45.89) | **1116 mm²**, reaching to y = 64.0 |

The two front quadrants carry the speaker chamber's **access shaft** — 54 × 15.3 mm, which now
runs the full height of the plinth because the driver still goes in from below and the base
plate still closes the chamber at the top of it. That shaft plus the egress channel are the
*only* two openings in the underside, and `_check_geometry` holds a ledger of exactly those.

⚠️ **The old bearing check would have passed on a stand with no underside at all.** It probed
z 0–0.4, which under a plinth is a plane in the *middle* of the part. It now probes the real
bearing plane and tests the **distribution** as well as the area, with a 4 mm perimeter ring as
a control that must fail — because area alone cannot tell a ring from a face, and that
distinction is the whole point of the check.

## Speaker

It is a **sealed-back module**, not a bare driver: a plastic box carrying its own rear
cavity, diaphragm on one face, JST-1.25 2-pin pigtail, **double-sided tape on the back**.
**40 × 27 mm footprint, 10 mm thick** (measured).

> **That inverts the mount, and it took three revisions to get right.** The first cut
> assumed a round ⌀28 flanged driver in a recess. The second made it a 40 × 27 rectangle
> and kept a shallow lip on the baffle. Both were wrong, because a baffle-mounted driver
> needs adhesive on the face that *meets the baffle* — and this one has it on the
> opposite side. The bonding surface cannot be the front wall at all.

**How it mounts.** A flat **tape pad** stands 0.80 mm proud of the chamber's rear wall,
40 × 27 with matching corner radius. Stick the module's taped back to it; the diaphragm
then faces forward at the grille. The pad is *raised* deliberately, so the adhesive meets
one continuous plane — no fillet, no print artefact at the wall/floor junction to
interrupt the bond. **The baffle's inner face is left completely alone**: the module never
touches it, and anything cut there would only put a cavity edge in front of the diaphragm.

**Chamber depth is now derived, not chosen.** Baffle + 2.50 mm front gap + 10 mm module +
0.80 mm pad + margin → rear wall at **19.3 mm**. Previously it was pushed to 22.0 "as deep
as the slab slot allows", maximising sealed volume — the right goal for a baffle-mounted
driver and the wrong one here. With the module taped to the rear wall, extra depth is not
extra enclosure, it is **extra air in front of the diaphragm**, which is a cavity
resonance. There is an assert in the source so this can never silently foul the slot.

⚠️ **Two corrections to earlier advice in this file, now that the module is known:**

- **Skip the wadding.** It was recommended to damp standing waves in the sealed chamber.
  A sealed-back module brings its own rear volume, so there is no rear chamber to damp —
  stuffing the front cavity would just absorb output on its way to the grille.
- **Sealing still matters, for a different reason.** Not to hold bass in a rear chamber,
  but to stop the *front* cavity venting anywhere except through the slots. Any leak lets
  the front wave escape and cancel, which costs level. So still seal the wire
  pass-through and the base seam — the reason changed, the instruction didn't.

The **volume figures earlier in this file are about a rear chamber that no longer exists
in the acoustic sense.** They still describe the printed void; they no longer describe
what the module is loading into.

- The ES3C28P **speaker header is unpopulated** — you need a 1.25 mm 2P pigtail.
- Changing driver: edit `DRIVER_W`, `DRIVER_H`, `DRIVER_R` in `ember_case.py` and re-run.
  `GRILLE_INSET` (1.0 mm) keeps the slots inside the radiating area so the grille never
  opens onto the frame — an open slot over the flange is a dust path into the chamber and
  vents the enclosure.

⚠️ **Keep the driver magnet away from the top 8 mm of the board's back face** —
`ANT = (17.57, 32.21, 80.04, 85.70)` is the PCB Wi-Fi antenna. The stand geometry already
puts the magnet ~70 mm away, so this only matters if you relocate the speaker into the slab.

---

### Making it louder — and the grille is the wyrm's ridge

⚠️ *This subsection was lost once already: rewriting the Speaker section for the sealed-back
module replaced a span that happened to contain it. Restored, and updated.*

The bottleneck was never the box volume, it was the **baffle**. A slot behaves like a short
duct and its impedance scales with length ÷ width, so 2.20 mm slots through a 4.00 mm wall
(**1.82:1**) made the sound squeeze through slits nearly twice as deep as they were wide.

1. **The baffle is recessed to 2.20 mm** in the grille region only, cut from the *outside*
   so the inner face stays flat. Slot aspect 1.82:1 → **1.00:1**, roughly halving the
   impedance.
2. **The grille is a hexagonal honeycomb** — 59 cells placed, **53 open apertures** after the
   field's rounded corners clip them, **4.50 mm across the flats** on a
   5.40 mm pitch (2.598 mm circumradius), 0.90 mm web, in a 38 × 25 field.

   > ⚠️ **Rescaled in `980598d` (issue #28) — these numbers replace the 6.50 AF / 33-cell /
   > 27-aperture figures this section carried before, which described the part JP printed and
   > was unhappy with.** The complaint was *"sagging/messy but holes are open"*: the apertures
   > **formed**, so the defect was **droop, not collapse**, and droop scales with unsupported
   > **span length**. Two levers, both applied — `GRILLE_FLARE` 0.60 → **0.25**, which restores
   > the 0.90 mm webs at the mouth that anchor each span, and `HEX_R` down so across-flats is
   > exactly 4.50. Measured downward-facing span at the aperture band: **35.283 mm in one run →
   > 4.567 mm in eight. 87 % shorter.**
   >
   > **Counter-intuitive and worth keeping:** a finer lattice is *less* open per unit field,
   > because `HEX_WEB = 0.90` is a print floor that does not scale with the cells —
   > `(a/(a+w))²` goes 0.7714 → 0.6944. So shrinking the holes **spends** open area, which is
   > why `GRILLE_INSET` went 1.5 → 1.0 to grow the field and pay for it.

   Re-measured on the current geometry, in the X–Z plane, which *is* the aperture plane
   because the bores run in Y:

   | | area | openings |
   |:--|--:|--:|
   | **Throat** — un-flared cells ∩ field, the acoustic restriction | **640.8 mm²** | **53** |
   | **Mouth** — flared cells ∩ field, the face you touch | **779.2 mm²** | **53** |
   | the field itself (38 × 25, r2.0) | 946.6 mm² | — |

   > **The mouth is 53 separate apertures now, and that is the visible change.** At the old
   > 0.60 flare the mouth webs were consumed entirely and the whole field read as **one
   > 886 mm² opening** with a honeycomb sitting 0.40 mm behind it — finer cells would have
   > changed nothing you could see. At 0.25 the mouth web is **0.4670 mm** and survives, so the
   > honeycomb is a honeycomb from outside. `GRILLE_MOUTH_WEB` asserts ≥ 0.45 **or** fully
   > merged, and nothing in between: a 0.1 mm fin is the one outcome that is neither.
   >
   > ⚠️ **The acoustic solve is now 4.8 % under target, and that is a cost, not a rounding.**
   > The baffle was solved numerically for **673.0 mm²**; the throat measures **640.8**. It was
   > +0.7 % before the rescale. On a sealed-back module with Fs ≈ 650 Hz this is inaudible —
   > the baffle aspect ratio, fixed in item 1, was worth an order of magnitude more — but it is
   > spent, not free, and if the field is ever rescaled again it should be spent knowingly.

   **They are not louvers.** Both patterns are straight-through bores; the raked slots were
   angled *in the plane* of the wall, not through its thickness, so nothing about the angle
   ever steered sound. That is precisely why the pattern was free to change.

   Hex is the better engineering answer at equal open area, for two reasons: it is the
   **optimal packing** for a given web thickness, so it reaches the target with more
   material left between holes than parallel slots do; and it is **isotropic** — a slot
   array is slightly stiffer across the bars than along them, a hex field has no preferred
   direction.

   `GRILLE_STYLE = "ridge"` restores the raked dorsal-ridge array (9 slots, 24° rake,
   3.20 → 2.50 mm taper, also 673 mm²).

3. **0.60 mm flare on the bores — and at that value the mouths deliberately merge into one
   opening.** A sharp-edged bore sheds vortices and chuffs at level; the flare opens outward
   and is self-supporting in the print orientation. It does both of those jobs merged.

   The flare grows each cell's across-flats by `2·flare·cos30°`, so **merging begins at
   `HEX_WEB/√3 = 0.5196`** against the 7.3952 mm pitch. At 0.60 the flared cells interpenetrate
   by 0.1392 mm, and **the outer 0.40 mm of the baffle is therefore a single aperture with the
   hex pattern set back behind it.** From outside you are looking at one recessed opening, not
   at 33 chamfered ones.

   **That is a choice between three options, not a dial**, because *any* flare puts the web at
   the mouth under `HEX_WEB`'s own 0.90 mm floor:

   | flare | web at the mouth | |
   |:--|:--|:--|
   | `0` | 0.900 mm | keeps the floor, loses the relief entirely |
   | `0.2598` | 0.450 mm | printable, but a 0.45 mm feature on a part whose declared floor is 0.90 |
   | **`0.60`** *(shipped)* | *merged* | **no sliver at all** — a deliberate 0.40 mm recessed mouth |

   ⚠️ **`0.45` is the trap and it was nearly taken.** It leaves **0.1206 mm** of web — a fin too
   thin to print and too thick to be a clean merge, i.e. the one option that is neither. Worse,
   it would have made the cell-count assert start *passing* while the printer still merged the
   mouth. If you are tempted to "restore the individual chamfers", that is the value you will
   reach for, and it is the wrong one.

   > **The cell-count assert cannot see any of this.** It is computed on the *un-flared* field,
   > so it counts 33 separate cells no matter what the flare does to the mouth. It is guarding
   > the wrong object — the cells that merge are the flared ones.

**At assembly:**

- **Skip the wadding.** A sealed-back module brings its own rear volume, so there is no rear
  chamber to damp — stuffing the front cavity would just absorb output on its way out.
- **Seal every joint** — the wire pass-through and the base seam. Not to hold bass in a rear
  chamber, but to stop the *front* cavity venting anywhere except through the slots. A leak
  there lets the front wave escape and cancel, which costs level.
  > ⚠️ On the currently committed stand there is no wire to seal *around*, because the lead
  > cannot get through the pass at all — see the block at the top of this page. Sealing a
  > blocked pass would be sealing the chamber shut.
- **Print the stand with more walls and infill than feels necessary** (5–6 perimeters, 30%+).
  It is a speaker cabinet; stiffness is what stops a 2 W driver exciting a 64 mm panel.

**Not done, deliberately:** a bass-reflex port. At this volume a printable port tunes to
~390–460 Hz, useful only if it lands just below the driver's Fs — unknown. A port tuned
below Fs does nothing and a mistuned one is worse than sealed.
`Fb = (c/2π)·√(A / (V·Leff))`, `Leff = L + 0.85·d`.

## Assembly order

1. Plug the speaker pigtail into the board's **SPEAKER** 1.25 mm 2P header (long edge).
2. Seat the driver in the stand, wires out through the cable channel, press on
   `ember-stand-base`, seal the seam.
   > ⚠️ **Lay the speaker lead into the rear saddle _before_ the slab goes in.** There is
   > 0.40 mm between the slab and the wall against a 1.2–2.0 mm lead, so it cannot be threaded
   > afterwards — and a pinched lead presents as **intermittent audio**, which reads as a
   > firmware fault and will be debugged as one.
3. **Free the button pads first, with the shell still on its own.** `SLOT_W = 0.60` is
   **1.50 nozzle widths at 0.4 mm**, so expect some fusing across the printed-in-place slots,
   especially at the hinge shoulders. Run a fresh craft-knife blade round each pad and check
   both hinge properly. **Do this now** — later means working next to a taped driver inside a
   part that is mostly closed.
4. Lay the board **face down into the bezel**. The glass does **not** touch the bezel —
   there is a deliberate 0.40 mm gap. The four bosses land on the PCB's top face.
5. ⛔ **THE ROCK TEST — no screws yet, and this is the one irrecoverable failure on the page.**
   Set the bezel onto the shell dry and press the centre.
   > - **It rocks on the rim** → the glass gap is intact. Proceed.
   > - **It sits dead solid while the seam is still visibly open** → it is bearing on the
   >   **glass**. **Stop.** Shim the four bosses with 0.2 mm washers, or take 0.2 mm off the
   >   boss ends. **Do not "just tighten it".**
   >
   > Worst case the gap is ≈0.15 mm and still positive, but pressure on an LCD leaves a
   > permanent bright blotch, and it is the most expensive component in the build. Five
   > seconds.
6. Drop the back shell on. Check the five 1.25 mm connectors and the microSD sit in the
   side channels before pulling anything tight.
7. Four M3 × 15 (or × 14) countersunk from the back. Snug, not hard — you are clamping a PCB.
   **Tighten in two diagonal passes**, not one screw at a time: the screws pull the bezel
   down, and going round in order tips it and loads one corner of the glass on the way.
8. ~~Press `ember-diffuser` into the ⌀16 seat around the rear glow window.~~
   **REMOVED.** There is no diffuser and no seat. The ⌀12 rear glow window and its ⌀16
   diffuser seat were both deleted when the back shell became a fine hex field: the LED's
   light now leaves through the apertures over it — 8 within r6, 23 within r10, 32 within
   r12 — plus straight through the wall if you print in white. Many small apertures in a
   translucent panel scatter; one large bore behind a printed disc just shows you the die.
9. Slide the slab into the stand slot; **plug the cable in first, from underneath** — feed it up
   the egress channel and the well, then seat the slab onto it. Route the tail **out of the
   FRONT** of the plinth at desk level and away to either side; see *The plinth* for why the
   back is not an option. **The two button caps end up inside the slot**, but the rear rim is
   now **notched down to z 43.62 across the cap span**, so you reach them from behind over an
   open rim rather than down a 12 mm pocket. If a finger does not fit, that is the fault this
   feature exists to fix and something has regressed: `_check_geometry()` drives a 6 × 4 mm
   fingertip probe at each cap and fails if the stand blocks more than 1 mm³ of it.

---

## The mobile (battery) variant

Three printed parts, one of which you may already own: the **bezel is reused bit-identical**, the
**midframe** is `back_shell("mobile")`, and the **cover** is new. The desk stand and its base are
not used — but see the reprint warning at the end of this section, because **the stand changed for
this build even though the mobile does not include it.**

### Fasteners — 2 × M3 × 0.5 × 22 ISO 4762 socket cap

Same head and counterbore family as the bezel screws, driven **down** through the cover into
bosses in the midframe.

| | |
|---|---|
| Screws | **2 × `M3 × 0.5 × 22` ISO 4762** socket cap, hex recess — 2.5 mm key |
| Positions | one lane at **x 23.55**, which is the case's own centreline: chin **y 22.60**, top **y 85.98**, **63.38 mm baseline** between them |
| Boss | ⌀**9.00** at both ends — not 7.00: at 7.00 the annulus is 0.60 against a 1.00 minimum, because `CBORE_DEPTH` 3.00 exceeds the cover's 2.20 wall, so **the head bears on the boss and not on the wall** |
| Pilot | ⌀2.50 blind, **6.60 mm** deep |
| Engagement | **3.40 mm** — it clamps, and it cannot bottom out; both asserted |

⚠️ **The under-head length trap applies here exactly as it does to the bezel screws, and it is
why this is a 22 and not something rounder.** `M3 × 22` is an **under-head** length. The head
bears at z −28.30 and the tip lands at −6.30 in a pilot whose floor is at −3.00, so the numbers
that matter are the 3.40 of thread engaged and the 3.20 of empty pilot beyond it. **Fit a longer
screw and it bottoms on the pilot floor before the head seats** — the joint then feels tight while
clamping nothing, which is the failure mode that reads as success. That is the same reason the
desk build could not simply take a deeper back shell: deepening it moves the counterbore 21.80 mm
further from its pilot and invalidates the derivation while still looking correct.

⚠️ **Two screws is the whole fastener count, and the rest of the edge is carried by the cover's
21.60 mm closed box section.** The worst unheld point on the outline is **43.19 mm, at
(52.95, 54.34)** — mid-span of the +X long edge. If the cover's top edge gaps on your print, that
figure is where to look first, and it is a stiffness result rather than a fastener one.

### Assembly order — and the first two steps are why the geometry looks like this

1. **Lay the strip body flat in its channel beside the cell lane** — x 16.15–20.65, mid-bay
   y 42.83–64.33. It goes in **before the cell**, and the cell **drops on top of it**. Nothing is
   threaded down beside a cylinder that already fills the bore.
2. **Fold both nickel tabs into leaf springs** and seat them. 34.25 mm per side gives 22.62 of run
   and 11.63 of fold — about 3.2 limbs of a Z-fold. ⚠️ **Free height 3.60 is JP-tunable**: it is the
   one number here set by feel, and it sets the preload (1.75 mm on the shortest cell in tolerance,
   0.50 off fully closed on the longest).
3. **Solder the output wires on the body's +X side**, then thread them to the chin pass. That side
   sits past the cell's surface, so **the joints are where their thickness is not a dimension** —
   which is the whole reason the body sits where it does rather than a happy accident.
4. **Tape the driver** to the midframe's back face inside its 0.60 mm locating groove. That face is
   a printed **bed face**, so there is no proud pad and the groove is an outline only: the tape does
   the work.
5. **Route the driver leads through the SPK relief, then ⛔ SEAL THE RELIEF** — silicone, hot glue or
   putty. ⚠️ **That plug is half the seal, and it is the half no model can check.** A flood fill of
   the assembled stack returns *one* interior air volume including the outside; the boundary is this
   wall **plus this manual step**, so skipping it does not degrade the seal, it removes it.
6. **Fit board and bezel** exactly as the desk build. Four M3 × 12.
7. **Drop the bare cell on top of the seated strip.** Both ends land on leaf springs; there is no
   plate to orient against, so read the debossed marks.
8. **Seat the cover and drive both M3 × 22.**

### The polarity marks, and why they do not match each other

`+` is debossed on the **high-Y end wall at y 86.95**. `−` is on the **cover's mating face at
y 19.10**. They are deliberately **not** mirror images, and the asymmetry is the point:

> ⚠️ **The `−` mark was originally cut correctly and could not be seen.** It measured **34 %
> visible** — the folded leaf sits in front of it. Nothing about that geometry was wrong; the mark
> was at the right depth in the right place, and a person loading a cell could not read it. The
> deboss check passed, because it measures **volume** and the thing that mattered was **sightline**.
> The check gained a visibility lens with the old geometry as its rejected control.

⛔ **There is no mechanical reverse-insertion protection, and there cannot be.** A bare flat-top
18650 has geometrically identical ends, so any aperture that stops a reversed cell stops a correct
one. **The marks are the only protection, and they are advisory.** Making reverse insertion *safe*
is electrical and it is not built.

### ✅ The 1.25 mm web is PROVEN now — below the 1.60 minimum, and validated on a real print

> **JP: "we have proven two that collapse and none that survives."**

> **And then one did.** JP inspected the r10 cover's through-field bores — the horizontal-bore class,
> the #47 class, the worst case — and reported: **"Clean — webs crisp."**
>
> ✅ **So the 1.25 web is validated at 4.75 mm spans, and every field on these parts is at or below
> that** (3.20 top fields, 4.00 dock). Web collapse is governed by the **span each web bridges**, and
> a shorter span is strictly easier — so the verdict covers them *a fortiori*. The exemption stands
> as a proven one rather than a trial. **What is still unproven is any future field with spans above
> 4.75.**
>
> ⚠️ **Do not generalise it further than that.** The separator wall's **0.90 and 0.50** are a
> different matter entirely — a supported vertical wall, not a web spanning a bore — and they are
> still experiments awaiting this same treatment. The 0.80 blind deboss is exempt because a surface
> relief **has no rib to lose**, which is not a strength claim at all.

The +Y cooling field and the speaker grille both use **4.75 mm across flats on a 1.25 mm web** —
the stand's own grille constants, shared **deliberately**. This is the opposite call from the glow
window, which was *pinned away* from that same pair after #47, and the difference is what each
feature is for: the window's size is set by the cavity band it lives in, so inheriting another
part's lattice was pure accident there and broke the fit. **The cooling fields have no such
constraint and exist precisely to BE the pattern under test.** If the 1.25 web survives a real
print, that answers #47 for the whole family at once; if it collapses, it collapses everywhere in
one place.

⛔ **So this web is below the 1.60 mm minimum-solid floor, and it is deliberately NOT in the
minimum-solid check's list.** That is not an oversight and **must not be "fixed" by adding it** —
the check would then fail the build on a pattern that is on trial on purpose. The build prints it
as an `[exempt]` line instead, so it is loud rather than silent. **When you print these parts, the
web is the thing to look at.**

The end-vent cells are **flat-top in Z — 60.0° shoulders** measured from horizontal. Vertex-up
would give **30.0°**, which is issue #28's droop exactly, and the build keeps that orientation as a
**rejected control**.

### ⛔ The stand needs reprinting — even though the mobile does not use it

If you dock a backpack in the desk stand, **the stand you have will not accept it.** The cover
fouls the stand's rear top edge by **121.784 mm³**, and it was *pre-existing* — the check for it
had never actually executed, and a check that has never fired is indistinguishable from one that
passes.

The cover cannot be the fix: the interference is **mid-height on its chin end face and full
width**, not a corner a bevel could take off, and its 2.20 mm wall with the leaf's 0.35 kerf behind
can yield **0.60 and no more**. So the stand takes a **13.00 × 4.40 mm relief** on its rear top
edge, sized by **bisection against the real docked stack** — 6.00 × 2.00 → 96.6, 9.00 × 3.00 →
28.8, 10.00 × 3.50 → 7.8, **13.00 × 4.40 → 0.000 mm³** — and the check is now a hard zero.

250 mm³ off a part of over 100 cm³. **The stand's slot was cut for a slab that existed before the
backpack did**, and every part since inherited that opening as though it were a fact about the
world. It was a fact about a decision.

---

## Tunables (edit + re-run)

| Parameter | Default | Change it when |
|---|---|---|
| `FIT` | 0.35 | board is tight/loose in the pocket |
| `HINGE_L_BOOT` / `HINGE_L_RESET` | 1.20 / 2.00 | **buttons feel stiff → lengthen these, do not thin the hinge and above all do not thicken it.** This is the knob, and it was not obvious. |
| `HINGE_T` | 0.90 | ⚠️ **Read the strain note below before touching this.** Thicker is not stiffer-but-safer, it is *closer to fracture* — strain scales with `t`. |
| `GLASS_GAP` | 0.40 | never reduce below 0.25 — see below |
| `SLOT_CLR` | 0.40 | slab loose/tight in the stand |
| `TILT` | 15° | viewing angle |
| `GRILLE_STYLE` | `"hex"` | `"ridge"` swaps the 59-hex field for lyra's raked dorsal-spine motif. Both were solved to the same **673 mm²** nominal open area; the hex field's throat now measures **640.8 mm² (−4.8 %)** after the AF 4.50 rescale. Aesthetic, not acoustic — the rake never did acoustic work, since these are straight-through bores raked *in the plane* of the wall, not louvered vanes angled through its thickness |
| `HEX_R` / `HEX_WEB` | 2.598 / 0.90 | across-flats **4.50** (= `√3·HEX_R`), pitch 5.40. ⚠️ **`HEX_WEB` is a print floor and does not scale with the cells** — shrinking the hexes spends open area, it does not save it |
| `GRILLE_FLARE` | 0.25 | outward taper at the mouth. **0.25 keeps the mouth webs (0.467 mm) so the honeycomb reads as one; ≥ 0.5196 merges the whole field into a single opening.** `GRILLE_MOUTH_WEB` permits either and forbids the fin in between |
| `SCALLOP_D` / `SCALLOP_Z0` | 12.0 / 5.0 | the finger pockets over the button caps. Since the #31 rim notch these only govern the part of the scoop that dips *below* the notch floor — extra depth under the cap. Deeper reaches further behind the slab and eats the stand's rear wall; there is an assert holding 3 mm of wall |
| `STAND_TOTAL_H` | **56.0** | the whole stand. `PLINTH_H` derives as `56.0 − ST_H`, so the two cannot drift. The derived floor is **54.97**, so there is 1.03 mm of headroom for build tolerance and cable-OD uncertainty |
| `CABLE_RIGID` | 40.0 | JP's measurement: plug tip → first bend. Drives `STAND_TOTAL_H`. If a different cable is used, re-measure **this**, not the height |
| `CABLE_OD` | 4.5 | ⚠️ **assumed, not measured.** It buys the cable's *centreline* `OD/2` of clearance over the desk, so the sensitivity is exactly half: every mm of OD is 0.5 mm of stand height |
| `EGRESS_W` / `EGRESS_H` | 14.0 / 10.0 | the cable channel at desk level. `EGRESS_H` also sets how deep the tail corridor runs, and the corridor drifts *forward* toward the chamber shaft as it descends — there is an overlap-or-clear assert on the wall between them |
| `TAIL_W` / `TAIL_Y` | 18.0 / 8.0 | the corridor from the well down into the plinth. **`TAIL_Y` is the constrained one**: at 10.0 it leaves a 0.95 mm fin against the chamber shaft |
| `BEZEL_DEBOSS` | 0.96 | how deep the honeycomb and wyrm cut into the front face. **Keep it an exact multiple of the bezel's 0.16 mm layer height** — it was 0.45, which is 2.8125 layers, so the recess floor landed wherever the slicer's rounding fell rather than on a real layer boundary. **0.96 is 6 layers exactly.** It was 0.48 (3 layers) through the first print — too shallow to read at arm's length, #34 took it to 0.80 (5 layers), depth only, sizes untouched — and JP's verdict on the printed 0.80 part was "it's good but go even deeper next time pls" (#48). An assert holds ≥2.00 mm of bezel over the glass; at 0.96 the measured floor is **2.04 mm**, so **this is the last depth that fits and there is no room to keep going** — deeper means revisiting the glass floor, which is a different conversation. The shell runs `DEBOSS_BIG` at 0.80 on a thinner wall |
| `BTN_R_BIG / BTN_R_SMALL` | 8.6603 / 5.7735 | the hex caps — **15.00 and 10.00 mm across the flats.** Shrinking them moves the hinge closer to the pip, which raises θ and therefore strain; the thumb-sized caps are what took both hinges to ~1.20% |

---

## The connector labels — and the one thing worth checking by eye

Nine debossed labels now: `SD`, `MIC`, `VOL`, the power symbol, and the five connectors —
`UART`, `I2C`, `SPK`, `BAT`, `IO` (issue #27). Each connector label sits in the 9 mm margin
strip **beside the side channel it names**, rotated to read bottom-to-top like `SD`.

| label | board edge | port centre Y | silkscreen it matches |
|---|---|--:|---|
| `BAT` | **X = 0** (microSD side) | 23.20 | `BAT`, 2-pin, marked `− +` |
| `UART` | X = 0 | 34.98 | `UART`, 4-pin `RXD TXD GND 5V` |
| `SPK` | **X = 50** (mic side) | 36.36 | `SPEAKER`, 2-pin — ⚠️ **top-entry**, see below |
| `I2C` | X = 50 | 49.92 | `I2C`, `3.3V GND IO15(SCL) IO16(SDA)` |
| `IO` | X = 50 | 67.77 | `IO2 IO3 IO1x IO21` |

> ⚠️ **JP: this is the one thing in the part that no check can prove, so please glance at it.**
> `CONN_R` and `CONN_L` are anonymous Y-spans lifted out of the vendor STEP — the model has
> never known which connector is the battery and which is the UART. The names come from the
> **ES3C28P outline drawing's silkscreen**, and the order along each edge is pinned by that
> drawing's own dimension chains, which the build asserts against the STEP: they close to
> **0.02 mm** forward and miss completely when read from the other end, so the direction is
> established rather than assumed. The microSD closes the same chain to 0.06 mm, which is what
> ties the drawing's edge to this model's low-X edge.
>
> That is strong evidence and it is still not a bench test. **Hold the bare board next to the
> printed shell and check one label against the silkscreen** — `BAT` is the easiest, it is the
> one with the `− +` polarity marks. If `BAT` is right, the chain is right and so are the other
> four. This is the same discipline that caught BOOT and RESET being swapped: a physical
> observation anchored to a coordinate beats any amount of re-derivation from a drawing.
>
> ✅ **And one bench observation has already corroborated it.** JP reported (#33) that *the
> speaker plug is top-entry, unlike the side-entry connectors*. Measured out of the STEP,
> **exactly one connector is different** — `CONN_R[0]` is 4.70 mm tall where the other four are
> 3.40, and it is the only one reaching the board's own minimum Z. It is the one the drawing's
> chain names `SPEAKER`. A hands-on observation and a documentary one landing on the same solid
> is two witnesses of different kinds; the build asserts they keep agreeing.

### The speaker plug is top-entry — that is why there is a hole above it (#33)

Its plug and wires leave the board **into the shell**, not sideways, and there was only
**0.80 mm** of headroom above it (every other connector has 2.10). So the back slab is opened
over it: **x 44.54–50.35, y 31.79–40.94, straight through.**

> **A through-opening rather than a blind pocket, and the reason is a bound rather than a
> measurement.** Nobody has the plug's height — it is your speaker's own pigtail and it is not
> in the vendor model. A blind pocket leaving a printable floor caps headroom at **3.00 mm**; a
> 2-pin 1.25 mm plug protrudes ~1.5–2.5 mm past its header and the wires then have to turn.
> "Probably enough" fails an acceptance test that reads *the shell closes fully*. A
> through-opening cannot be too shallow.
>
> ⚠️ It reaches the **cavity** wall on purpose. The connector fills the cavity to within
> 0.80 mm, so the lead cannot pass over the top of it — a 1 mm wire in a 0.80 mm gap is the
> pinched-lead hazard the stand's wire saddle exists to prevent. Taking the opening out to
> x 50.35 lets the lead get outboard of the connector, rise into the cavity, and leave through
> the side channel that already serves this port.

**`SPK` is therefore the one label not level with its port** — its ink sits immediately *below*
the opening rather than on top of it. A label beside a visible hole points harder than a label
over an invisible connector.

**Some labels are not centred on their port, and that is deliberate.** `BAT` and `UART` are only
11.78 mm apart while their ink is 13.28 and 18.04 mm long, so centring both is arithmetically
impossible. They are packed apart **in port order** instead, and the build asserts that each
label's ink still **spans its own port's centreline** — which is what a reader actually does,
look across from the connector and read whatever is level with it — and that no label's ink
reaches into a *different* connector's channel. Order is preserved by construction.

> ⚠️ **They are also spaced by a word gap, not a keepout, and that distinction was found by
> slicing the finished mesh rather than by any check.** The first cut printed `SPKI2C` and
> `BATUARTSD`: every assert passed, but the gap *between* two labels (`LABEL_MARGIN`, 0.80 mm)
> was **smaller than the gap between two letters of one word** (1.00 mm), so the eye read each
> column as a single string. `LABEL_WORD_GAP` is now 2.00 mm — twice the letter space — and it
> is derived from the number it has to beat. If you are reading the printed part and the labels
> still run together, that is the defect to report.

---

## Why some numbers are what they are

- **The glass gap survives printer Z error structurally, not by tolerance stacking — and that
  is a design property somebody could destroy.** The bezel's underside is located by the
  **shell's wall top**, and the board by the **shell's standoffs**. Both are printed in the same
  part, on the same Z axis, from the same bed, so a global Z error scales them *together* and
  the gap is preserved. The stack is exactly consistent — standoff 5.50 + PCB 1.60 + bezel boss
  4.70 = **11.80**, and the shell's `CAV_FLOOR → SEAM_Z` is **11.80** — and the shell's 14.40 mm
  height is **72 layers exactly** at 0.20 mm, so there is no quantisation error either.
  > ⚠️ **Take that 72 from the constants, not from the mesh.** Binary STL stores float32 and
  > 14.4 is not representable, so measuring the exported part gives 14.399999… and
  > **71.999998 layers**. That is storage precision, not a geometry change — but it is exactly
  > the kind of number that makes someone think a datum moved.
  ⚠️ **Move either datum onto the bezel and that cancellation is gone**, and the gap starts
  stacking two parts' errors instead of one part's. What is left is the LCD/TP tolerance
  (−0.20 worst case) and first-layer squish (~−0.05): realistic worst case ≈ **0.15 mm**, still
  positive. Thin, but positive — which is why step 5's rock test exists rather than a caliper.
- **The board pocket starts at printed z 2.60 — 13.00 layers exactly — and that is deliberate.**
  The shell prints back face down, so the pocket floor sits 2.60 mm above the bed and
  **elephant foot lands in the 13 solid layers below it, not in the pocket.** That is the classic printed-pocket failure, *tight at the bottom
  only*, designed out. ⚠️ If you are tempted to extend the pocket down to the bed to save
  material, that is what you would be undoing.
- **`GLASS_GAP = 0.40` — the bezel never touches the capacitive glass.** The vendor tolerances
  the LCD at 2.3 ±0.1 and the touch panel at 1.0 ±0.1, so the glass front face can sit up to
  0.2 mm high. A rigid printed bezel bearing on glass is how you crack a display. The entire
  clamping load runs bezel → bosses → PCB → standoffs → shell; the glass is never in the load
  path. This was a bug in the first iteration, caught before export.
- **Button pads extend in +Y only.** The switches sit just 3.26 mm from the board edge, so a
  centred pad cut straight through the shell's bottom wall. Caught by rendering and looking.
- **The caps are debossed, not raised.** They were raised first, which is the obvious reading
  of "buttons you can feel" and is incompatible with this part's own print orientation: a
  proud cap on a bed face is the *lowest* feature, so the shell would balance on two
  hexagons with the whole back face 1.2 mm in the air. The bbox growing by exactly the cap
  height is what exposed it. Recessing costs nothing, prints unsupported, and means nothing
  resting on the case can hold BOOT low across a reset.
- **The bezel face is debossed too, and for the same reason on the opposite face.** 57
  honeycomb cells across the chin, a 16-cell chain up each rail (2.60 mm across the flats on a
  0.70 mm web), and the hearth-wyrm **25.65 × 11.25 mm** in the brow — all **0.96 mm** deep,
  which is exactly six layers at this part's 0.16 mm (it was three, which #34 found too
  shallow to read on the printed part, then five, which JP validated but asked to go deeper
  still — #48; the sizes above are unchanged throughout). This part
  prints front face down, so a raised logo would be the lowest feature and the bezel would land
  on it. **On a bed face, relief only goes inward** — that it bit both shell parts in the same
  session, on opposite faces, is the tell that it is a property of the process, not a mistake.
  The wyrm's *size* is set by the print floor rather than the space available: the generator
  **declares** a minimum feature of 1.2333 mm at unit scale, the mark is scaled by
  `0.90 / 1.2333`, and scaling it any larger — to fill the brow — would take the thinnest part
  of the creature under the 0.90 mm floor.
  > ⚠️ **That 0.90 mm is placed there by arithmetic, not confirmed by measurement.** The build
  > prints the mark's min feature as `WYRM_MIN_FEATURE × scale`, and the scale is *defined* as
  > `0.90 / WYRM_MIN_FEATURE` — so the figure is 0.900 for any value of the constant, and the
  > assert that checks it is ≥ 0.90 is comparing a number with itself. It is sound while the
  > declared constant is a true lower bound on the shape, and **blind in exactly the direction
  > that would hurt**: if the constant were larger than the creature's real thinnest feature,
  > the mark would be scaled too big, the true minimum would land under the floor, and the
  > build would still report 0.900 and pass. If you are checking a printed bezel, check the
  > *creature*, not this number.
  **The mark is mirrored, and its placement is a centring rather than a margin.** The creature
  is drawn facing left, so unmirrored its *tail* pointed at the mic port and the gesture ran off
  the face. Mirrored, the head faces the flare. Ink runs x 7.700–33.351 and the flare's right
  edge is at 42.300, which puts the creature-and-port group dead on **x 25.000 — the face
  centreline** — and that is asserted, because every other check on this face is a clearance and
  a clearance is satisfied by any amount of slack in the wrong place. The cost, on the record:
  this is the one of the wyrm's four renderings that is handed the other way, and it is **not**
  at top-left.
- **Two of those cells used to sit on a screw boss, and it mattered for printing.** Nine chin
  cells per boss overlapped the fastener — four over the 2.50 mm pilot, five over the 5.40 mm
  pad — thinning the bezel roof over a self-tapper from 1.50 mm to **1.05 mm**. It was never a
  hole, which is why nothing flagged it. If you are checking a printed bezel against this
  sheet: the chin honeycomb should stop cleanly short of all four boss positions.
- **The hinges are sized by strain, not by feel — and the intuitive fix cracks them.** Bending
  strain in a flexure is `(t/2)·θ/L`, and **θ is not a free variable**: it is pip travel over
  the pip's distance from the hinge. The *smaller* cap therefore bends *further*, because its
  pip sits on a shorter arm. At 9.01 mm caps and a shared 1.00 mm flexure that put RESET at
  **4.37%**, past PLA's ~2% yield and into its 4–6% break band. The natural remedy, thickening
  RESET's hinge so it presses firmer, takes it to **6.79%**: strain scales *with* thickness, so
  the obvious fix points the wrong way. Lengthening the flexure works — and so, it turned out,
  does **making the caps bigger**, which was asked for on looks: a wider hex puts the hinge
  further from the pip, so θ falls with it. Shipped at 15.00 / 10.00 mm across the flats:
  **BOOT 1.20% (θ 1.83°, L = 1.20) and RESET 1.19% (θ 3.04°, L = 2.00)**, against an assert
  that was tightened from 2.5% to **2.0%** at the same time — the old threshold was calibrated
  to what 9 mm caps could achieve rather than to what the material wants, and an assert
  inherited from a worse version of the part is a ratchet pointing the wrong way. The force
  ordering stays mildly inverted and that is the accepted trade — an easy RESET is an
  annoyance, a cracked RESET hinge is a dead part, and findability is already carried by cap
  size and deboss depth, which cost no strain at all.
  > **Every other check in this file would have passed all three variants happily.** The
  > geometry is valid, nothing collides, the pad stays attached, the solid is watertight, it
  > prints. It just breaks in your hand after a few dozen presses. Every assert here was about
  > *shape*; this is a property of the *material*. Worth asking of any parts library: which of
  > your invariants are about form, which are about matter, and is the second list empty?
- **⚠️ Superseded in part by #31: the rear rim is now notched, not just scooped.** Everything
  below is still the correct diagnosis — the obstruction is *lateral* and a taller cap cannot
  reach past it — but the scoop only ever removed 12 mm of the wall's depth, leaving a pocket a
  finger had to descend into blind. The fix is **rim height**, and the relation is exact:
  `H_rear = SLOT_FLOOR + (PAD_Y0 − OY0)·cos(TILT)`, cutting the wall right through across the
  cap span (stand x 13.20–50.23) down to **z 43.62 in the STL** (27.62 in the source frame —
  see *The plinth*). `PAD_Y0` **is** both caps' bottom edge for any cap radius, because they are
  flat-top hexagons centred at `PAD_Y0 + R√3/2`, so a cap resize carries the notch with it.
  **It removes approach, not retention:** the slot's two x-extremes keep the full 16.56 mm of
  engagement over 19.67 mm of full-height rim, which is what still contains the lean. Lowering
  the *whole* wall to the same height would leave 3.75 mm everywhere and let the slab flop back
  ~6°. The scoop survives underneath the notch, adding depth below the cap.
- **The stand has finger scallops, and a taller cap would not have worked.** Docked, the stand
  swallows the first 16.56 mm of the slab. At the old 9.01 mm caps that put BOOT's cap 3.81 mm
  *below* the rim and RESET's 6.23 — with 0.40 mm between the cap face and a solid wall. The
  thumb-sized caps changed the arithmetic but not the conclusion: BOOT's top edge now stands
  **2.19 mm proud of the rim**, while **RESET is still 2.81 mm under it**, so the scallops are
  still what makes both buttons pressable while docked. A finger does not fit in
  0.40 mm, so **the obstruction is beside the cap, not above it**, and no amount of cap height
  reaches past material that is alongside it. A scallop rather than a through-window because
  the rear wall is ~19 mm thick there — a window would be a tunnel, not an access port. And a
  bottom-hinged lever with a thumb tab, which is the other obvious fix, is unbuildable here:
  the hinge angle is fixed at 0.40/2.46 = 9.3° by pip travel and does not improve with a longer
  lever, and holding PLA through 9.3° needs ~4 mm of thinned flexure where there are 2.46 mm.
- **Side channels are deliberately generous.** See the open question below.
- **Shrinkage:** PLA ≈0.3 % over 86 mm = 0.13 mm/side, PETG ≈0.5 % = 0.22 mm/side — both
  inside the 0.35 mm pocket fit, so **no scaling compensation is needed**.

---

## One thing to check on the physical board

> ### ✅ The mic question is ANSWERED — do not go looking.
>
> **JP inspected the board: the microphone fires FORWARD, through the front face, and the
> hole is visible in the product photos.** The bezel's ⌀2.40 mm port and its acoustic collar
> are the working path. The ⌀3.00 mm relief through the back shell is redundant — it stays
> because it costs nothing and this board is resold under several brands, so a variant with
> a rear-firing mic is plausible.
>
> Recording *why* it needed a human, because it is the most reusable thing on this page: the
> vendor STEP contains **no small holes at all — not a single via**, because the CAD export
> suppressed them. The absence of a port in the model was never evidence there wasn't one.
> **A model's silence is not an answer.** Five seconds of looking settled what a 17 MB solid
> could not.
>
> ⚠️ This section has now been corrected **twice**. The first fix was overwritten by copying
> a stale working copy over the repo — the same stale-copy failure this project has logged
> six times. If you are editing this file, edit it *here* and copy outward, never inward.

**2. Where does the microSD card actually go in?** The STEP simplifies the socket to a flat
11.15 × 14.15 × 0.5 mm plate at x 33.68–44.83, y 15.84–29.99, which doesn't resolve the
insertion direction. That's why both long edges get a continuous channel across y 14–75 and
y 14–42 rather than a neat per-connector cutout. If the card turns out to be blocked, the fix
is one parameter, not a redesign.

---

## What this sheet cannot tell you

Named explicitly, because **a checklist that implies it covered everything is worse than one
that marks its own edges.** None of these is measurable from the geometry, and no amount of
re-checking the model will settle them:

1. **Whether the printed-in-place button slots opened.** 1.50 nozzle widths is above the point
   where a slicer refuses and below the point where it is safe. See step 3.
2. **Your actual printed pilot diameter.** Modelled 2.50 and printed holes come out 0.1–0.3 mm
   undersize, which lands it mid-band for thread-forming — **measure one boss before you drive
   four screws.**
3. **Thread quality in your PLA at your temperatures** — brittle when cold, gummy when hot.
4. **Your module's real LCD + touch-panel stack height.** This is the entire glass-gap risk, and
   it is why step 5 is a feel test rather than a number.
5. **Whether the driver's own pigtail reaches the wire pass.** A property of the module, not of
   the case.
6. **Whether the seal actually seals.** A leaky "sealed" box costs exactly the low end the
   chamber exists to produce, and an audible A/B sealed-vs-unsealed is the only test.
7. **The well/channel junction (fixed in r3, was a real defect in r2).** r2 printed a thin
   membrane straight across the USB-C bore where the egress channel's roof passed it — JP had
   to carve it out before the plug would pass. The corridor now runs `(TAIL_Y/2)*tan(TILT)`
   past the channel ceiling so the two voids merge and no roof plane crosses the bore. Verified
   by sectioning: material inside the bore footprint used to spike to 85.1 mm² at the roof
   plane with void beneath it, and is now monotonic into the junction. **Leave bridging on** —
   the channel's own 6.0 mm roof span is unchanged and still bridges.
8. **Acoustics.** The throat is 607.8 mm² against the driver's ~700 mm² — 86.8 % on paper,
   and 9.7 % under the 673 mm² the baffle was solved for (#47 spent 4.9 of those points on a
   printable web, deliberately). The finer lattice spends open area
   on webs that do not scale with the cells; whether that is audible is not predictable from
   area, and it is the one number here most worth trusting your ears over.
9. **Your USB-C cable's overmould.** The well is generous — 22 × 12 mm, 20.7 mm along the tilt —
   but plugs vary more than the spec suggests.
10. **Cosmetics of the grille mouth.** 37 discrete flared holes across a 38 × 25 mm field.
   Earlier print sheets promised *one* merged aperture with the honeycomb behind it — that was
   true at the old 0.60 mm flare, and is not true at the current 0.25 mm (mouth web 0.4670 mm,
   positive, so the cells stand apart). You are getting a honeycomb face, not a single slot.

The one that has moved from this list to fact: **the bezel's 3 non-manifold edges did not
matter** — it printed, and the dimensions are good.

---
## Provenance

Everything structural was **measured from the vendor STEP solid**
(`ES3C28P_3D.step`, Altium→OpenCASCADE, 2025-06-10) — not transcribed from a datasheet
table: PCB outline, the 4 ⌀3.20 holes at (4,4)/(46,4)/(4,82)/(46,82), the 10.60 mm stack,
glass face at Z+4.30, deepest back component at −6.30, USB-C at X 20.53–29.47, both rear
switches and their plunger tips, the mic package at (40.0, 81.5), the WS2812 at (29.0, 45.6),
all five 1.25 mm connectors, and the antenna keepout.

Both shell parts are boolean-verified against that solid at **0.000 mm³ interference**, and
the checker is self-tested each run by deliberately sinking the bezel 2 mm into the board
(reports 1467.8 mm³ — so a real collision would not pass silently).

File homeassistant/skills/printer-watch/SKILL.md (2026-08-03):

---
name: printer-watch
description: >-
  How to answer questions about the 3D printer and running prints, and what to do
  when a print looks stuck. Use for anything about the printer, a print, how far
  along it is, when it will finish, or whether it has gone wrong.
---

# Printer watch

The printer is an OctoPrint machine called serialhub. `check_print` is your only
source of truth about it. Never state a percentage, a filename or a finish time
that did not come from a `check_print` call in this conversation.

## Answering the ordinary question

Call `check_print`, then say the useful part in one sentence.

- `state=Printing` — say what it is printing, roughly how far along, and how long
  is left. Round for speech: "about two thirds through, roughly an hour left" is
  better than "60 percent, 1 hour 10 minutes". Never read the filename's hash or
  the `.gcode` extension; the tool has already stripped them.
- `state=Operational` and `nothing is printing` — the printer is on and idle. Say
  it is idle, not that it is "operational".
- `printer_unreachable=true` — say you cannot reach the printer, and that you
  therefore do not know whether it is printing. Do not soften this into "nothing
  is printing"; those are different facts and JP acts on them differently.

If asked only "is it done?", answer yes or no first, then the detail.

## When a print looks stuck

You cannot see a stall in a single reading — a percentage is a snapshot, and one
snapshot never proves that nothing is moving. So:

1. Treat these as real trouble on the spot, no second look needed:
   - `state=Paused` — the print is stopped and waiting for a person.
   - `printer_unreachable=true` while JP believes a print is running.
   - `state=Error` or anything else that is not Printing, Paused or Operational.
2. If JP suspects a stall and the state is still `Printing`, call `check_print`
   again after a short pause in the conversation and compare the percentage. Say
   plainly which you did: "it has not moved since I last looked" is a measurement;
   "it seems stuck" is a guess.
3. `time_left=unknown` on its own is not a stall. OctoPrint reports that early in
   a print before its estimate settles.

## Escalating

When something is genuinely wrong, do these in order and stop as soon as JP has
what he needs:

1. Say what is wrong in one sentence, with the number that shows it.
2. Offer the camera: `look_at_camera` with `camera=printer` for the nozzle, or
   `camera=printroom` for the wider view. Remember you cannot see the picture —
   put it up, say you have, and let JP look. Never describe the image.
3. If the printer is unreachable, `realm_status` will not help: serialhub is not
   one of the machines Home Assistant watches, and the tool will say so honestly.
   Say the printer is not answering rather than implying the host is down.

Do not pause, cancel or resume a print. Never offer to. A print is JP's to stop,
and the bed being clear is a thing only he can confirm.

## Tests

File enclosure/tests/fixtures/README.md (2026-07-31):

# Label-spacing control fixtures

Both are **real builds**, not synthesised meshes, and that distinction is the whole reason
they are in the repo: a control that never crosses the slice→loop front end proves only that
the arithmetic works.

| fixture | geometry | must |
|---|---|---|
| `back-shell-chamfered-wordgap-0.80.stl` | **post-#35, what ships today** | FAIL |
| `back-shell-wordgap-0.80.stl` | pre-#35, no exterior chamfer | FAIL |

The must-**pass** control is not a fixture: it is `../../ember-back-shell.stl`, the shipped
shell itself, so it tracks whatever is actually being printed rather than a snapshot that
can go stale. Which is exactly how the tool went blind — see below.

## What they are

`ember_case.py` built with one line changed:

```python
LABEL_WORD_GAP = LABEL_MARGIN        # 0.80, instead of 2 * (LABEL_GAP - LABEL_W) = 2.00
```

That reproduces the **original `SPKI2C` / `BATUARTSD` defect** through the real pipeline —
`text_paths() → mirror → placement → boolean cut → STL export`. Sliced at z −9.50 and looked
at, the left strip reads `BATUARTSD` as one continuous string, against `BAT` `UART` `SD` on
the shipped part.

⚠️ **Both builds exit 0.** Every assert in `ember_case.py` passes at 0.80, including the two
that mention `LABEL_WORD_GAP` by name — they compare placement against the constant, and the
constant is what moved. That is not a flaw in those asserts; it is the reason a mesh-level
check has to exist alongside them.

## Why there are two, and why the pre-chamfer one stays

`#35`'s exterior chamfer broke the check within minutes of it landing. The depth difference
had assumed the part outline is the same shape at both slice planes; a chamfer makes it a
function of z — measured, 54.700 mm wide at `z_in` against 55.300 mm at `z_below` — so the
perimeter stopped matching itself, survived the difference, and **swallowed the entire text**
(every glyph is nested inside the outline, so the counter-dropping step discarded all
twenty). The tool reported `BLIND` rather than a false pass, which is the one thing that
went right.

The fix is `drop_silhouette()`, which removes loops **reaching an extreme of the part's own
silhouette** — not loops that are *big*. Sizing would be the wrong test and a dangerous one:
a merged `BATUARTSD` run is also large, and a rule that discarded the biggest loop would
discard the defect. The pre-chamfer fixture stays so that fix is pinned against both
geometries at once.

## Why they are cropped

Full builds are ~1.79 MB. Only triangles crossing the two slice planes can affect the result,
so each is reduced to the z band `zmin-0.01 .. zmin+0.60` → ~1.13 MB. The reduction is
**verified, not assumed**: `glyph_boxes()` returns the identical 20 glyph boxes at the
identical 6.40 mm ink height from cropped and full meshes.

Not cropped in XY, deliberately — the hex field, counterbores and speaker relief are what the
depth difference has to discriminate against, and an XY crop to the label strips would delete
the discrimination the check is being tested on.

## Regenerating

```bash
# in a worktree, NEVER the main tree — a build rewrites all four STLs where it runs
sed -i 's/^LABEL_WORD_GAP = .*/LABEL_WORD_GAP = LABEL_MARGIN/' ember_case.py
cadenv/bin/python ember_case.py     # ~9 min. The STEP-import step at the end fails on a
                                    # missing vendor asset, AFTER the STLs are written.
<crop to the z band>  ember-back-shell.stl  tests/fixtures/<name>.stl
git restore --source=HEAD -- ember-back-shell.stl ember_case.py
```

## What they must do

`python3 tools/label_export_check.py --selftest` must report the shipped shell **PASS**
(ratio 1.39) and both fixtures **FAIL** (ratio 0.56) — and **all three must recover exactly
20 glyphs**. That glyph count is not decoration: the chamfer failure looked precisely like
"fewer loops than expected", so it is what stops a future filter tweak from quietly eating
text and leaving a check that still says OK.

If a fixture ever passes, the check has stopped seeing the defect it exists for, and the
check is wrong — not the fixture.

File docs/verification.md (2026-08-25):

# Verification notes

Four faults on this project shared one structure, and naming it is worth more than the four
fixes: the fixes are specific, the structure keeps recurring. It has now appeared in
geometry, in rendering, in audio and in prose.

The corollaries below are separate lessons, collected here because each was learned once and
written into a commit message that nobody would ever read again.

---

## The pattern: an invariant that holds because something else absorbed the error

> **For each invariant, ask what could absorb a violation and still satisfy it.**

None of the checks below is a weak assertion. Each is an assertion whose **success
condition is insensitive to the failure mode it appears to guard**. They pass, and the
passing is sometimes *caused* by the defect's own symptom.

### 1. `check_tiling` passes on a flame that is silently clipped

The clearest instance, and the one the rule was derived from.

The display asserts a **write-once invariant**: every pixel in the flame band written
exactly once. Set `GRATE` 3→8 and `MAXH` is forced down. **`MAXH = 65` passes
`check_tiling` and is still wrong** — it lets a flame reach into the fuse rows. But the
fuse branch runs *before* the fire logic:

```cpp
if (r < FUSE_H) { …; continue; }
```

So an over-tall flame is not rejected, it is **clipped flat**. Every pixel is still
covered exactly once — by the fuse. **The assertion is satisfied by the very mechanism
that conceals the defect.**

(The correct value is `MAXH = 64`, not 63: a 5.9% flame-height loss, not 7.4%.)

### 2. A boolean clearance check cannot fail on empty space

The enclosure's boolean check reported **0.000 mm³** interference through every
revision — correctly — while the stand covered **19.5% of the screen**. Nothing
intersected. The stand was simply *in front of* the display.

**A test that measures interference is structurally blind to occlusion.** No amount of
tightening it would have helped; it was answering a different question.

The same check was blind to the buttons being **100% buried** inside the stand, and to
there being **6 mm** of room where a USB-C plug needs 18–20 mm.

### 3. Sampling the one locus where the discrepancy vanishes

The USB-C well was cut as a flat box while the slab slot's bottom face **tilts** — front
corner at z ≈ 26.4, rear at ≈ 21.6 — leaving a wedge of material exactly where the plug
emerges.

It measured as "20 mm clear" because the check **point-sampled the centreline**, which is
the single locus where that discrepancy is zero. A plug has width; its front corner hit
the wedge.

### 4. `esphome config` passes with a broken `static_assert`

The same shape in a *tool*, and it invalidated a verification instruction I had given.

Adding a `static_assert` to a display lambda, I asked for it to be verified with
`esphome config` — no device touched, returns `Configuration is valid!` with the two known
GPIO45/46 strapping warnings and nothing else.

**It also returns exactly that with the assert deliberately broken.** `config` validates
YAML and *never builds the lambda*, so its success condition is entirely insensitive to
whether the C++ compiles at all.

`esphome compile` is the stage the change actually lives in, and also needs no device. It
reported the assert firing, attributed to the **YAML line** with the arithmetic spelled out:

```
esphome/ember-satellite.yaml:3369:35: error: static assertion failed: MAXH is too tall
for GRATE: the tallest flame reaches into the fuse rows and will be silently clipped flat.
note: the comparison reduces to '(74 <= 73)'
```

> **Know which stage of a toolchain your change lives in, and verify at that stage.** A
> green result from an earlier stage is not weak evidence — it is *no* evidence.

### 5. The right number, about a part that did not exist

The purest form of the pattern, and the closest one to being printed.

`RegularPolygon(R, 6)` is **flat-top** — two vertices share the maximum Y, so a cell is `2R`
across corners in X. Both hex lattices spaced columns at `dx = aflat + web`, which is
*pointy-top* spacing. At R = 3.75 that is a **7.500 mm cell on a 7.395 mm pitch**: the cells
overlapped, the web went negative, and the field fused into **one solid instead of 33**.
Flood-filling it showed 43 loose prisms of 2.53–5.38 mm² spanning the full wall. It would
have printed as a single 37 × 24 opening with loose triangles rattling in it.

**The asserted open area still measured ~673 mm², exactly on target.** Area is insensitive
to whether a region is *connected*, so the number was right while the part was ruined — and
the comment promising "0.80 mm of material remains between slots, still printable" was false
as built. The back panel's stated 0.80 mm web measured **0.305 mm**.

The assert is now on the property that actually matters:

```python
assert len(_cells.solids()) >= 30
```

> **Assert the property, not a proxy for it.** An aggregate — area, volume, a count of
> writes — can be exactly correct about something that is structurally broken.

**A postscript that sharpens this rather than softening it.** `len(_cells.solids())` counts the
**cutting tools**, not the holes they leave in the part. It is exactly right for the question it
was added to answer — *have the cells fused into one solid?* — and it is **not an aperture
count**, which is how the line reads. Measured on the field as built: **33 cells placed produce
27 openings**, six being clipped away by the field's rounded corners, and the assert would pass
identically at either number.

So the replacement for a proxy was another proxy, and that is fine as long as it is *named*.
The rule survives with a clause: **assert the property, and then say which property**, because
the next reader will take the count for the thing it superficially describes. The same field
also has two open areas — a **607.8 mm² throat** and a **715.9 mm² mouth**, across 37
apertures each — so "the grille's open area" was ambiguous for as long as it went unqualified,
while every number attached to it was correct.

**A second postscript, and this one caught the person quoting the rule.** The back shell's
countersink is cut at **84.7°** against a standard 90° screw head. The instruction issued to fix
it was *"assert the included angle, not the mouth diameter"* — which sounds exactly like this
section's advice and is wrong, because **a flat head does not seat on an angle. It seats on an
angle *and* a diameter.**

The geometry is unforgiving about it. Two 90° surfaces have parallel flanks, so if the cone's
mouth is wider than the head, the head simply descends until its **rim** meets the wall, at
`s = (mouth − head) / 2`, touching along a line instead of over the cone:

| cone | 6.00 head | 6.40 head | 6.72 head |
|---|---|---|---|
| ⌀6.70 × 1.70 — 90°, mouth left free | sinks 0.35, rim only | sinks 0.15, rim only | proud 0.01 |
| ⌀6.40 × 1.55 — 90°, mouth = head | sinks 0.20, rim only | **flush, full conical seat** | proud 0.16 |

Widening the mouth to 6.70 makes the angle correct and the **seat worse** — a 6.00 head sinks
0.35 mm there against 0.22 in the part as built. **The corrected property was not the one that
governed the outcome**, which is this section's own failure mode, arriving inside an instruction
to avoid it.

The formulation that cannot be satisfied by the wrong thing is to **name the screw** and derive
the rest: `CSK_HEAD_D`, `CSK_HEAD_ANGLE`, depth computed from both. Then "which head is this cut
for?" has an answer in the source, and a different head becomes a *stated alternative* with its
own numbers rather than a caveat.

> **When a fit depends on two properties, asserting either one alone is a proxy.** The tell is
> that you can satisfy the assert and still be further from the goal than when you started.

### 6. A test that could not fail at all

The clearance checker once returned a confident `CLEAR` that meant nothing: the vendor
STEP lives in its own coordinate frame while the parts are in board coords, so the two
**never overlapped in space** and every boolean returned empty.

It surfaced only because a bezel was deliberately sunk 2 mm into the board and the
detector *still* said `0.000`.

> **There is now a permanent self-test doing exactly that, and it must report
> `1467.842 mm³`. If it ever reports zero, the checker is broken — not the parts.**
>
> *(2026-08-25: the figure tracks bezel geometry and is now **1512.804 mm³** — the #41 boss
> flare moved it and no doc was updated, which is this document's own failure shape landing on
> its own pages. Current value lives in `enclosure/README.md`; the zero-means-broken rule is
> the part that doesn't move.)*

#### The same shape in a status probe: a query that answers about itself

Not an assert this time — a one-liner used to check whether a background job was alive:

```bash
pgrep -f make_renders >/dev/null && echo RUNNING
```

It reported `RUNNING` four times, over about an hour, for a process that **had exited within
seconds of starting.** `pgrep -f` matches against *full command lines*, and this command line
contains the literal `make_renders` — so pgrep found **itself**. The control makes it plain:

```
pgrep -f make_renders     -> MATCHED, and no such process exists
pgrep -f zzz_nonexistent  -> MATCHED (self)
```

A pattern that has never named anything still matches, which is the whole proof: the probe was
answering a question about **its own existence** rather than about the world, and it could not
return negative.

> **A process query whose pattern appears in its own invocation is querying itself.**

That single mechanism produced three different-looking bugs in one day, which is the reason to
name the family rather than any one instance:

| form | consequence |
|---|---|
| `pkill -f foo` | **kills its own shell** — the chained command after it silently never runs |
| `until ! pgrep -f foo; do …` | **never exits** — two waiters spun 46 and 35 minutes |
| `pgrep -f foo && echo RUNNING` | **always reports present** — four fabricated status lines |

Each reads as a different fault — a crash, a hang, a stuck job — and all three are one
self-reference. The fixes are trivial and worth having by reflex: bracket a character so the
pattern cannot match itself (`[m]ake_renders`), match on the interpreter and script path rather
than a bare word, or **do not ask about the process at all — ask about its output.**

The last is the one that would have worked here, and it connects to §26: *"no file yet" cannot
distinguish "still building" from "died on line one"* — but the **log** could, and it said so
from the first second. **When a cheap indecisive instrument and a cheap decisive one are both
available, the only reason to use the first is that it was already in your fingers.**

### 7. The reboot that verified the firmware also uninstalled it

The three-mode firmware was flashed OTA, and a hardware probe then rebooted the device to
check that the mode survived a power cycle. It did not: the mode select came back reading
`Normal` while the `Hush` switch still read `ON`. A real defect — the select was
`restore_value: false` with nothing re-syncing it from the persisted `op_mode`.

A fix was written, flashed, and the same probe re-run. **It reported the identical
failure.** The obvious reading — "the fix doesn't work" — was wrong, and the reason is
that the fix *was no longer on the device*:

```
[W][safe_mode:094]: OTA rollback detected! Rolled back from partition 'app1'
[W][safe_mode:094]:  The device reset before the boot was marked successful
```

`safe_mode` marks a boot good after **60 s**, and ESP-IDF rolls an unvalidated OTA image
back to the previous partition if the device resets first. The probe rebooted ~12 s after
upload. **The act of testing reverted the thing under test**, and the second measurement
was taken against the first binary — so it faithfully reproduced the bug the fix had
already removed.

Two claims were available and both would have been false: *"the fix doesn't work"*
(measured the wrong binary) and, had the probe happened to pass, *"the fix works"* (also
the wrong binary). The rollback was printed in the log the whole time.

> **After an OTA, read back what is running before concluding anything from its
> behaviour.** `[I][app:151] compiled on <timestamp>` must match the `build_time_str` the
> upload reported. Then wait for `[I][safe_mode:142] Boot seems successful` before any
> reboot-based test — until that line appears the device can silently revert underneath
> you.

Same family as the rest of this file, one turn further out: not an invariant satisfied by
the wrong mechanism, but a *test* satisfied by the wrong artifact. `esphome upload` ships
a stale binary; a rollback ships a stale binary *after* a correct upload.

### 8. The check's scope was one file; the claim's scope was the system

The mode patch carried a self-check that nothing still read `sw_hush` as state, and it
passed — proving all six touchpoints moved **inside `ember-satellite.yaml`**. The widened
meaning of `Hush` was then reported as handled.

It was not. Four tiles, one conditional card and two `mdi:microphone-off` icons in
`homeassistant/dashboards/ember-hearth.dashboard.json`, plus two sections of
`docs/home-assistant.md`, still told the reader that Hush *"gates the talk gesture"* and
that *"tapping the screen will not start a conversation"*. Every one became false the
moment the firmware booted — the same lie the spec had just deleted a dark-LED branch and
a telemetry string to avoid, surviving on a bigger screen.

An anchor assertion can only fail in a file it is pointed at. The count was also wrong on
the first attempt: the guard expected one stale icon and found two, because a fourth Hush
tile is named plainly `"Hush"` and only its *icon* carried the old meaning.

> **When a control changes meaning, the blast radius is every artifact that describes it,
> not every artifact that reads it.** Grep the entity id across the whole repo — docs,
> dashboards, packages — not just the firmware that implements it.

---

### 9. A total that absorbed a complete absence

The bezel's debossed honeycomb is generated by filtering a hex grid against keepouts, and it
is guarded by an assert. The assert read:

```python
assert _n >= 60, f"only {_n} hex cells landed on the bezel"
```

It passed. 75 cells landed, and 75 >= 60. **All 75 were in the chin and the rails had none** —
the nearest grid column missed the rail's 0.75mm-wide usable band by 0.05mm. The stand covers
86% of the chin and 0% of the rails, so the entire motif had landed on the one surface you
cannot see while the device is docked.

Applying the rule at the top of this file — *what could absorb a violation and still satisfy
this?* — the answer is immediate and should have been asked before the assert was written: **a
sum over regions can be satisfied entirely by one region.** The number was real. It was simply
not the property. The fix is a per-region dict with a non-empty assert on each, which no
single total can satisfy vacuously.

The same defect appeared twice more in the same afternoon, in different materials, which is
what makes it worth its own heading rather than a line in a list:

- **A raised feature on a bed face.** The button caps stood 1.20mm proud of the back shell's
  back face — which is the face that prints against the bed, so the part would have balanced
  on two hexagons totalling ~74mm2. What caught it was not a check but a **bounding box**: the
  part had grown from 14.40 to 15.60mm, exactly the cap height. Then the identical mistake was
  nearly made again on the *opposite* face of a *different* part, because the bezel prints
  front-face-down and the logo was going to be embossed. Twice in one session on two faces is
  a property of the process, not a slip: **on a bed face, relief only goes inward.**
- **A figure carrying its own copy of the geometry.** `make_renders.py` hand-wrote the button
  outline as a four-point rectangle instead of reading the part. Both copies happened to be
  rectangles, so they never disagreed and nothing was ever caught — until the part became
  hexagonal, at which point the *only thing anyone looks at* would have gone on drawing
  squares indefinitely. A second hand-drawn copy of geometry is not documentation of the
  geometry, it is a rumour about it.

### 10. A figure set that was individually accurate and collectively blind

Both buttons were **completely buried** by the stand: the BOOT cap's top edge sat 3.81mm below
the stand's rim with 0.40mm between the cap face and solid wall. Five figures existed. Not one
was wrong, and not one could show it — the exploded and print-layout views show the parts
separated, the hero shows the front, the back 3/4 shows the shell alone. **No figure put a
button and a stand wall in the same frame**, which is the only place the answer lives.

It was found by a person asking a question, not by a check: *"are those new hexagon buttons
tall enough? seems like there should be a tab to bring them taller to be more accessible when
in the stand."* The instinct was right and the diagnosis was better than the proposal — a
taller cap reaches nothing, because the obstruction is *beside* the cap rather than above it.

Two things follow. First, ask what each figure **cannot** show, and add the view that closes
the gap — the same discipline as asking what an assert would still pass on. That view is now a
permanent figure rather than a one-off check. Second, this is the **third** feature the stand
has quietly swallowed: the display, the USB-C plug, and now the buttons. There were asserts
for the first two. Nobody generalised. *"Does it collide"* and *"can you reach it"* are
different questions, and every feature a human has to touch needs the second one asked
explicitly — enumerate them rather than trusting that a previous assert's neighbourhood
covered them.

### 11. Every check passed; it breaks in your hand

The button pads are living hinges. A teammate, reasoning about how they would *feel*, observed
correctly that with equal hinge thickness the smaller hex always presses lighter — backwards
from the intent that RESET be shyer under the finger — and proposed thickening its hinge from
0.90 to 1.40 mm.

Bending strain in a flexure is `(t/2)·θ/L`, and **θ is not a free variable**: it is pip travel
over the pip's distance from the hinge. The *smaller* cap therefore has the *larger* angle,
because its pip sits on a shorter arm — 5.6° against 3.5°.

| | t=0.90, L=1.0 | t=1.40, L=1.0 | t=0.90, L=2.0 |
|---|---|---|---|
| BOOT | 2.75% | 4.28% | 1.37% |
| RESET | **4.37%** | **6.79%** | **2.18%** |

PLA yields near 2% and breaks in the 4–6% band. So the shipped RESET hinge was *already* over
strained, and the proposed cure took it further. **Strain scales with thickness — the fix
pointed the wrong way.** Lengthening the flexure fixes what actually breaks.

**What makes this its own entry is that no existing check objected to any of the three
variants.** The geometry is valid, nothing collides, the pad stays attached to its hinge, the
solid is watertight, it prints. Every assert in the file is about *shape*, and this is a
property of the *material* — it fails after a few dozen presses in a hand, which is not
somewhere a boolean can look. The lesson generalises past hinges: **ask which of your
invariants are about form and which are about matter, and notice if the second list is empty.**

A secondary point worth keeping: the diagnosis was right and the remedy was wrong. Accepting a
correct finding does not oblige you to accept the fix attached to it.

---

## The one variant no tool can catch

Every fault above yields to mechanism — a compile step, an assertion, a sanitizer, a
byte-comparison of rendered output. **One does not, and it is worth separating for exactly
that reason:** a list of failures that all submit to tooling invites the belief that tooling
is sufficient.

A report stated that `NC = 80` *"compiles clean and the harness reports ALL CHECKS PASSED."*
It was wrong. `NC = 80` had been run **only under AddressSanitizer**, and `NC = 40` **only
plain** — two real experiments, neither of them the configuration described. The claim
carried the authority of both and the coverage of neither.

**No tool can distinguish "I ran this configuration" from "I ran two adjacent ones and
described a third", because the artifact of a claim is prose.** There is nothing to compile,
nothing to diff, no assertion to add.

The two defences are procedural, and both were used the same afternoon:

> **Reproduce a teammate's result before building on it.** It cost one rebuild and caught
> this. The same discipline caught an issue about to be opened against already-finished work.
>
> **Say which configuration you ran, not which conclusion you reached.** A conclusion is
> compressed and its compression is where the coverage goes missing.

**And the same rule in the other direction, which is the one that is easy to skip: when a
teammate's report contradicts your own instrument, re-test before believing yourself.** The
forward form guards against inheriting someone else's error. The reverse form guards against
your own, and it is harder to apply, because the instrument is right there and it just ran.

It was worth exactly one re-check. A sweep reported that a control still lacked a boot resync;
the person who owned the file had said it was fixed. The regex was wrong (§18) and the report
about to be filed was false. **The disagreement itself was the signal** — not the confidence of
either party — and the cheap move was to spend one command finding out which side was broken
rather than to assume it was the other person's memory.

Both directions reduce to the same thing: a claim and an instrument are two artifacts, and when
they disagree, *either* may be the defective one. Nothing about having just run something makes
it the reliable half.

A related instance from the same session, self-audited: a twelve-row truth table reported as
verifying the audio gate in fact checked **a transcription of the watchdog, not the
watchdog** — so it proved the design coherent over its input space and said nothing about
whether the firmware implements it. It also hardcoded one input to its default, and that
input was the documented A/B knob for disabling amp gating entirely — precisely the case
where the other half of the gate carries it alone. True about what was run; overstated about
what it covered.

**Both failures share a shape: a claim one step wider than its evidence.** Neither author was
careless and neither claim was false — each was assembled from true parts.
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

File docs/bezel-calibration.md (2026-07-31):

# Front bezel — predictions BEFORE looking at the printed part

Morpheus, 2026-07-30. **This is a calibration, not an audit.** Every tool built today forecasts
what a printer will do and **not one has been scored against a printer that has done it.** JP has
this part in hand.

So the predictions below are written **first, from the geometry alone**, and they are stated so
they can be **wrong**. Each one names what would falsify it. Nobody has looked at the physical
bezel for any of these features, and I have not asked.

Geometry as printed: **front face DOWN, 0.16 mm layers** (`PRINT-SHEET.md`), 8.00 mm tall in 50
layers. Measured from `ember-front-bezel.stl` at HEAD; the bezel is byte-identical to the one JP
printed, which is why this is a fair test.

> 🔒 **P1–P6 ARE FROZEN AS WRITTEN. Nothing in them has been edited since they were first
> recorded, and nothing will be.** Their whole value is that they were fixed before anyone looked,
> and a prediction improved while waiting for the observation cannot be scored against it — even
> if the improvement is correct. *Especially* if the improvement is correct.
>
> A later realisation about P3 exists and is in **Appendix A**, dated and marked as post-hoc, so
> the original stays scoreable and the refinement is visible as a refinement rather than blended
> in. **Appendix B is the scoring procedure, also written before the data**, because deciding what
> counts as a pass after seeing the answer is the same failure as adjusting the prediction.

---

## The one number the whole day turns on

```
wyrm silhouette, EDT ridge minimum   2.4667 mm at canvas scale
mark scale s = 0.90 / 1.2333       = 0.7297
                                     -----------
narrowest recessed channel on the bezel   1.800 mm   = 4.50 nozzle widths
narrowest MATERIAL between the wyrm's own parts   2.250 mm   = 5.63 nozzle widths
```

The declared `WYRM_MIN_FEATURE = 1.2333` is a conservative bound (4 px of the source canvas). The
measured minimum is **2.00× that**, so the mark sits at twice its print floor rather than on it —
and the print floor was never what capped its size, because scaling up multiplies every feature.

**If this is right, the wyrm should be completely unremarkable to look at: crisp everywhere, with
nothing near the edge of resolution.** That is a boring prediction and it is the point — it is
falsifiable by a single smeared feature.

---

## P1 — The wyrm will be crisp everywhere. No smearing, no closed gaps, no lost tip.

**Both directions are far above resolution:** the narrowest *recess* is 1.800 mm (4.5 nozzle
widths, 0.48 mm deep) and the narrowest *material* between the creature's own parts is 2.250 mm
(5.6 widths).

**Predicted, specifically:**
- the **tail tip** is fully formed and comes to a definite point — not rounded off, not missing
- every **leg gap** is open and reads as a gap, not filled or bridged over
- the **dorsal spikes** are individually distinct, not merged into a ridge
- the **neck** is continuous with the body (it is one connected piece by assert, and the gap that
  used to exist there is gone)

**Falsified by:** any of those features smeared, filled, rounded away, or missing. If the tail tip
is soft or a leg gap has closed, **1.800 mm is optimistic and the ridge measurement is wrong about
a rasterised silhouette** — which is exactly what I want to learn, because that measurement is now
load-bearing in three places.

**Confidence: high.** 4.5 nozzle widths is not a marginal feature by any standard.

---

## P2 — The honeycomb cell corners will be visibly rounded. That is not a defect.

The thinnest material anywhere on the **visible first layer** is **0.300 mm — 0.75 nozzle widths**,
and it is at the honeycomb cell corners, where two 0.70 mm webs meet at 120°.

A 0.4 mm nozzle cannot lay 0.30 mm. **The slicer will omit it.**

**Predicted:** under a raking light, the hexagons' **corners look rounded rather than sharp**. The
cells read as soft-cornered hexagons. **The webs are continuous with no gaps anywhere** — the
omission is at the corners only, and the first layer is a single connected island (measured:
1856.7 mm², **1 island**), so nothing can be missing in a way that breaks the lattice.

**Falsified by:** sharp crisp hexagon corners (would mean the slicer resolved 0.30 mm — surprising),
or by any *gap* in a web (would mean the omission went further than the corners).

**Confidence: high** on rounded corners, **very high** on continuous webs.

---

## P3 — The webs will be *wider* than drawn, so the cells are slightly *smaller* across flats.

`BEZ_WEB = 0.70` is **1.75 nozzle widths.** That is the awkward band: too wide for one nominal
bead, too narrow for two. A modern variable-width slicer lays **one ~0.70 mm extrusion**, not two
0.40 mm lines — and this is the **first layer**, where squish spreads every bead outward.

**Predicted:** webs measure **0.75–0.90 mm** on the part, against 0.70 drawn. Cells therefore
measure **~0.10–0.20 mm smaller across flats** than the nominal 2.60 — call it **2.40–2.50 mm**.

**Falsified by:** webs measuring at or under 0.70 (would mean no squish spreading, or the slicer
under-extruding a thin feature), or cells measuring 2.60+.

**Confidence: medium.** The direction is confident; the magnitude depends on JP's flow calibration
and first-layer squish, which I cannot see.

> Note this makes P2 and P3 consistent rather than contradictory: **the cell becomes a slightly
> smaller hexagon with rounded corners.** Corners lost, flats moved inward.

---

## P4 — Deboss depth is 0.48 mm, exactly 3 layers, and feels like a crisp step.

Measured from the occupancy grid, the debossed regions close at **layer 4**:

```
layer 1 (z=0.00)  1856.7 mm2      <- the visible face, WITH the recesses open
layer 2 (z=0.16)  1859.1 mm2      +2.4
layer 3 (z=0.32)  1861.4 mm2      +2.2
layer 4 (z=0.48)  2482.3 mm2   +620.9   <- every deboss floor bridges, all at once
layer 5 (z=0.64)  2484.0 mm2      +1.7
```

`BEZEL_DEBOSS = 0.48` is **exactly 3.00 layers at 0.16 mm** — no rounding, no partial layer.

**Predicted:** the recess depth measures **0.45–0.50 mm** and feels like a **distinct crisp step**
under a fingernail, not a soft dish. The floor is at a clean layer boundary so its surface should
look like ordinary solid infill rather than a sloped or stepped transition.

**Falsified by:** a measurably deeper or shallower recess, or a floor that feels dished/tapered
rather than flat with a sharp wall.

**Confidence: high.** 3.00 layers exactly is the cleanest possible case.

---

## P5 — The deboss floors bridge, and should not sag perceptibly.

**620.9 mm² of material starts in mid-air on layer 4** — every honeycomb cell floor and the wyrm
mark's floor, simultaneously.

Spans are small: a cell is **2.60 mm across flats**, and the mark's widest run is a few mm. Sag
scales steeply with span, and 2.6 mm at 0.16 mm layers over a 0.48 mm drop is nothing.

**Predicted:** cell floors feel **flat** to a fingernail. The **mark's floor** may show very slight
sag at its widest, **under 0.1 mm**, most likely imperceptible without raking light.

**Falsified by:** visible dishing in the cell floors, or stringing/drooping visible inside the
recesses.

**Confidence: high** for the cells, **medium** for the mark's widest span.

---

## P6 — Nothing came loose. The first layer is one connected island.

**Measured: 1856.7 mm² in exactly 1 island.** Every web, every boss ring, the mic collar and the
face are one piece from layer 1.

**Predicted:** no detached fragments, nothing rattling on the bed, no islands that had to survive
on their own adhesion. Whatever else the print did, **it cannot have lost a piece of the first
layer**, because there is no separate piece to lose.

**Falsified by:** any missing fragment of the visible face.

**Confidence: very high.** This is a topological statement, not a process one.

---

## What I am NOT predicting, and why

- **Colour, layer lines, surface finish, elephant foot.** Process, not geometry.
- **Whether it looks good.** Not measurable and not mine.
- **The 3 known non-manifold edges.** Already settled empirically — it printed and the dimensions
  are good. That is an observation and it needed no prediction; recorded as one print on one
  slicer, not a claim about slicers in general.
- **Warp.** The bezel is a 5 mm plate at 1856.7 mm² of contact; there is nothing interesting to say.

---

## The ask for JP — one look, six answers

Every question below is answerable with eyes, a fingernail and a raking light. **Calipers only for
P3.** No disassembly.

| | look at | the prediction |
|---|---|---|
| **P1** | the wyrm's **tail tip, leg gaps, dorsal spikes** | crisp, open, distinct — nothing smeared |
| **P2** | a **honeycomb cell corner**, raking light | corners **rounded**, webs continuous, no gaps |
| **P3** | **web width / cell width**, calipers or loupe | webs **0.75–0.90** (drawn 0.70); cells **2.40–2.50** (drawn 2.60) |
| **P4** | **recess depth**, fingernail | ~**0.48 mm**, crisp step, flat floor |
| **P5** | **inside a cell floor** and the mark's floor | flat; mark maybe <0.1 mm sag |
| **P6** | the whole visible face | nothing missing |

**P1 is the one that matters.** It tests the measurement that three separate conclusions now rest
on. **P3 is the one most likely to be wrong**, and I would rather be scored on it than leave it
unstated.

---

## Why this is worth doing at all

Everything in `scratch/hosyond-s3/` today has been a forecast. The stand's rib, the shell's web,
the wire pass, the base plate, the countersink, the 13.2 mm bridge — **all predictions, none
scored.** A printed part is the first opportunity to find out whether these tools are calibrated
or merely self-consistent, and self-consistent is exactly what two agreeing-and-both-wrong methods
looked like earlier today.

**If P1 holds, the ridge measurement is trustworthy and `WYRM_MIN_FEATURE`'s 2× conservatism is
real.** If P1 fails, the ridge metric is optimistic about rasterised art and three write-ups need
revising — including the one that says the mark could have been larger.

---

# Appendix A — post-hoc note on P3, written after P1–P6 were fixed

**2026-07-30, after the predictions above were recorded and before any observation.** Kept
separate rather than folded into P3, so P3 stays scoreable exactly as written.

**P3 under-specified where to measure, and the omission favours me.** The deboss is 0.48 mm = 3
layers, so the honeycomb webs exist as *thin features* only on layers 1–3; above the deboss floor
the face is solid and there is no web at all. **Layer 1 is the squished one**, so it is the widest
the web ever gets and the narrowest the cell ever reads.

Calipers on the visible outer face therefore measure **layer 1 — the extreme case of P3, not its
average.** If P3's direction is right, the reading should sit at the *far* end of the 0.75–0.90
band.

**This does not change P3's numbers and must not be used to rescue them.** It sharpens the
measurement instruction, and it removes an escape route I would otherwise have had: had the
reading come back at 0.70, "you measured the wrong layer" was available to me, and it no longer
is. **Recorded because a refinement that makes a prediction easier to falsify is worth having, and
one that makes it easier to pass is not — this is the first kind, and the distinction is the whole
reason it lives down here instead of up there.**

Measurement instruction, unchanged in substance: **across a web between two adjacent cells, on the
outer face, not down inside a cell.**

---

# Appendix A2 — DISPUTED: P2's 0.300 mm, unresolved at time of writing

**2026-07-30, after the predictions were frozen and committed, and before any observation.**
**P2 is not edited. Neither measurement is declared correct here. The printed part adjudicates.**

`nebula-site` cannot reproduce the **0.300 mm** figure that P2's reasoning rests on. Three
independent checks of theirs put the narrowest material on the visible face at **0.70 mm — the
web itself**:

| their check | method | result |
|---|---|---|
| chin lattice | 2 µm raster, Euclidean distance transform, ridge minimum | **0.696 mm** |
| rail stack | same, restricted to the vertex-to-vertex pinch band | **0.704 mm** |
| both lattices | real `_bezel_cells()`, all-pairs centre distance | closest pair **3.3000 mm = nominal pitch**; zero pairs closer |

## The two bases, named

- **Mine:** the **exported STL**, ray-cast to an occupancy grid in the print orientation, **layer 0**,
  EDT ridge minimum. `px = 0.075 mm`.
- **Theirs:** the **CAD model** (`_bezel_cells()`), rasterised at **2 µm**, EDT ridge minimum, plus an
  analytic centre-distance check.

**Different objects and a 37× resolution difference**, so agreement was never guaranteed.
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

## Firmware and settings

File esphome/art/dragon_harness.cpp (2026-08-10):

// Host harness for the hearth-wyrm flame band (Lyra, 2026-07-29).
//
// Compiles the PROPOSED paint_flame body — fire + dragon — against minimal
// stubs and checks the two things that matter and that no compiler can:
//
//   1. TILING. auto_clear_enabled is false, so the framebuffer persists. Every
//      row of the flame band must be written EXACTLY once across 0..239. A gap
//      leaves permanent litter; an overlap silently doubles the write cost the
//      row-major design exists to avoid. Luna's harness asserts this for the
//      fire; the dragon composites into the same emitter, so it has to keep it.
//   2. BAND ISOLATION. Nothing may write outside y188..263.
//
// It also counts horizontal_line() calls and pixel writes per frame (the run
// count is the added-cost term I am least sure about), and dumps PPMs so the
// dragon can be judged against the REAL 60-column fire rather than a stand-in.
//
// RUN IT (from anywhere; the include is anchored to this file, not the cwd):
//
//   g++ -std=gnu++20 -O2 -Wall -Wextra -o /tmp/dh esphome/art/dragon_harness.cpp
//   /tmp/dh
//
// (Written on one line on purpose: a trailing backslash inside a // comment continues
// the comment and trips -Wcomment, so the build command would warn on the very flags
// this header tells you to use.)
//
// AND, whenever you touch array extents, loop bounds or NC/GRATE/MAXH, run it
// instrumented as well:
//
//   g++ -std=gnu++20 -O1 -g -fsanitize=address,undefined -o /tmp/dhs esphome/art/dragon_harness.cpp
//   /tmp/dhs
//
// THIS IS THE ONLY PLACE THIS CODE CAN BE INSTRUMENTED AT ALL. You cannot run ASan on
// the ESP32-S3. Because this harness is host code compiling the real paint body, the
// sanitizers apply to the actual production render loop — and that is worth more than
// the tiling check, because a stack write past an array corrupts something OUTSIDE the
// flame band, and every other check we have looks only inside it.
//
// >>> THE HOST IS MORE PROTECTIVE THAN THE DEVICE. Do not read a host pass as safety. <<<
// Worked example, NC raised 60 -> 80 (the arrays are literal [60]):
//
//   host, compile   warns  -Waggressive-loop-optimizations, no sanitizer needed
//   host, run       ABORTS  "*** stack smashing detected ***", exit 134
//   host, ASan      exact WRITE-of-size-1 trace at ch[i] = (uint8_t) hgt
//   DEVICE          SILENT. sdkconfig has CONFIG_COMPILER_STACK_CHECK_MODE_NONE=y and
//                   no -fstack-protector anywhere in the build's compile flags.
//
// Three independent signals here, zero on the target, so the asymmetry runs the wrong
// way: the thing that saves you locally is absent in the field, where the same overflow
// just quietly corrupts paint_flame's frame up to 20 times a second. Note the plain
// -Wall -Wextra build already catches this one; the sanitizer makes it precise rather
// than possible, so don't conclude you are unsafe without it.
//
// It prints, per state: runs/frame, px/frame, the dirty box, and the classify/memset/
// sqrtf/dragon-row counts, then dumps wyrm_<state>.ppm into the cwd so the result can
// be LOOKED AT rather than inferred.
//
// ---------------------------------------------------------------------------------
// WHAT THIS DOES NOT CHECK — read before trusting a pass.
//
//   * `FAIL negative-control: y=228 x=123 covered 0 times` IS EXPECTED. It is the
//     harness proving check_tiling can actually fail, and it prints on an unmodified
//     run. Do not read it as your change breaking tiling.
//
//   * check_tiling is BAND-SCOPED (y FLAM_Y .. FLAM_Y+FLAM_H-1). A change that writes
//     into the sigil, scroll or telemetry bands is not checked here at all.
//
//   * IT CANNOT CATCH AN OVER-TALL MAXH, and this is the subtle one. Fire occupies rows
//     FUSE_H .. base_row-1 where base_row = FLAM_H - GRATE. Raise MAXH past
//     base_row - FUSE_H and flames reach into the fuse — but the fuse branch
//     (`if (r < FUSE_H) { ...; continue; }`) runs BEFORE the fire logic, so the flame is
//     silently CLIPPED FLAT instead of failing. Every pixel is still covered exactly
//     once, by the fuse, so check_tiling is satisfied by the very mechanism that hides
//     the defect. Measured: with GRATE=8, MAXH=65 passes and is wrong; 64 is the
//     largest correct value. If you touch GRATE or MAXH, LOOK AT THE PPM — a flat-topped
//     tallest flame is the symptom, and no assertion in here will tell you.
//
//     Deliberately left as a documented gap rather than half-fixed: a correct assertion
//     needs GRATE/MAXH visible outside the paint body, and hoisting them would make this
//     file diverge structurally from the ESPHome lambda it mirrors, which is the whole
//     reason it is trustworthy. Worth doing properly, not quietly.
// ---------------------------------------------------------------------------------
//
// It mirrors the paint_flame body in esphome/ember-satellite.yaml. If you change one,
// change the other; the harness is only worth anything while it is the same code.

#include <algorithm>
#include <cmath>
#include <cstdint>
#include <cstdio>
#include <cstring>
#include <string>
#include <vector>

// ------------------------------------------------------------------- stubs ---
struct Color {
  uint8_t r{}, g{}, b{};
  Color() = default;
  Color(int r_, int g_, int b_) : r(r_), g(g_), b(b_) {}
};

static uint32_t g_millis = 0;
static uint32_t millis() { return g_millis; }

// Exact operation counters, declared before the stub that feeds them. The
// added cost is then ARITHMETIC against Luna's calibrated constants rather
// than a feeling about how expensive a loop looks.
static long n_classify = 0, n_memset = 0, n_sqrt = 0, n_row = 0;
static bool g_noop_emit = false;

struct Display {
  static const int W = 240, H = 320;
  uint8_t fb[H][W][3]{};
  int cover[H][W]{};
  int min_y = 9999, max_y = -1;
  long calls = 0, pixels = 0;

  void reset_counts() { min_y = 9999; max_y = -1; calls = 0; pixels = 0;
                        std::memset(cover, 0, sizeof(cover)); }
  int get_width() const { return W; }

  void horizontal_line(int x, int y, int w, Color c) {
    if (w <= 0) return;
    if (g_noop_emit) { calls++; pixels += w; return; }
    if (y < 0 || y >= H || x < 0 || x + w > W) {
      std::printf("  !! OFF-PANEL WRITE x=%d w=%d y=%d\n", x, w, y);
      std::abort();
    }
    calls++;
    pixels += w;
    min_y = std::min(min_y, y);
    max_y = std::max(max_y, y);
    for (int i = 0; i < w; i++) {
      cover[y][x + i]++;
      fb[y][x + i][0] = c.r; fb[y][x + i][1] = c.g; fb[y][x + i][2] = c.b;
    }
  }
  void filled_rectangle(int x, int y, int w, int h, Color c) {
    for (int i = 0; i < h; i++) horizontal_line(x, y + i, w, c);
  }
} it;

// globals the lambda reads (names/shapes match the YAML)
static int g_va_state = 0;
static float g_level_hist[120]{};
static int g_hist_idx = 0;
static float g_db_rms = -72.0f, g_db_peak = -72.0f;
static bool g_theme_light = false;
static uint32_t g_tts_est_ms = 0;
static int g_spark_col = -1;
static uint32_t g_spark_ms = 0;
static uint32_t g_frames = 0, g_frames_mark = 0;
static bool g_audio_live = false, g_guttering = false;
// Baseline switch: renders the fire EXACTLY as it ships, so the dragon's added
// run count is measured against the real thing rather than estimated.
static bool g_no_dragon = false;
// One tagged entry, so every harness state renders (and tiling-checks) the
// reply rune — the OFF case is the pre-rune painter, already proven.
static std::vector<std::string> g_chron_chan = {"C0EMBER"};
// Mirrors the firmware's `silenced` = (st == 3) && op_mode >= 1. Default false, so every
// recorded runs/frame figure is unchanged by its introduction — verified, not assumed.
// The `silenced` scenario sets it (added with #10's coverage guard, c36c585); before
// that it existed only so the harness compiled the SHIPPED painter rather than one
// missing a line, and no scenario exercised it.
//
// ⚠️ THE EXPLANATION LIVES HERE AND NOT AT THE USE SITE, AND THE GENERATOR IS WHY.
// make_paste_block.py aborts if any `g_*` symbol survives into the extracted body, and
// its leftover scan is textual — so a COMMENT naming this global is enough to trip it.
// That refusal is correct rather than pedantic: the extracted body is pasted into the
// YAML, where `g_silenced` does not exist, so a comment referencing it would ship as a
// dangling pointer. Below the marker, use the `silenced` alias and never name this.
static bool g_silenced = false;
static bool g_wake_reset = false;
static void wake_reset() { g_wake_reset = true; }

// ------------------------------------------------------------- the lambda ---
// Everything from here to END-OF-LAMBDA is the block that goes in the YAML,
// modulo id(...) -> g_... and the ${subst} numbers being spelled out.

static const int W_ = 240;
static const int FLAM_Y = 188, FLAM_H = 76;
static const int FUSE_H = 4;

static void paint_flame_frame() {
  const int W = it.get_width();
  const uint32_t now = millis();

  Color c_bg, c_ink, c_dim, c_ash, c_bed, c_ember, c_amber, c_gold, c_tip, c_alarm;
  if (g_theme_light) {
    c_bg = Color(0xF2, 0xE8, 0xDA); c_ink = Color(0x2A, 0x1C, 0x12);
    c_dim = Color(0x8A, 0x76, 0x62); c_ash = Color(0xD8, 0xCA, 0xB8);
    c_bed = Color(0x8C, 0x2E, 0x0A); c_ember = Color(0xB8, 0x3A, 0x0C);
    c_amber = Color(0xE0, 0x6A, 0x10); c_gold = Color(0xF0, 0xA8, 0x20);
    c_tip = Color(0xFF, 0xE0, 0x90); c_alarm = Color(0xA8, 0x14, 0x10);
  } else {
    c_bg = Color(0x0A, 0x06, 0x04); c_ink = Color(0xF2, 0xDC, 0xB8);
    c_dim = Color(0x6A, 0x52, 0x40); c_ash = Color(0x3A, 0x32, 0x2C);
    c_bed = Color(0x4A, 0x10, 0x02); c_ember = Color(0x8E, 0x22, 0x06);
    c_amber = Color(0xE0, 0x5A, 0x08); c_gold = Color(0xFF, 0xA8, 0x1E);
    c_tip = Color(0xFF, 0xE8, 0xB4); c_alarm = Color(0xFF, 0x3C, 0x18);
  }
  (void) c_ink; (void) c_dim;

  const int st = g_va_state;
  const bool guttering = g_guttering;
  // Same convention as `guttering`: the alias is declared HERE, above the
  // THE HEARTH-WYRM marker, so the extracted body reads the firmware's spelling and the
  // generator needs no mapping entry. Mirrors `silenced = (st == 3) && op_mode >= 1`.
  const bool silenced = g_silenced;
  const uint32_t frames = g_frames;
  const uint32_t spoken_ms = (frames - g_frames_mark) / 16u;
  float prog = 0.0f;
  if (g_tts_est_ms > 0) {
    prog = (float) spoken_ms / (float) g_tts_est_ms;
    if (prog > 0.97f) prog = 0.97f;
  }
  const float ph = (float) spoken_ms * (6.28318f / 900.0f);

  float spark_k = 0.0f;
  if (g_spark_col >= 0) {
    const uint32_t age = now - g_spark_ms;
    if (age < 500u) { const float t = 1.0f - (float) age / 500.0f; spark_k = t * t; }
  }

  auto db_to_frac = [&](float db) {
    float f = (db - -72.0f) / (-30.0f - -72.0f);
    return f < 0.0f ? 0.0f : (f > 1.0f ? 1.0f : f);
  };

  // ---- animation smoothers. These MUST be declared before paint_flame in the
  // real lambda (a lambda body cannot name a variable declared after it), which
  // is why they do not live with the scheduler statics further down. ----
  static float wake_s = 0.0f;
  static float lvl_s = 0.0f;
  if (g_wake_reset) { wake_s = 0.0f; lvl_s = 0.0f; g_wake_reset = false; }

  // =====================  THE HEARTH-WYRM  =====================
// Same directory as this file. A quoted include resolves relative to the INCLUDING
// FILE, so this works from any cwd and survives the repo being cloned anywhere. It
// previously read ../../../../../Projects/ha/esphome/art/dragon_spans.inc — a path from
// before this project was extracted out of ~/Projects/ha — so the harness did not
// compile at all from a clone. Keep it relative to the file, never to the cwd.
#include "dragon_spans.inc"

  // Geometry. DGN_X/Y/W/H MUST agree with the dgn_ substitutions the touch
  // hit-test uses, or "where it's drawn" and "where it's tappable" drift apart.
  //
  // TRAP: do NOT write a substitution token inside a comment in this block. The
  // lambda is run through ESPHome's substitution pass before it is ever C++, so
  // a dollar-brace in a COMMENT is still expanded — and a wildcard one is a
  // TemplateSyntaxError pointing at the whole 400-line lambda, which tells you
  // nothing about where it is. Cost me one confusing validation failure.
  // Three mouth shapes, indexed by `jaw`. Indexing rather than branching keeps
  // the row builder a single loop, and it is what makes the unused-variable
  // warning the check that the variants are actually wired up.
  const uint8_t *HB[3]  = {HED_B0, HED_B1, HED_B2};
  const int      HBN[3] = {HED_B0_N, HED_B1_N, HED_B2_N};
  const uint8_t *HD[3]  = {HED_D0, HED_D1, HED_D2};
  const int      HDN[3] = {HED_D0_N, HED_D1_N, HED_D2_N};
  const uint8_t *HM[3]  = {HED_M0, HED_M1, HED_M2};
  const int      HMN[3] = {HED_M0_N, HED_M1_N, HED_M2_N};
  const uint8_t *HT[3]  = {HED_T0, HED_T1, HED_T2};
  const uint8_t *HY[3]  = {HED_Y0, HED_Y1, HED_Y2};

  const int DGN_X = 60, DGN_Y = 22, DGN_W = 120, DGN_H = 50;
  const int HED_W = 28, HED_H = 19;
  const int HED_ATX = 21, HED_ATY = 13;      // neck attach, head-local
  const int HED_EYX = 8,  HED_EYY = 7;       // eye centre, head-local
  const int SHX = 29, SHY = 28;              // shoulder, dragon-local
  const int HSX = 4, HSY = 30;               // head pos asleep
  const int HAX = 0, HAY = 0;                // head pos alert
  // The "stage" is the dragon plus 16px of clear air in front of its muzzle, so
  // the breath sparks have somewhere to go. Only the dragon's own 120 columns
  // are ever occluded; the extra 24 hold sparks and nothing else.
  const int STG_X = DGN_X - 16, STG_W = DGN_W + 24;
  const int DOFF = DGN_X - STG_X;            // dragon-local x -> stage x
  // Rows at or below this are IN the coals: tall flames are drawn in FRONT of
  // the dragon there, so its feet dissolve into the fire instead of sitting on
  // a hard line. This is the one place the fire wins the depth test.
  const int SUBMERGE_R = FLAM_H - 11;
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
int main() {
  struct Case { const char *name; int st; bool live, gut; int hit; };
  const Case cases[] = {
      {"idle",       0, false, false, -1},
      {"listening",  1, false, false, -1},
      // wake pinned to 1.0 and to 0.0: the head lift is the only thing that
      // moves geometry, so the band-isolation proof has to cover both ends.
      {"listen-loud",1, false, false, -1},
      {"thinking",   2, false, false, -1},
      {"speaking",   3, true,  false, -1},
      {"guttering",  3, true,  true,  -1},
      {"error",      4, false, false, -1},
      {"tap",        0, false, false,  0},
      {"daylight",   3, true,  false, -1},
      // #10's marshalling guard: the five fields below were pinned across all nine
      // scenarios above, so the runs/frame acceptance test could not distinguish a
      // correct marshalling of any of them from a dropped one.
      //
      // ONE FIELD PER SCENARIO, so a failure NAMES the field rather than a combination
      // -- recovered from a parallel (killed) session's uncommitted work in
      // ember-wt-chamfer, which measured the same five blind fields independently and
      // separated them better than the first committed version here did.
      //
      // Each must sit at the state where its field reaches geometry, or it satisfies a
      // coverage counter while leaving the numbers blind: the history ring and the wake
      // smoother are read on the listening branch (st 1); `silenced` only through
      // `if (silenced) jaw = 0` on the speaking jaw; frames_mark only while a TTS
      // estimate runs (st 3, live).
      {"hist-rotated", 1, false, false, -1},   // g_hist_idx = 57, standard fill
      {"wave-alt",     1, false, false, -1},   // cos fill, g_hist_idx = 0
      {"wake-reset",   1, false, false, -1},   // g_wake_reset: zeroes wake_s/lvl_s
      {"silenced",     3, true,  false, -1},   // g_silenced
      {"mid-speech",   3, true,  false, -1},   // g_frames_mark = 24000
  };

  for (int c = 0; c < (int) (sizeof(cases) / sizeof(cases[0])); c++) {
    const Case &k = cases[c];
    g_theme_light = (std::string(k.name) == "daylight");
    g_va_state = k.st;
    g_audio_live = k.live;
    g_guttering = k.gut;
    g_tts_est_ms = k.live ? 4200 : 0;
    g_silenced = (std::string(k.name) == "silenced");
    // Non-zero for one scenario so the acceptance test can see this field at all: it is
    // subtracted from `frames` to make spoken_ms, so at 0 everywhere a dropped
    // marshalling of it is arithmetically invisible.
    g_frames_mark = (std::string(k.name) == "mid-speech") ? 24000u : 0u;
    g_spark_col = (k.hit >= 0) ? (k.hit ? 30 : 5) : -1;
    g_hist_idx = (std::string(k.name) == "hist-rotated") ? 57 : 0;
    g_wake_reset = (std::string(k.name) == "wake-reset");
    const bool alt = (std::string(k.name) == "wave-alt");
    for (int i = 0; i < 120; i++)
      g_level_hist[i] = alt ? 0.15f + 0.70f * fabsf(cosf((float) i * 0.37f))
                            : 0.25f + 0.60f * fabsf(sinf((float) i * 0.21f));
    const bool loud = (std::string(k.name) == "listen-loud");
    g_db_rms = loud ? -12.0f : -40.0f;
    g_db_peak = loud ? -12.0f : -34.0f;

    long calls = 0, px = 0;
    int frames_ok = 0;
    n_classify = n_memset = n_sqrt = n_row = 0;
    // 60 frames at 50ms: enough for the head to finish settling and for the
    // syllable envelope and the breath to cycle several times.
    for (int fr = 0; fr < 60; fr++) {
      g_millis = 100000u + (uint32_t) fr * 50u;
      g_frames = k.live ? (uint32_t) fr * 800u : 0u;
      g_spark_ms = (k.hit >= 0) ? g_millis - (uint32_t) (fr % 10) * 50u : 0u;
      it.reset_counts();
      paint_flame_frame();
      if (check_tiling(k.name)) frames_ok++;
      else break;
      calls += it.calls;
      px += it.pixels;
    }
    if (frames_ok == 60) {
      std::printf("  %-11s 60 frames  tiling ok  box y%d..%d  runs/frame %4ld  px/frame %ld\n",
                  k.name, it.min_y, it.max_y, calls / 60, px / 60);
      std::printf("               per frame: classify %ld  memset %ldB  sqrtf %ld  dragon rows %ld\n",
                  n_classify / 60, n_memset / 60, n_sqrt / 60, n_row / 60);
    }
    char path[128];
    std::snprintf(path, sizeof(path), "wyrm_%s.ppm", k.name);
    dump(path, 1);

    // the same state with the dragon switched off — the honest delta
    g_no_dragon = true;
    long b_calls = 0;
    for (int fr = 0; fr < 60; fr++) {
      g_millis = 100000u + (uint32_t) fr * 50u;
      g_frames = k.live ? (uint32_t) fr * 800u : 0u;
      it.reset_counts();
      paint_flame_frame();
      b_calls += it.calls;
    }
    g_no_dragon = false;
    std::printf("               fire alone %4ld runs -> +%ld runs (+%.0f%%)\n",
                b_calls / 60, calls / 60 - b_calls / 60,
                100.0 * (double) (calls / 60 - b_calls / 60) / (double) (b_calls / 60));
  }

  // ---- motion strips. A still cannot show whether the startle reads as a
  // creature waking or as a light turning on, and that is the whole gesture. ----
  struct Strip { const char *name; int st; bool live; int hit; int step; };
  const Strip strips[] = {
      {"startle",        0, false, 0, 50},
      {"speak-cycle",    3, true, -1, 50},
  };
  for (const Strip &sp : strips) {
    g_theme_light = false; g_va_state = sp.st; g_guttering = false;
    g_tts_est_ms = sp.live ? 4200 : 0; g_frames_mark = 0;
    g_db_rms = -40.0f; g_db_peak = -34.0f;
    wake_reset();
    const int N = 10;
    static uint8_t strip[76 * 10][240][3];
    for (int fr = 0; fr < N; fr++) {
      g_millis = 200000u + (uint32_t) fr * (uint32_t) sp.step;
      g_frames = sp.live ? (uint32_t) fr * 1400u : 0u;
      if (sp.hit >= 0) { g_spark_col = 30; g_spark_ms = 200000u; }
      else { g_spark_col = -1; }
      it.reset_counts();
      paint_flame_frame();
      check_tiling(sp.name);
      std::memcpy(&strip[fr * 76][0][0], &it.fb[FLAM_Y][0][0], (size_t) 240 * 76 * 3);
    }
    char path[128];
    std::snprintf(path, sizeof(path), "wyrm_strip_%s.ppm", sp.name);
    FILE *f = fopen(path, "wb");
    std::fprintf(f, "P6\n240 %d\n255\n", 76 * N);
    fwrite(strip, 1, sizeof(uint8_t) * 240 * 76 * (size_t) N * 3, f);
    fclose(f);
    std::printf("  strip %-16s %d frames  ok\n", sp.name, N);
  }

  // A negative control on the tiling check itself: if it cannot fail, it is not
  // testing anything. Deliberately drop one pixel and confirm it is caught.
  {
    g_va_state = 1; g_guttering = false; g_theme_light = false;
    g_spark_col = -1; g_millis = 100000; g_frames = 0;
    it.reset_counts();
    paint_flame_frame();
    it.cover[FLAM_Y + 40][123] = 0;
    const int before = g_fail;
    check_tiling("negative-control");
    if (g_fail == before) {
      std::printf("  FAIL: the tiling check did not notice a missing pixel\n");
      g_fail++;
    } else {
      std::printf("  negative control  caught the hole  ok\n");
      g_fail = before;   // expected failure, not a real one
    }
  }

  std::printf(g_fail ? "\n  %d CHECK(S) FAILED\n" : "\n  ALL CHECKS PASSED\n", g_fail);
  return g_fail ? 1 : 0;
}

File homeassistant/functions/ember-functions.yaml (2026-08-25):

# Ember's tool definitions — the source of truth for the conversation subentry's
# `functions` field.
#
# WHERE THIS ACTUALLY LIVES: not in any YAML file Home Assistant reads. It is a
# YAML *string* stored inside HA's `.storage`, in the Extended OpenAI
# Conversation subentry, exactly like the system prompt. Deploy it with
#
#     homeassistant/tools/ember-toolkit.py --deploy
#
# which drives the same config-subentry reconfigure flow ember-prompt.py uses:
# live, no HA restart. Committing this file changes nothing on its own.
#
# The deploy REPLACES the field wholesale, so this file must always contain the
# complete list — the stock four included. Dropping `execute_services` would
# silently disable Ember's ability to control the house.
- spec:
    name: execute_services
    description: Execute service in Home Assistant.
    parameters:
      type: object
      properties:
        delay:
          type: object
          description: Time to wait before execution
          properties:
            hours:
              type: integer
              minimum: 0
            minutes:
              type: integer
              minimum: 0
            seconds:
              type: integer
              minimum: 0
        list:
          type: array
          items:
            type: object
            properties:
              domain:
                type: string
                description: The domain of the service.
              service:
                type: string
                description: The service to be called
              service_data:
                type: object
                description: The service data object to indicate what to control.
                properties:
                  entity_id:
                    type: array
                    items:
                      type: string
                      description: The entity_id retrieved from available devices.
                        It must start with domain, followed by dot character.
                  area_id:
                    type: array
                    items:
                      type: string
                      description: The id retrieved from areas. You can specify only
                        area_id without entity_id to act on all entities in that area
            required:
            - domain
            - service
            - service_data
  function:
    type: native
    name: execute_service
- spec:
    name: get_attributes
    description: Get attributes of entity or multiple entities.
    parameters:
      type: object
      properties:
        entity_id:
          type: array
          description: entity_id of entity or multiple entities
          items:
            type: string
      required:
      - entity_id
  function:
    type: template
    value_template: '```csv

      entity,attributes

      {%for entity in entity_id%}

      {{entity}},{{states[entity].attributes}}

      {%endfor%}

      ```'
- spec:
    name: load_skill
    description: Load a file from a skill's directory.
    parameters:
      type: object
      properties:
        name:
          type: string
          description: Skill name
        file:
          type: string
          description: Relative file path within the skill directory
      required:
      - name
      - file
  function:
    type: read_file
    path: '{{extended_openai.skill_dir(name)}}/{{file}}'
- spec:
    name: bash
    description: Execute a bash command in workspace.
    parameters:
      type: object
      properties:
        command:
          type: string
          description: Bash command to execute
      required:
      - command
  function:
    type: bash
    command: '{{command}}'

# ─── Ember toolkit, added 2026-08-02 ─────────────────────────────────────────
# Everything above this line is the integration's stock set and is deployed
# verbatim; everything below is this repo's.
#
# House style for these tools: a tool returns FACTS as `key=value`, not a
# finished sentence. Ember has a voice — plain prose, British, one sentence —
# and it is defined in the system prompt, not here. A tool that returns polished
# prose fights the persona and wins, which is how a hearth-spirit ends up saying
# "state=Printing; percent=60".
#
# Nothing here may hold a credential: this list lives in HA's `.storage` and is
# parsed with plain `yaml.safe_load`, which does not understand `!secret`.
# Secret-bearing calls go through packages/ember_toolkit.yaml instead.
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

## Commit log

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2026-07-30 fix(enclosure): the real speaker is a taped 40x27 rectangle, and its wires had no exit
    Two corrections from JP looking at the actual hardware. Both invalidate
    assumptions the model could not have caught, and one of them was a hole
    in the design rather than a wrong dimension.
    1. THE DRIVER IS RECTANGULAR AND ADHESIVE-MOUNTED.
    Cut for a round ⌀28 flanged driver seated in a ⌀29 x 2.2mm recess. It is
    actually a 40 x 27mm rounded rectangle held on with sticky tape, which
    inverts two requirements:
    - The grille field becomes rectangular. Slots are now clipped to a
    37 x 24 rounded rect (GRILLE_INSET 1.5mm inside the driver outline) so
    the grille never opens onto the frame — an open slot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
    [ember-stand.stl]
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2026-07-30 fix(enclosure): it is a sealed-back module with tape on the BACK — third revision
    Three corrections to the speaker mount, each from JP looking at the actual
    part. Recording all three because the sequence is the lesson: every one
    was a confident design built on an assumption the model could not test.
    WHAT IT ACTUALLY IS: a sealed-back MODULE, not a bare driver. A plastic
    box carrying its own rear cavity, diaphragm on one face, JST-1.25 pigtail,
    double-sided tape on the back. 40 x 27mm footprint, 10mm thick (measured).
    1. Cut for a round ⌀28 flanged driver in a ⌀29 x 2.2mm recess. WRONG.
    2. Made it a 40 x 27 rectangle, dropped the recess for a shallow lip on
    the baffle. ALSO WRONG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
    [ember-stand.stl]
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2026-07-30 fix(enclosure): the stand was covering the bottom fifth of the screen
    JP spotted it in a render. Two faults, one cause: the slab sat too deep.
    THE SCREEN. The slot floor was z=10.0, putting the stand 30mm up the slab
    — 31.1mm ALONG it once the 15 degree tilt is accounted for
    (30 / cos 15). The visible area starts only 19.76mm up from the slab's
    bottom edge (VA y0 = 16.81, slab bottom OY0 = -2.95), so the stand
    covered 11.3mm of screen: 19.5% of a 58.05mm display, hidden behind the
    box.
    Worth naming the class: NOTHING INTERSECTED. The boolean clearance check
    against the vendor STEP passed at 0.000mm3 through every revision,
    correctly, because the stand was not colliding with the screen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
    [ember-stand.stl]
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2026-07-30 feat(enclosure): make it buildable from a fresh clone, and close the motif loop
    Two gaps the handoff flagged.
    1. THE TOOLCHAIN WAS UNREPRODUCIBLE. ember_case.py is the artifact and the
    STLs are output — but the venv and the render scripts lived only in a
    scratch directory, so a fresh clone could not rebuild either. Landed
    tools/make_renders.py, tools/check_and_render.py and a pinned
    requirements.txt (the exact set the shipped STLs were built with), plus a
    README explaining setup, the vendor STEP download, and what the two kinds
    of check actually do.
    Recorded there because it is the most reusable thing in this directory:
    the boolean clearance check once returned a confident CLEAR that mea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
    [check_and_render.py, make_renders.py]
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2026-07-30 feat(enclosure): the grille is the wyrm's dorsal ridge, re-derived to cost no acoustics
    JP asked why the motif hadn't landed. Two answers, and my recorded one
    was wrong.
    THE COMMENT WAS WRONG. ember_case.py deferred the motif on the grounds
    that "changing open area while validating fit would confound two
    variables". That does not hold: fit is validated by the bezel and shell
    against the board, and the stand's grille pattern is independent of it.
    Replaced with the actual obstacle.
    THE ACTUAL OBSTACLE WAS ARITHMETIC:
    lyra's motif as delivered: 11 spines, 50 x 15 field, 190 mm2 open
    this grille needs: 37 x 24 field, ~673 mm2 open
    Her motif was sized for the geometry that exist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
    [ember-stand.stl]
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2026-07-30 feat(enclosure): hexagonal grille, and a USB-C well that follows the slab
    Two things, and JP's question about plug clearance found a real bug.
    THE WELL WAS WRONG. It was cut as a flat box down to z = SLOT_FLOOR. The
    slot is a box rotated by TILT with align=MIN, so ITS BOTTOM FACE TILTS
    TOO — front-bottom corner at z ~= 26.4, rear-bottom at ~21.6. A flat well
    therefore left a wedge of material exactly where the plug emerges.
    The earlier "20mm of clearance" was measured by point-sampling the
    CENTRELINE, which is the one place that discrepancy vanishes. A plug has
    width, and its front corner hit the wedge. Measured properly, by sweeping
    a plug-shaped box down the insertion axis and checking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
    [ember-stand.stl]
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2026-07-30 feat(enclosure): fine hex back; LED window, diffuser seat and diffuser part all deleted
    Four parts now, not five.
    The back shell's two 6-slot vent arrays are replaced by a fine hexagonal
    field — 3.2mm across the flats on a 0.8mm web, patch x 9..41 / y 11..75.
    The bounds are set by what is already in that face rather than by taste:
    x clears the screw bosses (holes on 78x42 centres 4mm in from each edge,
    so a boss at x=4 spans 1.3..6.7 and at x=46, 43.3..48.7); y clears the
    printed-in-place button pads at y~3.3, the USB-C relief below them, the
    mic relief at (40, 81.5), and the PCB antenna keepout at y 80.04..85.70.
    The old slot vents dodged the same features. Every hex is kept WHOLLY
    insid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
    [ember-back-shell.stl, ember-diffuser.stl]
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2026-07-30 feat(art): land the flame-band harness in the repo, where it compiles
    It is the only tool that can falsify a render-loop change before flashing, and
    it lived in scratch with an include pointing at
    ../../../../../Projects/ha/esphome/art/dragon_spans.inc — a path from before
    this project was extracted out of ~/Projects/ha. So it did not compile at all
    from a clone. Same defect class as the bare `import wyrm_spans` and the
    cwd-relative STEP path in ember_case.py, and the same fix: anchor to the file,
    never to the cwd. It now sits next to dragon_spans.inc and includes it by bare
    name, which resolves relative to the including file from any working directory.
    Verified by building from an unrela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
    [dragon_harness.cpp]
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2026-07-30 feat(site): draw the two pads as the different things they are
    One combined `btn` group drew BOOT and RESET identically, which visually asserts
    they are the same kind of thing. They are not: BOOT is GPIO0 and the entire
    usable hardware input, RESET is hardwired to CHIP_PU and firmware cannot read it
    at all. Now one group per switch — case-back-btn-boot-vis and
    case-back-btn-reset-vis — drawn at different weights, with BOOT heavier.
    The ids and the caption key off IDENTITY, never position, and that is the whole
    point rather than a stylistic preference. The apparent side flips between
    figures: this view looks from behind so board +X lands on the viewer's LEFT, and
    the print-layout figure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
    [make_renders.py]
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2026-07-30 fix(display): make an over-tall MAXH a compile error instead of a silent clip
    Flames rise from base_row, so the tallest reaches base_row-MAXH. Rows below
    FUSE_H belong to the progress fuse, painted by an EARLIER branch that continues.
    So an over-tall MAXH never overflows the band and never fails anything: the fire
    is silently CLIPPED FLAT against the fuse and you get square-topped tallest
    flames on the device with nothing said.
    The host harness could not catch it either, and that is the point. Its write-once
    check still passes, because every pixel really is covered exactly once — by the
    fuse. The invariant is satisfied by the very mechanism that conceals the defect,
    so a green harness run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
    [dragon_harness.cpp]
2026-07-30 fix(enclosure): the stand was standing on a ring
    morpheus-battery found it while measuring free space for a cell, which is
    the second time a battery investigation has produced a defect fix rather
    than a battery.
    The USB-C well was cut 30mm down the tilted slab axis. Its far end reached
    z = -4.98 — straight THROUGH the 4mm floor — leaving a 273mm2 hole in the
    underside and a bearing footprint of 2911 of 4010mm2.
    Nothing caught it, and the reason is this project's recurring pattern: the
    boolean clearance check compares each part to the BOARD, and a hole in the
    floor intersects nothing whatsoever. An absence cannot collide. Same family
    as the stand occluding the screen and the buttons bei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
    [ember-stand.stl]
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2026-07-30 docs(art): the CW warning is not cosmetic — I filed a true compiler report wrong
    My own comment said -Wunused-variable on CW was expected noise, kept only so the
    harness would not diverge from the lambda. The divergence reasoning was right.
    Calling the warning cosmetic was wrong, and the compiler was telling the truth.
    CW is unused because the column index is `x >> 2`, which hardcodes CW == 4. The
    arrays are fixed [60] and filled `for (i < NC)`, while the read index runs 0..59
    for any NC. So the operator advice at ember-satellite.yaml:1922 — "if audio
    hiccups during a conversation, the knobs in preference order are: FLAM_H 76->60,
    then the flame tick 50->70ms, then NC 60->40 with CW 4->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
    [dragon_harness.cpp]
2026-07-30 fix(enclosure): the hex grille was ONE hole with 43 loose prisms in it
    luna-bezel found this while building the bezel face, and it is the worst
    defect this project has produced: a part that would have been printed.
    `RegularPolygon(R, 6)` is FLAT-top — two vertices share the maximum Y, so
    the cell measures 2R across-corners in X and R*sqrt(3) across-flats in Y.
    Both lattices here space columns at `dx = aflat + web`, which is POINTY-top
    spacing where across-flats is the X extent. Drawn flat-top, each cell is
    7.500mm wide against a 7.395mm pitch. The cells overlap. The web is
    negative.
    As built:
    stand grille _hex_field(15.0).solids() -> 1 SOLID, not 33
    flood-fill: 44 disc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
    [ember-back-shell.stl, ember-stand.stl]
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2026-07-30 docs(art): document the sanitizer run, and that the host is safer than the device
    The harness is the only place this code can be instrumented at all — you cannot
    run ASan on an ESP32-S3, and because this is host code compiling the real paint
    body, the sanitizers apply to the actual production render loop. That matters
    more than the tiling check for one class of bug: a stack write past an array
    corrupts something OUTSIDE the flame band, and every other check here looks only
    inside it.
    Header now documents the -fsanitize=address,undefined invocation alongside
    -Wall -Wextra, verified against unmodified source: exit 0, no findings, ALL
    CHECKS PASSED. So it is a working command and a clean bas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
    [dragon_harness.cpp]
2026-07-30 feat(enclosure): hexagonal button caps, debossed rather than raised
    JP: "i wanted the buttons to be hexagons not squares". They were rectangles
    in the solid AND hand-drawn as rectangles a second time in make_renders.py,
    which is the more interesting half of this: the figure carried its own copy
    of the outline, so the part and the picture were free to disagree forever
    and nothing would notice. They agreed only because both happened to be
    rectangles. The figure is the only thing anyone looks at, so it would have
    kept drawing squares over a hexagonal case indefinitely. Both now read
    cap_geometry() and cap_hex_pts(), so a figure can no longer describe a
    button the case does not have.
    FLAT-TOP,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
    [ember-back-shell.stl]
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2026-07-30 fix(enclosure): export the wyrm's min feature and component count — the assert was arithmetic
    `_bezel_mark()` hardcodes `s = 0.90/1.23` and returns `1.23 * s`, then asserts the result
    is >= 0.90. That identity holds for ANY hardcoded value: 0.95 or 0.10 in place of 1.23
    still returns exactly 0.9000 and still passes. The assert cannot fail. The 1.23 was a
    transcription of a COMMENT — wyrm_spans.py exported only WYRM, WYRM_AREA, WYRM_W, WYRM_H,
    so re-running the generator with a different dilation would change the real minimum feature
    and leave the constant, the scale and the assert all agreeing with each other and with
    nothing else. Same shape as the run where `75 >= 60` passed with the r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
    [make_wyrm_spans.py]
2026-07-30 docs: wire the docked-rear figure in, and delete four sentences that stopped being true
    The site said the button pads were "as drawn, completely unreachable", that a
    redesign flipping the hinge to the bottom was "in progress", and that until it
    landed the figure "shows a control that does not work". None of that is true
    any more -- the stand carries a finger scallop over each cap and the fingertip
    probe assert passes -- and a caveat left in place after its cause is gone is the
    same defect as a missing caveat, just pointing the other way. The pads also go
    back to an accent from --alarm/dashed, which the CSS comment itself said should
    happen "when the geometry is actually fixed".
    case-docked-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
    [make_renders.py]
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2026-07-30 feat(enclosure): finger scallops, bezel motif, per-button hinge flexure
    Three changes and one new figure, all driven by faults found by looking at
    the thing rather than reading the source.
    FINGER SCALLOPS IN THE STAND'S REAR SLOT WALL. JP asked whether the new hex
    caps were tall enough and suggested a tab to raise them. The instinct was
    right and the cause was worse than height: the stand swallows the first
    16.56mm of the slab and both switches sit 3.26mm from the board's bottom
    edge, so BOTH caps were entirely inside the slot — BOOT's top edge 3.81mm
    below the rim, RESET's 6.23mm — with 0.40mm of slot clearance between the cap
    face and solid wall. A finger does not fit in 0.40mm, so a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
    [ember-back-shell.stl, ember-front-bezel.stl, ember-stand.stl]
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2026-07-30 fix(enclosure): the wyrm had no neck, and its head was never posed
    THE MARK WAS TWO PIECES. `make_wyrm_spans.silhouette()` was `body_mask() | head_mask(0)`,
    which left the silhouette in two components 1.660mm apart — 1.215mm once scaled onto the
    bezel, far above any print floor, so it printed as a body with a blob floating above the
    shoulders. Two causes, both things the one-liner omitted:
    1. head_mask() returns the head SPRITE IN ITS OWN FRAME at dragon-local (0,0), bbox
    x0..26 y0..13. It is not posed. The device translates it by HEAD_POS_SLEEP..ALERT
    interpolated on wakefulness, so unioning it raw put the head in neither pose and
    nowhere near SHOULDER.
    2. dragon.py dr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
    [make_wyrm_spans.py]
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2026-07-30 feat(enclosure): thumb-sized caps, the mirrored wyrm, and a mesh check that can fail
    THUMB-SIZED CAPS, AND THE STRENGTH ARGUMENT DECIDED IT. JP asked for "big
    thumbsized hexagons" and 9.01mm across flats is not one. But the reason to do
    it is strain: at 9.01mm the hinge sat 6.55mm from the pip, giving 3.50deg and
    2.29% at L=1.20 — over PLA's ~2% YIELD, safe only against fracture. A bigger
    hex puts the hinge further from the pip, so theta falls with it. BOOT is now
    15.00mm across flats and RESET 10.00, both at ~1.20%. The cap JP wanted is the
    cap that stops the hinge creeping.
    So the strain assert tightened 2.5% -> 2.0%. The old threshold was calibrated
    to what 9mm caps could achieve, not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
    [ember-back-shell.stl, ember-front-bezel.stl, ember-stand.stl]
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2026-07-31 test(firmware): make the restore/resync bug a rule instead of a fixed instance
    `TemplateNumber::setup()` calls publish_state() and never control(), so a
    restore_value control comes back after a reboot showing its stored value while
    its set_action — the thing that writes the hardware — never ran. The entity and
    the device disagree, and the entity is the one people read.
    That was diagnosed for spk_volume, fixed with an on_boot resync, and written up
    in a comment carrying the exact source line numbers. Then mic_gain_num was added
    and shipped with the identical defect. The documentation was sitting 700 lines
    above the new bug and did not prevent it, because a note saying "this component
    beh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
    [check_restore_resync.py]
2026-07-31 fix(enclosure): the tape pad blocked 92% of the speaker-wire pass
    The sealed chamber had no usable wire exit. `p += pad` fills y 18.50..19.30 and the
    pass was cut from y=19.0 — 0.50mm BEHIND the pad's inner face — so the pad survived
    as a 0.474mm membrane across the whole mouth: the thinnest feature in the part, 12.4mm3
    over 23 layers, leaving a clear aperture of 2.37 of 30mm2 (7.9%), one 5.92 x 0.40mm slit.
    A 2-core lead is 1.2-2.0mm. It did not fit.
    This is JP's own catch ("the chamber had no exit at all") reintroduced by a feature added
    129 lines away, and the pad's comment claimed its purpose was an uninterrupted bond surface
    while 6.0 x 4.6mm of it was a membrane over a hole. Comme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
    [ember-stand.stl]
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2026-07-31 fix(enclosure): six stale comments, the grille's real open area, and a metric that reported the fattest point
    COMMENT-ONLY for the geometry: all four STLs are byte-identical, mesh check unchanged
    (bezel 3 non-manifold known 3, others watertight, boundary 0), clearance 0.000mm3 with the
    self-test at 1467.842mm3.
    OPEN AREA, re-derived on the field that is actually there, since GRILLE_FLARE merges the
    mouth on purpose and the 673.0mm2 solve assumed separate cells. Rastered in the X-Z plane
    at 0.01mm, which IS the aperture plane because the bores run in Y:
    THROAT un-flared cells & field 678.0 mm2 27 openings <- the acoustic restriction
    MOUTH flared cells & field 886.1 mm2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
    [make_wyrm_spans.py, minfeature.py]
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2026-07-31 fix(enclosure): the base plate was 1.40mm too big for the hole it closes
    ⛔ ember-stand-base.stl could not be assembled. Measured by boolean, not inferred:
    stand_base bbox x 5.30..58.70 y 4.30..20.70 z 0.40..4.00
    chamber bottom opening x 5.00..59.00 y 4.00..19.30 z -1.00..4.00
    base & stand 269.136 mm3 of interference, over y 19.30..20.70
    The plate is LARGER THAN THE HOLE IT CLOSES, so the sealed speaker chamber could not be
    closed. It would have been found by hand, with three parts already assembled and the driver
    already taped — the one point in the sequence where a reprint costs the most.
    THE CAUSE, EXACTLY. The plate's `20.7` is 21.00 - 0.30: the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
    [ember-stand-base.stl]
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2026-07-31 fix(enclosure): the countersink was cut for no screw that exists — name the head, not the angle
    The cone was `cone(..., BACK_Z+1.70, 6.40, SCREW_D)`, an included angle of
    2*atan(1.55/1.70) = 84.75deg against a standard 90deg flat head. A head STEEPER than its hole
    never touches the flanks: it bears on a LINE — its own top rim against the cone — instead of on
    the full conical seat. Several times the intended contact stress, on a fastener a person
    torques by feel, and the crater lands on the VISIBLE back face.
    ⚠️ AND "MAKE THE ANGLE 90deg" IS NOT THE FIX. My own audit recommended widening the mouth to
    6.70 to reach 90deg. That is WORSE, and computing the seat instead of the angle sa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
    [ember-back-shell.stl]
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2026-07-31 fix(enclosure): microSD opening was on the wrong edge; buttons swapped; counterbore for cylindrical heads
    JP printed the back shell and found three faults: no microSD opening, the
    button caps reversed, and an opening over the digitizer with nothing behind
    it. All three trace to one cause.
    SD_PLATE was read off the largest back-side SOLID in the vendor STEP -- an
    11.15x14.15mm plate standing 0.50mm off the PCB. A microSD socket is 1.4-2.8mm
    tall, so that was a footprint placeholder (the LCD driver flex). The real
    socket is in the same STEP as a stack of ZERO-THICKNESS FACES, invisible to a
    census of .solids(): X 2.53..17.53, Y 43.70..58.36, 15.00 x 14.66 x 1.85mm.
    Corroborated by the vendor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
    [ember-back-shell.stl, ember-stand.stl]
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2026-07-31 feat(enclosure): debossed labels — SD, MIC, VOL and a power symbol
    JP asked for labels above the cutouts and on the buttons, and chose the IEC 5009
    power symbol for the small cap. That choice resolved the one open decision and
    resolved it better than text would have: a symbol is drawn geometry, so its
    stroke width is set directly rather than inherited from a typeface.
    Four labels, all debossed 0.48mm = 3 * LAYER_H (same three layers as
    BEZEL_DEBOSS), stroke 0.90mm everywhere = the repo's nozzle floor:
    SD flat back, margin strip beside the slit, reads bottom-to-top
    MIC flat back, beside the mic bore
    VOL big cap face -- the microSD side, per JP's bench test
    power small cap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
    [ember-back-shell.stl]
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2026-07-31 docs: an assert that measures the variable you controlled, not the one that binds
    The plan of record for checking the labels was "measure the realised minimum
    stroke and assert it is >= 0.90mm". That check is structurally incapable of
    failing: the stroke is an ARGUMENT to the stroke font, set to 0.90 and then
    asserted to be >= 0.90. It passes because it was constructed to.
    The dimension that actually decides whether a small debossed label prints is the
    counter, and nothing measured it. A 4.5mm SD passes the stroke assert and prints
    as mush: its counter is 0.330mm.
    The intuition points the wrong way, which is why this is worth an entry. Shrinking
    type does not shrink a glyph uniformly -- th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
    [minfeature.py]
2026-07-31 fix(enclosure): layer height is per-part (#26), and the bezel exports print-face-down (#25)
    #26 -- and it understated the defect by three constants.
    PRINT-SHEET's settings table is four columns: bezel 0.16, shell/stand/base 0.20.
    ember_case.py carried a single `LAYER_H = 0.16` commented "PRINT-SHEET's layer
    height for the shell parts", which is false -- 0.16 is the BEZEL's, borrowed and
    relabelled. It survived because it was load-bearing in both directions at once:
    BEZEL_DEBOSS consumed it and was right, while CBORE_DEPTH and LABEL_DEBOSS
    consumed the same constant and were 15.2 and 2.4 layers at the shell's own 0.20.
    "19 layers exactly" and "3 layers at 0.16" were true of the number and fa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
    [ember-back-shell.stl, ember-front-bezel.stl]
2026-07-31 fix(firmware): the chime preempt guard was fixed in the inert half (#15), and #13's instrument could not speak
    Three of the four items 98b086a reported closing were still open. Measuring each
    against the shipped file rather than the commit message gives three answers.
    #15 WAS STILL LIVE. chime_play's preempt guard is two halves and only one declines
    a play: an enumeration in the script's first lambda, and a per-case
    !id(spk)->is_running() in each play action's own condition. The enumeration gates
    chime_until and NOTHING else, because a `return` in an ESPHome lambda ends that
    lambda and does not abort its sibling actions — this file says so in three places
    and it is the bug oracle-verifier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
    [check_chime_guards.py, check_navigability.py]
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2026-07-31 fix(enclosure): grille flare 0.60 -> 0.25 (#28 partial — does NOT fix the print failure)
    ⚠️ #28 IS NOT FIXED BY THIS. Read the numbers before assuming it is.
    JP's stand printed with no front grille: "they didn't print because of too far
    bridging". Measured the actual unsupported spans on the shipped STL --
    downward-facing near-horizontal facets are bridge undersides by definition, with
    their X-coverage resolved into contiguous runs:
    z ~ 32.5 35.283 mm ONE run, no gaps
    z ~ 34.5 37.078 mm ONE run, no gaps
    Zero webs in a 37mm run, against FDM's reliable ~10-20mm. GRILLE_FLARE = 0.60
    exceeds the merge threshold HEX_WEB/sqrt(3) = 0.5196, so the flared mouths
    interpenetr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
    [ember-stand.stl]
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
